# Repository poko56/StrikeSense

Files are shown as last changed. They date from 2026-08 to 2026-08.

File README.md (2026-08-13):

# StrikeSense

ระบบเซนเซอร์ IoT และวิเคราะห์แรงปะทะสำหรับกีฬามวยไทย แบบ Real-time (IoT Muay Thai Telemetry System)

---

## 📚 ศูนย์รวมเอกสาร (Documentation Index)

| หมวดหมู่ | เอกสาร | คำอธิบาย |
| :--- | :--- | :--- |
| **User Manuals** | 🧠 [คู่มือการเทรนโมเดล AI](docs/%E0%B9%80%E0%B8%97%E0%B8%A3%E0%B8%99%E0%B9%82%E0%B8%A1%E0%B9%80%E0%B8%94%E0%B8%A5.md) | ขั้นตอนการเก็บข้อมูล เทรนโมเดล และอัปโหลดเข้าสู่ระบบ |
| | 📖 [คู่มือการใช้งานระบบ](docs/usage-guide.md) | วิธีการติดตั้ง การเชื่อมต่อ Wi-Fi และการใช้งานแดชบอร์ด |
| | 🔌 [คู่มือการอัปโหลดเฟิร์มแวร์](docs/firmware-upload-guide.md) | ขั้นตอนการแฟลชเฟิร์มแวร์ลง ESP32-S3 และ ESP32-C3 |
| | 🔒 [คู่มือ Motion Capture & HTTPS/WSS](docs/motion-capture-https.md) | การตั้งค่า Secure Origin และใบรับรองความปลอดภัย HTTPS |
| **Technical Specs** | 📡 [Protocol Spec](docs/protocol.md) | โครงสร้างแพ็กเกจข้อมูล ESP-NOW และ WebSocket (400Hz) |
| | 🔗 [API Spec](docs/api.md) | REST / WebSocket APIs สำหรับรับส่งข้อมูลแดชบอร์ด |
| | 🤖 [AI Model Technical Guide](docs/ai-model-guide.md) | สถาปัตยกรรม 1D-CNN และระบบคลาสสิฟายท่าทาง |
| | 💻 [Code Walkthrough](docs/code-walkthrough.md) | อธิบายโครงสร้างซอร์สโค้ด และสถาปัตยกรรมซอฟต์แวร์ |
| **Reports & Briefs** | ✨ [System Features](docs/features.md) | รายละเอียดคุณสมบัติ และเกณฑ์การวัดผล |
| | 📊 [AI Presentation Brief](docs/ai-presentation-brief.md) | ข้อมูลสรุปสเปกโครงการสำหรับนำเสนอ |
| | 🛠️ [HTTPS/WSS Debug Guide](docs/ai-handoff-https-wss-debug.md) | ขั้นตอนและวิธีแก้ไขปัญหาการเชื่อมต่อ |
| | 📄 [Progress Report (HTML)](docs/progress-report.html) / [(PDF)](docs/StrikeSense-Progress-Report.pdf) | รายงานความก้าวหน้าโครงการ StrikeSense |

---

## Architecture

```
┌──────────────┐   ESP-NOW   ┌──────────────┐  WiFi AP   ┌──────────────┐
│  Strike Node │ ──400Hz──▶  │  Main Node   │ ─WebSocket▶│  Dashboard   │
│ ESP32-C3     │             │  ESP32-S3    │            │  (Browser)   │
│  + BMI160    │             │  + SD Card   │            └──────────────┘
└──────────────┘             │              │  ┌─────────────┐
       (×2)                  │              │─▶│  AI Team    │
                             └──────────────┘  │  (PC/Cloud) │
                                               └─────────────┘
```

## Project Structure

```
firmware/
  shared/         # Protocol header shared between nodes
  strike-node/    # ESP32-C3 + BMI160 IMU firmware (400Hz ESP-NOW)
  main-node/      # ESP32-S3 hub firmware + embedded PROGMEM dashboard (dashboard_ui.h)
dashboard/        # Web UI source (Vite + Vanilla JS modular source)
ml_pipeline/      # 1D-CNN training, TF.js export & parity verification
tools/            # Cert setup, MediaPipe asset downloader & simulator scripts
hardware/         # PCB + Enclosure 3D CAD files
docs/             # Full system documentation & technical specs
```

## System Status

> [!WARNING]
> **หมายเหตุเกี่ยวกับ Motion Capture (กล้อง):** ปัจจุบันฟีเจอร์ Motion Capture (การใช้กล้องประมวลผล MediaPipe Pose 3D) **ยังไม่สามารถใช้งานได้** (ยังอยู่ในช่วงพัฒนา) ระบบรองรับการวัดผลสดและการวิเคราะห์แรงปะทะผ่านเซนเซอร์ IMU (400Hz) และโมเดล AI เป็นหลัก

| Component | State | Description |
|---|---|---|
| Protocol & Shared Headers | ✅ Done | ESP-NOW 400Hz packet protocol, 4 body slots (protocol.h) |
| Main Node Firmware | ✅ Done | ESP32-S3 AP, HTTPS/WSS, SD card logger, REST API, PROGMEM Web Server |
| Strike Node Firmware | ✅ Done | ESP32-C3 + BMI160, I2C 400kHz, battery measurement & deep sleep |
| Web Dashboard UI | ✅ Done | Real-time 4-slot telemetry, In-browser TF.js AI, Strike physics |
| SD Card Data Logger | ✅ Done | CSV session logging, session manager API & web replay |
| AI Pipeline & Bridge | ✅ Done | 1D-CNN training (`train_model.py`), `retrain.sh`, dynamic SD model storage |
| Motion Capture (Camera Pose) | ⚠️ Not Working | ฟีเจอร์กล้องจับพิกัดโครงร่างยังไม่พร้อมใช้งาน (อยู่ระหว่างพัฒนา) |
| Custom PCB / Enclosure | ⏳ Active | Hardware enclosure and PCB layout files |

## Quick Start (Build & Flash Firmware)

### 1. Build Dashboard UI assets into PROGMEM C-header (`firmware/main-node/dashboard_ui.h`)
```bash
cd dashboard
npm install
npm run build
```

### 2. Compile and flash Main Node firmware

####  สำหรับ macOS:
```bash
cd ../firmware
CLI="/Applications/Arduino IDE.app/Contents/Resources/app/lib/backend/resources/arduino-cli"
FQBN="esp32:esp32:esp32s3:PSRAM=opi,FlashSize=8M,PartitionScheme=default_8MB,CDCOnBoot=cdc,UploadSpeed=921600"
"$CLI" compile --fqbn "$FQBN" main-node
"$CLI" upload -p /dev/cu.usbmodem101 --fqbn "$FQBN" main-node
```

#### ⊞ สำหรับ Windows (Command Prompt / PowerShell):
```cmd
cd ..\firmware
set CLI="C:\Program Files\Arduino IDE\resources\app\lib\backend\resources\arduino-cli.exe"
set FQBN=esp32:esp32:esp32s3:PSRAM=opi,FlashSize=8M,PartitionScheme=default_8MB,CDCOnBoot=cdc,UploadSpeed=921600
%CLI% compile --fqbn %FQBN% main-node
%CLI% upload -p COM3 --fqbn %FQBN% main-node
```

เชื่อม Wi‑Fi `StrikeSense` (pwd: `muaythai123`) แล้วเปิด secure origin ตาม
[คู่มือ motion capture / HTTPS](docs/motion-capture-https.md):
`https://192.168.4.1` สำหรับ Local CA หรือ `https://<hostname>` สำหรับ
Let's Encrypt (ชื่อใน `/tls/hostname.txt`). URL นี้จำเป็นสำหรับกล้องโทรศัพท์และ
WSS.

## เทรนโมเดลจับท่า (AI Model Retraining)

คำสั่งสำหรับนำเข้า CSV และเทรนโมเดลใหม่บนคอมพิวเตอร์:

- **macOS / Linux**: `./ml_pipeline/retrain.sh`
- **Windows**: `.\ml_pipeline\retrain.bat` (หรือดับเบิลคลิกไฟล์ `retrain.bat`)

---

## รายละเอียดโครงการ (Project Details)

### 1. หลักการและเหตุผล (Introduction)
```text
กีฬามวยไทยเป็นศิลปะการต่อสู้ที่ต้องอาศัยความเร็ว ความแม่นยำ และพละกำลัง ในปัจจุบันการฝึกซ้อมยังคงพึ่งพาสัญชาตญาณและประสบการณ์ของ
เทรนเนอร์เป็นหลัก โครงการนี้จึงมีแนวคิดในการนำเทคโนโลยี และปัญญาประดิษฐ์แบบฝังตัว มาพัฒนาระบบสวมใส่อัจฉริยะ (Wearable Device) เพื่อ
ดักจับข้อมูลทางฟิสิกส์ระหว่างการออกอาวุธ ได้แก่ ความเร็ว ความหน่วง และแรงกระแทก โดยแปลงข้อมูลดิบให้เป็นสถิติเชิงตัวเลขที่จับต้องได้
แสดงผลแบบ Real-time เพื่อยกระดับประสิทธิภาพการฝึกซ้อมและการวิเคราะห์สมรรถภาพของนักกีฬา
```

### 2. วัตถุประสงค์ของโครงการ (Objectives)
```
1. เพื่อออกแบบและผลิตชิ้นงานต้นแบบ (Prototype) เซนเซอร์สวมใส่สำหรับนักกีฬามวยไทย
2. เพื่อพัฒนาระบบประมวลผลปัญญาประดิษฐ์ฝังตัว ในการแยกแยะรูปแบบการออกอาวุธ (หมัดตรง, หมัดฮุค, ศอก, เตะ และแทงเข่า)
3. เพื่อพัฒนาระบบรับส่งข้อมูลไร้สายความหน่วงต่ำ (Low-Latency) และหน้ากระดานแสดงผล (Web Dashboard) แบบ Real-time
```

### 3. ภาพรวมสถาปัตยกรรมระบบ (System Overview)
#### ระบบถูกออกแบบมาเพื่อรองรับการเคลื่อนไหวความเร็วสูงในกีฬาต่อสู้ โดยแบ่งการทำงานเป็น 3 ส่วนหลัก:
```
• ชุดเซนเซอร์สวมใส่ : ทำหน้าที่ดักจับข้อมูลทางฟิสิกส์ (ความเร็ว, ความเร่ง, ทิศทาง) ด้วยความถี่สูง และส่งข้อมูลดิบแบบไร้สายทันที เพื่อให้
ตัวอุปกรณ์มีน้ำหนักเบาและตอบสนองไวที่สุด
• ระบบศูนย์กลางประมวลผล : ทำหน้าที่เป็นสมองกลส่วนกลาง รับข้อมูลจากเซนเซอร์ทุกจุดเพื่อนำเข้าสู่โมเดลปัญญาประดิษฐ์ (AI) ในการ
วิเคราะห์รูปแบบการปะทะ คำนวณความแรง และจำแนกประเภทอาวุธ
• ระบบแสดงผล : นำข้อมูลที่ผ่านการวิเคราะห์แล้วมาแสดงผลในรูปแบบกราฟิกและสถิติผ่านเว็บบราวเซอร์
```

### 4. คุณสมบัติเด่นของระบบ (Key Features & Specifications)
```
• ด้านฮาร์ดแวร์ (Hardware Design): อุปกรณ์สวมใส่ถูกออกแบบแผงวงจรให้มีขนาดกะทัดรัด บรรจุในตัวเรือนที่ใช้วัสดุโพลิเมอร์ยืดหยุ่น
ทนทานต่อแรงกระแทก เพื่อความปลอดภัยสูงสุดของผู้สวมใส่และคู่ซ้อม
• ด้านปัญญาประดิษฐ์ (AI & Algorithm): ระบบใช้อัลกอริทึมจำแนกรูปแบบท่าทาง ที่ถูกปรับจูนมาสำหรับกีฬาต่อสู้โดยเฉพาะ เพื่อความ
แม่นยำในการแยกแยะอาวุธ
• ด้านการสื่อสาร (Data Transmission): ใช้โปรโตคอลการรับส่งข้อมูลไร้สายความหน่วงต่ำ ร่วมกับการบริหาร
• จัดการคิวข้อมูลแบบขนาน (Multi-threaded Processing) ทำให้สามารถแสดงผลสถิติบนหน้าจอได้ทันทีโดยไม่เกิดความล่าช้า
```
#### ด้านการวิเคราะห์และแสดงผลข้อมูล (Data Analytics & Insights Dashboard): หน้าจอแสดงผลถูกออกแบบมาเพื่อเปลี่ยนข้อมูลตัวเลขทาง
ฟิสิกส์ให้กลายเป็นสถิติเชิงลึกที่เข้าใจง่ายสำหรับโค้ชและนักกีฬา โดยจะครอบคลุมการแสดงผลข้อมูลดังต่อไปนี้:

##### หน้าจอหลักสำหรับการฝึกซ้อม (Real-time Training Dashboard):
```
• ตัววัดพลังหมัดและหน้าแข้ง (Live Impact Power): แสดงเกจวัดระดับความรุนแรงของการปะทะในรูปแบบเปอร์เซ็นต์ หรือหน่วยดัชนีชี้
วัด (Score) ทันทีเมื่อเกิดการปะทะเป้าหมาย
• ระบบไฟสถานะระบุท่าทาง (Strike Indicator): แสดงสัญลักษณ์หรือกราฟิกรูปท่าทางมวยไทยบนหน้าจอที่จะสว่างขึ้นตามอาวุธที่นักมวย
ออกจริง (เช่น ตัวอักษรคำว่า "KNEE" หรือ "HOOK" จะกะพริบขึ้นมาทันทีเมื่อนักมวยแทงเข่าหรือฮุคเข้าเป้า)
• ตัวพล็อตแนวกราฟความเร็ว (Real-time Velocity Graph): เส้นกราฟความชันที่พลอตสดบนหน้าจอเพื่อแสดงทิศทาง ความเร่ง และ
การทรงตัวของแขนขาในขณะออกอาวุธ
```
##### หน้าจอสรุปผลและสถิติเชิงลึก (Performance & Metrics Analytics):
```
• สรุปอัตราส่วนอาวุธ (Striking Distribution Pie Chart): กราฟวงกลมแสดงสัดส่วนการใช้อาวุธของการซ้อมในรอบนั้นๆ (ตัวอย่าง: ใช้
หมัด 40%, เตะ 30%, เข่า 30%) ช่วยให้โค้ชวิเคราะห์ได้ว่านักมวยใช้ร่างกายสมดุลหรือไม่ หรือติดพฤติกรรมการออกอาวุธแบบใดแบบหนึ่ง
มากเกินไป
• ตัวนับจำนวนครั้งรวมแยกประเภท (Strike Counter): กล่องตัวเลขดิจิทัลขนาดใหญ่สรุปยอดรวมการออกอาวุธ เช่น หมัดตรง: 52 ครั้ง,
หมัดฮุค: 18 ครั้ง, เตะ: 35 ครั้ง, แทงเข่า: 20 ครั้ง
• ดัชนีคะแนนพละกำลังสูงสุด (Peak Power Record): บันทึกสถิติ "ที่สุดของการซ้อม" เช่น อาวุธที่รุนแรงที่สุดในรอบวัน (Max Impact)
เกิดขึ้นในนาทีที่เท่าไหร่ และเป็นอาวุธประเภทใด
• ตัววัดความเสถียรและความทนทาน (Stamina & Consistency Tracker): แสดงกราฟเปรียบเทียบความแรงตั้งแต่หมัดแรกจนถึงหมัด
สุดท้าย เพื่อวิเคราะห์ว่าเมื่อเวลาผ่านไป นักมวยแรงตกหรือไม่ หรือยังคงรักษาความรุนแรงของการปะทะได้สม่ำเสมอเพียงใด
```

### 5. ขอบเขตการดำเนินงาน (Scope of Work) - Phase 1
สำหรับการพัฒนาในเฟสที่ 1 (Proof of Concept) จะครอบคลุมปริมาณงานดังต่อไปนี้:
```
• ผลิตชุดเซนเซอร์สวมใส่: จำนวน 2 ชุด (สามารถกำหนดจุดติดตั้งได้ เช่น มือและหน้าแข้ง)
• ผลิตระบบศูนย์กลางประมวลผล: จำนวน 1 ชุด
```

### 6. รายการส่งมอบ (Deliverables)
```
1. ชิ้นงานฮาร์ดแวร์ต้นแบบ (อุปกรณ์สวมใส่ 2 ชุด และ ตัวรับสัญญาณ 1 ชุด)
2. สิทธิ์การเข้าใช้งานระบบหน้าจอแสดงผล (Web Dashboard) ตลอดช่วงระยะเวลาการทดสอบ
```

### 7. เงื่อนไขและข้อจำกัดของโครงการต้นแบบ (Terms & Conditions)
```
• ด้านความแม่นยำ: ชิ้นงานเป็นเวอร์ชันทดสอบแนวคิด (Proof of Concept) ความแม่นยำในการจำแนกท่าทางด้วย AI จะอยู่ในเกณฑ์เฉลี่ย
80-85% ภายใต้สภาวะการควบคุมการทดสอบ
• การปรับแก้ชิ้นงาน: ครอบคลุมการปรับแก้ไขการออกแบบโครงสร้างภายนอกของตัวอุปกรณ์ (Enclosure Design) สูงสุดจำนวน 2 ครั้ง
• สิทธิบัตรและทรัพย์สินทางปัญญา (Intellectual Property): การส่งมอบนี้ครอบคลุมเฉพาะชิ้นงานต้นแบบทางกายภาพและสิทธิ์การใช้
งานแพลตฟอร์มเท่านั้น ไม่รวมถึงการส่งมอบซอร์สโค้ด (Source Code), อัลกอริทึมวิเคราะห์ข้อมูล (AI Model), รูปแบบลายวงจร
อิเล็กทรอนิกส์ (PCB Gerber) และไฟล์พิมพ์เขียวสามมิติ (3D CAD) หากมีความประสงค์นำไปใช้ในการผลิตเชิงพาณิชย์ จะต้องมีการทำ
ข้อตกลงและประเมินมูลค่าลิขสิทธิ์เพิ่มเติมในเฟสถัดไป
```

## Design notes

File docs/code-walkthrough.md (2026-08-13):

# StrikeSense — Code Walkthrough (เข้าใจโค้ดแบบละเอียด)

เอกสารนี้เดินตาม **เส้นทางของข้อมูล 1 sample** ตั้งแต่เซนเซอร์จนถึงหน้าจอ แล้วต่อด้วย
**Data Logger → ML → Inference** เพื่อให้เห็นภาพว่าโค้ดแต่ละไฟล์ต่อกันอย่างไร

เอกสารอ้างอิงอื่น: [README](../README.md) (ภาพรวม) · [protocol.md](protocol.md) (ESP-NOW) · [api.md](api.md) (REST/WS) · [features.md](features.md) (ฟีเจอร์ UI)

---

## 0. แผนที่ระบบ 3 ส่วน

```
Strike Node (ESP32-C3)        Main Node (ESP32-S3)              Dashboard (Browser)
─────────────────────        ────────────────────              ───────────────────
IMU 400Hz ─┐                  ESP-NOW RX ─┐                     WebSocket ─┐
           │ pack 8 samples              │ queue → loop()                 │ decodeFrame()
           └─ ESP-NOW ──────▶  onRecv() ─┘  ├─ SD logger        ingestBatch()─┤
                                            ├─ WS broadcast ───▶ analyzer ────┤
                                            └─ counters         render / logger
```

- **Strike Node** = [`firmware/strike-node/strike-node.ino`](../firmware/strike-node/strike-node.ino) — อ่าน IMU, แพ็กเป็น packet, ยิง ESP-NOW
- **Main Node** = [`firmware/main-node/main-node.ino`](../firmware/main-node/main-node.ino) — ตัวรวมศูนย์ (ไฟล์เดียว, แบ่งเป็น `namespace`)
- **Dashboard** = [`dashboard/src/*.js`](../dashboard/src) — Vanilla JS แบบ modular
- **สัญญา (contract)** ที่ผูกทุกส่วน = โครงสร้าง packet ใน [`firmware/shared/protocol.h`](../firmware/shared/protocol.h)

---

## 1. ฝั่งเฟิร์มแวร์ Main Node — แบ่งด้วย `namespace`

`main-node.ino` เป็นไฟล์เดียวแต่จัดระเบียบด้วย namespace แต่ละอันคือ "โมดูล" ที่มีหน้าที่ชัดเจน:

| namespace | หน้าที่ | state สำคัญ |
|---|---|---|
| `Session` | จำ node, นับ packet, จับ session start/stop | `g_nodes[]`, `g_stats` |
| `EspNowRx` | รับ ESP-NOW ใน callback → ยัดเข้า FreeRTOS queue | `g_queue` |
| `EspNowTx` | ยิง time-sync + คำสั่งไป node | broadcast peer |
| `SdLogger` | เขียน CSV ลง SD แบบ buffered | `g_buf[16KB]` |
| `StatusLed` | ไฟ NeoPixel บอกสถานะ | state machine |
| `WebServerApp` | HTTP + WebSocket + REST | `g_http`, `g_ws` |

**ทำไมต้องใช้ queue?** — ESP-NOW `onRecv()` รันใน **ISR context** (interrupt) ห้ามทำงานหนัก/ห้าม block
ดังนั้น callback แค่ก๊อปข้อมูลใส่ queue แล้วจบ ส่วนงานหนัก (เขียน SD, ส่ง WS) ไปทำใน `loop()` ปกติ

### 1.1 เส้นทางของ 1 packet ในเฟิร์มแวร์

```c
// (1) ISR: รับ ESP-NOW → ก๊อปเข้า queue เท่านั้น  [EspNowRx::onRecv]
static void onRecv(const esp_now_recv_info_t* info, const uint8_t* data, int len) {
    if (data[1] == PKT_IMU_BATCH) {
        ImuFrame frame;                              // stack struct
        memcpy(frame.samples, pkt->samples, ...);    // ก๊อป 8 samples
        xQueueSendFromISR(g_queue, &frame, nullptr); // ← ส่งต่อ ไม่ประมวลผลใน ISR
    }
}

// (2) loop(): drain queue → 3 ปลายทาง  [void loop]
while (drained < 32 && EspNowRx::nextFrame(frame, 0)) {
    Session::noteImuFrame(frame.sampleCount);        // นับสถิติ
    if (Session::isActive()) SdLogger::logFrame(frame); // เขียน SD (ถ้ากำลัง record)
    WebServerApp::broadcastImuFrame(frame);          // ส่งเข้า WebSocket ทุก client
}
```

### 1.2 การ broadcast เข้า WebSocket — จุดที่กำหนด "รูปแบบ binary frame"

`WebServerApp::broadcastImuFrame()` แพ็ก frame เป็น binary 16-byte header + N×12-byte samples:

```c
buf[0]=0x01; buf[1]=slot; buf[2]=sampleCount; buf[3]=rssi;
memcpy(buf+4,  &seq, 4);
memcpy(buf+8,  &recvMs, 4);
memcpy(buf+12, &nodeUs, 4);
memcpy(buf+16, samples, sampleCount*12);   // ax,ay,az,gx,gy,gz = int16 ×6
g_ws.binaryAll(buf, 16 + sampleCount*12);
```

> ⚠️ **นี่คือ contract กับ dashboard** — ถ้าแก้ layout นี้ ต้องแก้ `decodeFrame()` ใน `ws.js` ให้ตรงกัน

### 1.3 Dashboard ถูก serve จากไหน

`registerRoutes()` ผูก `/` และ `/index.html` เข้ากับ `DASHBOARD_HTML` (PROGMEM string ใน `dashboard_ui.h`):

```c
auto sendDashboard = [](AsyncWebServerRequest* req) {
    req->send(req->beginResponse_P(200, "text/html", DASHBOARD_HTML));
};
```
`dashboard_ui.h` เป็นไฟล์ที่ **generate อัตโนมัติ** จาก `npm run build` (ห้ามแก้มือ)

---

## 2. ฝั่ง Dashboard — โมดูล Vanilla JS

| ไฟล์ | หน้าที่ |
|---|---|
| [`main.js`](../dashboard/src/main.js) | Entry — ต่อ state ↔ ws ↔ ui ↔ timer ↔ logger ↔ AI classifier เข้าด้วยกัน |
| [`ws.js`](../dashboard/src/ws.js) | ถอด binary WebSocket frame → sample objects + reconnect |
| [`analyzer.js`](../dashboard/src/analyzer.js) | ตรวจจับ "หมัด" จากสัญญาณ (threshold + refractory) |
| [`motioncapture.js`](../dashboard/src/motioncapture.js) | โหลดโมเดล TensorFlow.js AI *(ฟีเจอร์กล้อง MediaPipe Pose ยังไม่เปิดใช้งาน)* |
| [`physics.js`](../dashboard/src/physics.js) | คำนวณฟิสิกส์แรงปะทะ (Live Impact Power, Velocity, Kinetic Energy) |
| [`strikescore.js`](../dashboard/src/strikescore.js) | ประเมินดัชนีคะแนนความแม่นยำและแรงปะทะ (0–100 Strike Score) |
| [`posemath.js`](../dashboard/src/posemath.js) | เวกเตอร์และฟังก์ชันคำนวณเรขาคณิตของข้อต่อร่างกาย 3D |
| [`rigclock.js`](../dashboard/src/rigclock.js) | ตัวซิงก์เวลาความละเอียดสูงระหว่าง IMU และกล้อง MediaPipe |
| [`rigorigin.js`](../dashboard/src/rigorigin.js) | ตัวตั้งพิกัดอ้างอิงของจุดกำเนิดและทิศทางเซนเซอร์ |
| [`state.js`](../dashboard/src/state.js) | store กลาง + pub/sub (`subscribe`/`scheduleRender`) |
| [`ui.js`](../dashboard/src/ui.js) | render DOM จาก state |
| [`timer.js`](../dashboard/src/timer.js) | round timer / boxing stopwatch |
| [`logger.js`](../dashboard/src/logger.js) | **Data Logger** — เก็บ raw IMU + label → CSV |

### 2.1 `decodeFrame()` — ตรงข้ามกับ `broadcastImuFrame()`

```js
// ws.js — อ่าน int16 little-endian แล้วหารด้วย scale ให้เป็นหน่วยจริง
const ACCEL_LSB_PER_G  = 2048;    // ±16g range
const GYRO_LSB_PER_DPS = 16.4;    // ±2000 dps range
samples[i] = {
  ax: dv.getInt16(off,   true) / ACCEL_LSB_PER_G,   // g
  gx: dv.getInt16(off+6, true) / GYRO_LSB_PER_DPS,  // deg/s
  ...
};
logSensorData(samples[i], slot);   // ← ป้อน Data Logger (no-op ถ้าไม่ได้ record)
ingestBatch({ slot, samples, ... }); // ← ป้อน analyzer + state
```

### 2.2 State เป็น pub/sub

`ws`/`analyzer`/`timer` เขียนลง `state` แล้วเรียก `scheduleRender()` → `subscribe(renderAll)` ใน `main.js`
ทำให้ทุกอย่าง render ผ่าน `requestAnimationFrame` loop เดียว (ไม่ render ซ้ำซ้อน)

---

## 3. Data Logger — โหมดเก็บข้อมูลฝึก AI (developer mode)

**เป้าหมาย:** เก็บ raw IMU + label ท่า → CSV → เอาไปเทรนบนคอมพิวเตอร์

### 3.1 การ wire 3 จุด
```
main.js   : initLogger()              // ผูกปุ่ม/ค่า panel ตอน bootstrap
ws.js     : logSensorData(sample,slot)// เรียกทุก sample @400Hz
index.html: <select id="strikeLabel"> // dropdown ท่าแบบจัดกลุ่ม
```

### 3.2 Label เข้ารหัสแบบ "หลักสิบ" (tens-scheme)
```
10-13 หมัด PUNCH   (10 Jab, 11 Cross, 12 Hook, 13 Uppercut)
20-25 ศอก ELBOW    (ตี/ตัด/งัด/พุ่ง/กระทุ้ง/กลับ)
30-33 เข่า KNEE    (ตรง/เฉียง/ตัด/ลอย)
40-44 เตะ KICK     (ตรง/เฉียง/ตัด/กลับ/เหวี่ยงกลับ)
50-52 ถีบ TEEP     (ตรง/ข้าง/กลับหลัง)
```
**กุญแจสำคัญ:** `coarse_class = floor(label/10) - 1` → 0..4 (หมัด/ศอก/เข่า/เตะ/ถีบ)
ทำให้ logger เก็บ **ละเอียด** แต่โมเดลเทรนได้ทั้งแบบ **หยาบ 5 คลาส** และแบบ **ละเอียด ~20 ท่าย่อย**

### 3.3 CSV ที่ได้
```
ax,ay,az,gx,gy,gz,slot,label
-0.1230,0.9840,0.0210,12.300,-4.100,0.800,2,41
                                        │  └ fine label (41 = เตะเฉียง)
                                        └ slot: 0=ว่าง 1=L-hand 2=R-hand 3=L-shin 4=R-shin
```
`slot` มาจาก frame header (บอกว่าอวัยวะไหนออกอาวุธ) ใช้กันไม่ให้ window เทรนข้ามแขน/ขา

---

## 4. ML Pipeline — [`ml_pipeline/train_model.py`](../ml_pipeline/train_model.py)

```
CSV หลายไฟล์ → load_dataset()          (แปะ file_id กันข้ามไฟล์)
             → make_windows()          (sliding window ไม่ข้าม file/slot/class)
             → standardise             (mean/std จาก train เท่านั้น)
             → build_model()           (1D-CNN: Conv×3 → GAP → Dense)
             → evaluate                (accuracy + confusion_matrix.png)
             → export_tfjs_json()      (strike_web_model_fine.json สำหรับเบราว์เซอร์)
             → export_header()         (strike_model_fine.h สำหรับ C++ fallback)
```

---

## 5. การวิเคราะห์โมเดลแบบ In-Browser TensorFlow.js 🧠

ระบบ StrikeSense ใช้สถาปัตยกรรม **In-Browser Machine Learning (1D-CNN + TensorFlow.js)**:

1. **การโหลดโมเดลแบบไดนามิก**:
   - เมื่อเปิดแดชบอร์ด `motioncapture.js` จะดึงไฟล์โมเดลจาก `/api/model` บน Main Node SD Card (`/models/strike_web_model_fine.json`)
   - ผู้ใช้สามารถอัปโหลดโมเดลใหม่ผ่าน Web Dashboard ได้ทันทีโดยไม่ต้อง re-flash ESP32

2. **การทำงานของ AI Engine**:
   - สัญญาณ IMU ความถี่ 400Hz ถูกตัดหน้าต่าง (sliding window 100 samples / 250ms)
   - โมเดล 1D-CNN ทำงานร่วมกับ **Gaussian priors (`physics.js`)** และ **Strike Score Calculator (`strikescore.js`)** ในการจำแนกประเภทท่าและประเมินพลังหมัด/แข้ง

---

## 6. สรุป contract ที่ห้ามหลุด (ถ้าแก้ ต้องแก้ทั้งคู่)

| Contract | ฝั่ง A | ฝั่ง B |
|---|---|---|
| ESP-NOW packet layout | `protocol.h` / strike-node | `onRecv()` main-node |
| WebSocket binary frame | `broadcastImuFrame()` | `decodeFrame()` ws.js |
| IMU scale (2048/16.4) | strike-node config | `ws.js` + `train_model.py` |
| Label tens-scheme | `index.html` optgroup | `logger.js` + `train_model.py` |
| Model JSON Format | `train_model.py` export | `motioncapture.js` + `/api/model` |

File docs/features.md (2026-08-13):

# StrikeSense — Feature Catalog

> สรุปฟีเจอร์ทั้งหมดของ Web Dashboard (เวอร์ชันปัจจุบัน · v0.2)
> Dashboard ฝัง PROGMEM อยู่ใน Main Node firmware · เปิดผ่าน
> secure origin: `https://192.168.4.1` สำหรับ Local CA หรือ
> `https://<hostname>` สำหรับ Let's Encrypt หลัง provision certificate (ดู
> [motion-capture-https](motion-capture-https.md))
> Dev mode: `cd dashboard && npm run dev` → `http://localhost:5173/?demo=1`

---

## ภาพรวม

Dashboard เป็น Single-Page App (Vite · vanilla JS · PROGMEM embedded) ที่:
1. รับข้อมูล IMU ความถี่ 400 Hz จาก Strike Nodes ครบทั้ง 4 จุด (มือซ้าย, มือขวา, แข้งซ้าย, แข้งขวา) ผ่าน WebSocket
2. วิเคราะห์และตรวจจับการออกอาวุธแบบ real-time ด้วย **In-browser TensorFlow.js 1D-CNN AI Model** ร่วมกับ **Gaussian priors physics engine**
3. *[ยังไม่พร้อมใช้งาน]* **MediaPipe Pose 3D Landmarker (Dual Camera mode)** — ฟีเจอร์กล้องจับพิกัดโครงร่างยังไม่เปิดใช้งาน (อยู่ระหว่างพัฒนา)
4. คำนวณ performance metrics (Live Impact Power, Velocity Graph, Strike Score 0-100, Stamina Tracker)
5. ควบคุมการบันทึก session, รอบการซ้อม (Round timer), และจัดการคลังโมเดล AI (`/api/models`) บน SD Card

**Design**: "Fight Card" — ฟอนต์ Bebas Neue + IBM Plex Mono, สี ink/paper + accent แดง Muay Thai, hairline borders, asymmetric 3-rail layout — ไม่ใช่ generic glass-morphism dashboard

---

## 1 · Live Monitoring

| ฟีเจอร์ | รายละเอียด | ที่อยู่ |
|---|---|---|
| Connection pill | LIVE WS / OFFLINE / DEMO MODE — สีเขียว/แดง/น้ำเงิน | Topbar |
| Live IMU stream | ax, ay, az, gx, gy, gz ที่ 400 Hz แปลงเป็น g/°·s⁻¹ แล้ว | WebSocket frame |
| Sample rate วัดจริง | Hz วัดสด ทุก 1 วินาที | System tab |
| Bandwidth | kbps WS payload จริง | System tab |
| Sample latency check | recvTimestampMs ใน header เปรียบ wall clock | (เห็นใน packet) |
| RSSI ต่อ node | dBm + bar graph 4 ขั้น | Sensors tab |
| Battery % ต่อ node | bar + warning เมื่อ <20% | Sensors tab |
| WS clients ออนไลน์ | จำนวน clients ที่ดู dashboard | System tab |
| Uptime / Heap / PSRAM | จาก `/api/status` polling 1.5s | Topbar + System |

## 2 · Strike Detection & Analysis

| ฟีเจอร์ | รายละเอียด |
|---|---|
| Threshold detector | \|a\| > `thresholdG` (default 3.0g, ปรับได้ live) |
| Per-slot refractory | กันนับซ้ำ — default 250ms ปรับได้ |
| Heuristic classification | jab / cross / hook / uppercut / elbow / kick / roundhouse / knee / push |
| Per-strike data | id, slot, type, peakG, peakDps, recoverMs, sessionMs, round |
| Force histogram | 4 ช่วง: 1-3g / 3-5g / 5-10g / 10+g |
| Strike distribution | นับตาม type — bar graph เรียงจากมาก→น้อย |
| Sparkline ต่อ slot | canvas waveform 3 วินาทีล่าสุด พร้อมเส้น threshold |

## 3 · Body Diagram (Hit Zones)

| โหมด | รายละเอียด |
|---|---|
| **LIVE** | 4 zones (LH/RH/LS/RS) เปลี่ยนสีตามสถานะ: dim → assigned → live (cyan) → hit (flash แดง 250ms) |
| **HEATMAP** | สีแดงเข้ม 5 ระดับ ตามจำนวนหมัดสะสมต่อ slot |
| Click-to-assign | คลิก zone → assign node ว่างไปที่ slot นั้น (POST `/api/nodes/assign`) |
| Belt | แถบแดง muay thai ที่เอว — ไม่ใช่ interactive |

## 4 · Round Timer (Boxing Style)

| ฟีเจอร์ | รายละเอียด |
|---|---|
| Circular dial | SVG ring แสดง progress ของ phase ปัจจุบัน + tick countdown |
| Presets | 3×3 / 5×3 / 3×2 / 12×3 / Stopwatch (free) / Custom |
| Phases | idle → work → rest → work → ... → done — สลับอัตโนมัติ |
| Auto-rec | checkbox: เริ่ม REC ทุกครั้งที่เข้า work, หยุดเมื่อ done |
| Manual controls | RESET, SKIP, click dial = start |
| Stopwatch mode | นับขึ้น ไม่มีรอบ/พัก — สำหรับ shadow / freestyle |
| Visual rest indicator | สี dial เปลี่ยนเป็น amber ตอน rest |

## 5 · Session Recording

| ฟีเจอร์ | รายละเอียด |
|---|---|
| REC button | ปุ่มแดงใหญ่ใต้ dial — toggle start/stop |
| Athlete name | input + datalist เก็บ 10 ชื่อล่าสุด |
| Drill type | shadow / pad / bag / spar / free |
| Session timer | นับเวลาตั้งแต่เริ่ม (anchor จาก backend durationMs) |
| Coach markers | ปุ่ม `+ MARKER` (หรือกด M) ใส่ note timestamped |
| REC pill | บน topbar — STANDBY / REC LIVE / REST |
| SD logging status | warning toast ถ้า SD card ไม่พร้อม |

## 6 · Performance Metrics

| Metric | หน่วย | คำนวณจาก |
|---|---|---|
| **Peak G** | g | max ของ peak |
| **Avg G** | g | mean ของ peakG |
| **Strikes** | count | จำนวน strike |
| **SPM** (Strikes Per Minute) | /min | strikes / minutes since start |
| **Time-on-target** | % | % ของ 30s ล่าสุดที่ rms > threshold·0.25 |
| **Work** | kJ | Σ 0.5·m·v² (mass: arm 4kg / leg 12kg) |
| **Asymmetry L:R** | ratio + bar | leftCount / (left+right) |
| **Fatigue Index** | % + label | (first half avg - second half avg) / first |
| **Power CV** | % | std/mean ของ peakG (consistency) |
| **Session duration** | hh:mm:ss | wall - startedAtMs |

## 7 · Round-by-Round Summary

| ข้อมูลต่อยก | รายละเอียด |
|---|---|
| Strikes | จำนวนหมัดในยกนั้น |
| Peak G | peak ของยก |
| Avg G | average ของยก |
| Fatigue % | decay ภายในยก (first half vs second half) |
| Asymmetry | L vs R ในยก |
| Current row | highlight ยกที่กำลัง work อยู่ (สีแดงอ่อน) |

## 8 · Session Timeline Strip

| ฟีเจอร์ | รายละเอียด |
|---|---|
| Horizontal strip | span = ระยะเวลา session (อย่างน้อย 60s) |
| Strike dots | แท่งแนวตั้ง สีตาม slot, ความสูงตาม peakG |
| Marker triangles | สีทอง — แสดง coach markers |
| Click strike → modal | เปิด detail modal ของหมัดนั้น + neighbours |
| Axis labels | 0:00 / mid / end |

## 9 · Strike Log

| ฟีเจอร์ | รายละเอียด |
|---|---|
| Columns | #, Time, Round, Slot, Type, Peak·g, ω·°/s, Recovery·ms |
| Filter chips | ALL / LH / RH / LS / RS (กดเลข 1-4 ก็ได้) |
| Newest flash | row ล่าสุดมี animation รัศมีแดง 1 วิ |
| Click → detail modal | drill-down รายตัว |
| Slot tag | สีแยก 4 slots (cyan/orange/green/purple) |
| Clear button | ล้าง log + reset counters |
| Max 80 rows displayed | rolling buffer 500 ใน state |

## 10 · Strike Detail Modal

| ข้อมูล | รายละเอียด |
|---|---|
| Peak G, ω | ใหญ่เด่น |
| Slot | full name |
| Round | R1, R2, ... |
| Session time | hh:mm:ss ของหมัด |
| Recovery | ms ตั้งแต่หมัดก่อน |
| Neighbours | หมัด ±3 ใน slot เดียวกัน |

## 11 · Training Goals

| ฟีเจอร์ | รายละเอียด |
|---|---|
| Target strikes | ตั้งจำนวนหมัด (default 100) |
| Target peak G | peak ต่ำสุดที่ต้องทำ (default 8g) |
| Target SPM | (เก็บไว้, ใช้ขยายต่อ) |
| Progress bars | 2 แท่ง — strikes vs target, peak vs target |
| Goal status | %, "keep going", หรือ "✓ COMPLETED at hh:mm" |
| Auto-detect completion | log activity feed + lock until reset |

## 12 · Coach Markers

| ฟีเจอร์ | รายละเอียด |
|---|---|
| Add marker | ปุ่ม `+ MARKER` หรือกด M — prompt note |
| Display | บน timeline (triangle ทอง) + list ใน Sensors tab |
| Delete marker | ปุ่ม ✕ ในรายการ |
| Auto-label | "Round X · note" ถ้าไม่ใส่ |
| Session-relative time | hh:mm:ss นับจากเริ่ม session |

## 13 · Activity Feed

| Event | สี | ตัวอย่าง |
|---|----|---|
| REC start/stop | แดง | "▶ Recording started · 1738291201" |
| Round transition | แดง | "🥊 Round 2 · WORK" |
| Marker added | ทอง | "📍 Round 1 · note @ 45.2s" |
| Goal completed | เขียว | "🏆 Goal reached · 100 strikes" |
| Battery warning | amber | "🪫 Battery low: EE:01 18%" |
| Slot assign | แดง | "📍 EE:01 → Right Hand" |
| Relative time | — | "5s", "2m", "1h" |
| Cap 20 entries | — | rolling buffer |

## 14 · Sensors Management

| ฟีเจอร์ | รายละเอียด |
|---|---|
| Node card list | สด: เขียว | นิ่ง (>3s): แดง opacity 65% |
| MAC | full address |
| Slot dropdown | เปลี่ยน live → POST `/api/nodes/assign` |
| Signal | bar graph 4 ขั้น + dBm |
| Battery | bar (เขียว/amber/แดง) + % |
| RX / Gaps / FW | packets received, seq gaps, firmware version |
| Markers panel | (ใน tab เดียวกัน) |

## 15 · Session Library

| ฟีเจอร์ | รายละเอียด |
|---|---|
| List sessions | GET `/api/sessions` polling 8s |
| Search | filter by id substring |
| Stats summary | total count, total size, SD used/cap |
| Download CSV | `<a download>` → GET `/api/sessions/{id}` |
| Preview (VIEW) | modal: id, size, date, ปุ่ม download |
| Delete | confirm → DELETE `/api/sessions/{id}` |
| Compare 2 sessions | checkbox + COMPARE button → modal (id/size/date diff) |
| Sort | mod time descending |

## 16 · System & Diagnostics

| Section | รายละเอียด |
|---|---|
| **Main Node** | IP, SSID, uptime, heap free, PSRAM free, WS clients |
| **ESP-NOW** | packets RX, dropped, sample rate Hz, bandwidth kbps |
| **Detection tuning** | slider threshold (1.5-10g), refractory (100-800ms) — บันทึก localStorage |
| **SD card** | progress bar + used/free MB, สีเปลี่ยนตาม % (>70 amber, >90 red) |
| **About** | build stamp, browser UA, dashboard version |

## 17 · UI Modes

| Mode | กดที่ | บันทึก |
|---|---|---|
| Theme dark/light | ◐ icon หรือ T | localStorage |
| Body live/heatmap | seg button หรือ H | localStorage |
| Fullscreen | ⛶ icon หรือ F | runtime + Fullscreen API |
| Stopwatch mode | MODE dropdown | localStorage |

## 18 · Keyboard Shortcuts

| Key | Action |
|-----|---|
| **Space** | REC start/stop |
| **R** | Reset round timer |
| **S** | Skip phase |
| **M** | Add coach marker |
| **F** | Toggle fullscreen presentation |
| **H** | Toggle body heatmap |
| **T** | Toggle theme |
| **0** | Filter strike log: all slots |
| **1**–**4** | Filter strike log: slot 1-4 |
| **Esc** | Close modal |
| **?** หรือ **/** | Show shortcuts modal |

## 19 · Persistence (localStorage)

| Key | Value |
|-----|---|
| `ss:theme` | 'dark' \| 'light' |
| `ss:tuning` | { thresholdG, refractoryMs } |
| `ss:goals` | { targetStrikes, targetPeakG, targetSpm } |
| `ss:athlete` | last athlete name |
| `ss:athleteHistory` | array of 10 recent names → datalist |
| `ss:drill` | last drill type |
| `ss:preset` | last round preset |
| `ss:modes` | { bodyHeatmap, stopwatch } |

## 20 · Demo / Simulator Mode

เปิด `?demo=1` ใน URL:
- สร้าง 4 fake nodes (LH/RH/LS/RS, battery 18-92%)
- 3 fake sessions ใน library
- Baseline noise ทุก 1 วินาที + strike สุ่มทุก 1.1 วินาที (peak 3.5-13g)
- API ทั้งหมด stub ด้วย demoApi
- ใช้ดูว่า UI ทำงานอย่างไรโดยไม่ต้องเสียบบอร์ด

---

## เทคโนโลยี

| Layer | ใช้ |
|---|-----|
| Build | Vite 8 + `vite-plugin-singlefile` → ผลลัพธ์ 1 ไฟล์ HTML 88KB / gzip 24.5KB |
| Bundle to firmware | `dashboard/build-cpp.js` → `firmware/main-node/dashboard_ui.h` (PROGMEM string) |
| Frontend | Vanilla JS modules · no framework · ES2022 |
| Charts | SVG inline + Canvas 2D (sparklines) — ไม่ใช้ Chart.js/uPlot ใน build จริง |
| Modal | native `<dialog>` |
| Styling | Plain CSS · CSS variables theming · no SASS/Tailwind |
| Fonts | Bebas Neue, IBM Plex Mono, Inter (Google Fonts) |
| Storage | `localStorage` ตรงๆ (ผ่าน `persist.js` wrapper) |

### File structure

```
dashboard/
├── index.html              entry HTML (semantic + IDs ตรง JS)
├── style.css               design system "Fight Card" + light theme + fullscreen
├── build-cpp.js            post-build: ฝัง dist เข้า firmware header
├── vite.config.js          singleFile plugin
└── src/
    ├── main.js             entry — wires modules + persistence + keyboard
    ├── state.js            central state + subscribe / scheduleRender
    ├── api.js              REST wrapper (BASE = 192.168.4.1 บน localhost)
    ├── ws.js               binary frame decoder + reconnect backoff
    ├── analyzer.js         strike detect + metrics + per-round + markers
    ├── timer.js            round state machine + stopwatch
    ├── ui.js               render functions + DOM event wiring + modals
    ├── modal.js            native <dialog> helper
    ├── persist.js          localStorage wrapper
    └── demo.js             simulator + demoApi override
```

### REST endpoints used

| Method | Path | ใช้ทำอะไร |
|---|---|---|
| GET | `/api/status` | poll system + session snapshot (1.5s) |
| GET | `/api/nodes` | poll connected Strike Nodes (2s) |
| POST | `/api/nodes/assign` | assign slot {mac, slot} |
| POST | `/api/session/start` | start REC {athlete} → {sessionId, sdLogging} |
| POST | `/api/session/stop` | stop REC |
| GET | `/api/sessions` | list SD recordings (8s) |
| GET | `/api/sessions/{id}` | download CSV (text/csv attachment) |
| DELETE | `/api/sessions/{id}` | remove SD recording |
| WS | `/ws` | binary IMU frames (16 B header + 12 B × N samples) |

---

## ไม่รวม (intentionally skipped)

| ที่ตัด | เหตุผล |
|---|---|
| AI live classification / form score | จะใช้โมเดลจาก AI team ภายหลัง |
| Audio (bell, voice, beep) | user ระบุไม่ทำ |
| Identify LED blink / Restart node remote | ต้องเพิ่ม firmware endpoint ก่อน |
| OTA firmware update | ต้อง firmware support |
| Strike contact duration จริง | ต้องการ segment tracker ใน firmware |
| Polar chart / FFT / 3D trajectory | over-engineered สำหรับการใช้งานจริง |
| Multi-Main-Node management | scope สำหรับ 1 hub |
| Heart-rate sensor integration | ต้องการ external hardware |
| ระบบ multi-athlete พร้อมกัน | scope = 1 athlete per session |

---

## เวอร์ชัน

- **v0.1** — โครงสร้างพื้นฐาน · Premiere Pro-style UI · core polling + WS + REC
- **v0.2 (ปัจจุบัน)** — Rewrite "Fight Card" design · 16+ ฟีเจอร์ round 2:
  body diagram + heatmap, round timer, sparklines, markers, timeline strip,
  goals, per-round table, activity feed, compare, modals, persistence,
  keyboard, theme, fullscreen, stopwatch, demo mode

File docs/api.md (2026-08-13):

# StrikeSense Main Node API

Secure base URL: `https://192.168.4.1` for the Local-CA deployment, or
`https://<hostname>` for the Let's Encrypt deployment (the exact hostname in
`/tls/hostname.txt`). Use the secure origin for browser clients and camera mode.
Local CA must be installed/trusted first; a valid public certificate does not.
Legacy HTTP remains only for service compatibility and the HTTPS loopback
backend, not for secure browser use. The IP-address examples below are Local-CA
examples; replace the host and omit `--cacert` when using Let's Encrypt.

## REST Endpoints

### `GET /api/status` — system + session snapshot
```json
{
  "uptimeMs": 123456,
  "heap":     180000,
  "psram":    8200000,
  "rx":       42180,
  "dropped":  3,
  "wsClients": 2,
  "session": {
    "active":     true,
    "id":         "1738291201",
    "startedAt":  100000,
    "durationMs": 23456,
    "packets":    1900,
    "samples":    15200
  },
  "sd": {
    "ready":  true,
    "cardMB": 14800,
    "usedMB": 12,
    "rows":   15200,
    "bytes":  1024000
  }
}
```

### `GET /api/nodes` — connected Strike Nodes
```json
[
  {
    "mac":           "AA:BB:CC:DD:EE:01",
    "slot":          1,
    "rssi":          -45,
    "lastSeenMs":    12300,
    "ageMs":         200,
    "batteryPct":    87,
    "nodeUptimeMs":  100000,
    "firmware":      256,
    "packetsRx":     5000,
    "lastSeq":       5000,
    "seqGaps":       2
  }
]
```
Slot values: `0=Unassigned, 1=LeftHand, 2=RightHand, 3=LeftShin, 4=RightShin`

### `POST /api/nodes/assign`
Assign slot (1..4) to a Strike Node MAC address.
```json
{ "mac": "AA:BB:CC:DD:EE:01", "slot": 1 }
```

### `POST /api/nodes/forget`
Remove a node mapping from remembered nodes.
```json
{ "mac": "AA:BB:CC:DD:EE:01" }
```

### `POST /api/nodes/identify`
Send blink command (`PKT_CMD_IDENTIFY`) to a node to locate it physically.
```json
{ "mac": "AA:BB:CC:DD:EE:01" }
```

### `POST /api/nodes/restart`
Send restart command (`PKT_CMD_RESTART`) to a Strike Node.
```json
{ "mac": "AA:BB:CC:DD:EE:01" }
```

### `POST /api/nodes/link-reset`
Reset all ESP-NOW node bindings and slot assignments.

### `POST /api/session/start`
```json
{ "athlete": "demo", "drill": "shadow" }
```
→ `{ "sessionId": "1738291201", "sdLogging": true }`

### `POST /api/session/stop`
→ `{ "ok": true }`

### `GET /api/sessions` — list recorded sessions on SD
```json
[ { "id": "1738291201", "bytes": 1024000, "modTime": 1738291500 } ]
```

### `GET /api/session/download?id={id}` — download CSV
- Content-Type: `text/csv`
- Content-Disposition: attachment

### `DELETE /api/session/delete` — remove a session file
```json
{ "id": "1738291201" }
```

### `GET /api/logs?since={N}` — fetch recent system log ring-buffer
```json
{
  "logs": [ { "id": 12, "ts": 4500, "msg": "Node connected: LH" } ],
  "nextId": 13
}
```

### AI Model Management Endpoints

#### `GET /api/model` — get active model JSON
Returns the active TensorFlow.js model JSON stored on SD card (`/models/strike_web_model_fine.json`).

#### `GET /api/models` — list available model files
```json
{
  "active": "strike_web_model_fine.json",
  "models": [
    { "name": "strike_web_model_fine.json", "size": 142000, "active": true }
  ]
}
```

#### `POST /api/models?name={filename}` — upload a new TF.js model JSON
Uploads model payload to SD card under `/models/{filename}`.

#### `POST /api/models/activate?name={filename}` — set active model
```json
{ "ok": true, "active": "strike_web_model_fine.json" }
```

#### `DELETE /api/models/delete?name={filename}` — delete model file
```json
{ "ok": true }
```

### System Management Endpoints

#### `POST /api/system/radio-restart` — restart ESP-NOW radio driver
#### `POST /api/system/reboot` — reboot Main Node ESP32-S3
#### `POST /api/factory-reset` — factory reset settings & data
```json
{ "wipeSessions": false, "wipeModel": false }
```
#### `POST /api/setup/done` — mark initial setup completed

---

## WebSocket Stream (`/ws`)

Binary frames pushed by Main Node every time a Strike Node IMU batch arrives.

### Frame Format (16-byte header + 12 B × N samples)
```
offset  size  field
   0    1     msgType        (= 0x01 IMU_BATCH)
   1    1     slot           (NodeSlot)
   2    1     sampleCount    (1..8)
   3    1     rssi           (int8 dBm)
   4    4     seq            (uint32 LE — Strike Node sequence)
   8    4     recvTimestampMs (uint32 LE — Main Node millis)
  12    4     nodeTimestampUs (uint32 LE — Strike Node micros at first sample)
  16   12*N   samples        (int16 LE × 6 axes × N)
```

### Sample Decoding (JS)
```js
const ACCEL_LSB_PER_G  = 2048;
const GYRO_LSB_PER_DPS = 16.4;
for (let i = 0; i < sampleCount; i++) {
  const off = 16 + i*12;
  const ax = dv.getInt16(off,    true) / ACCEL_LSB_PER_G;
  // ...
}
```

### Sample Decoding (Python)
```python
import struct
header = struct.unpack('<BBBbIII', buf[:16])
msg, slot, n, rssi, seq, t_recv_ms, t_node_us = header
for i in range(n):
    ax,ay,az,gx,gy,gz = struct.unpack('<hhhhhh', buf[16+i*12 : 28+i*12])
    accel_g = (ax/2048, ay/2048, az/2048)
    gyro_dps = (gx/16.4, gy/16.4, gz/16.4)
```

---

## CSV Session Format

```
# StrikeSense session
# id=1738291201
# athlete=demo
# sample_rate_hz=400
# accel_scale=2048 lsb_per_g
# gyro_scale=16.4 lsb_per_dps
# columns: t_ms,slot,seq,sample_idx,ax,ay,az,gx,gy,gz
t_ms,slot,seq,sample_idx,ax,ay,az,gx,gy,gz
12,1,1,0,123,-456,16384,12,34,-78
14,1,1,1,125,-450,16380,11,30,-80
...
```

- `t_ms` — milliseconds since session start
- `slot` — body location (0..4)
- `seq` — Strike Node packet sequence (groups of 8 sample_idx)
- `ax..gz` — **raw int16** from BMI160 (apply scale factors above)

---

## AI Team Interface — two ways to consume data

### 1. Live API (real-time inference)
Connect to `wss://192.168.4.1/ws`, decode each binary frame, feed model.
Use during training-floor sessions for instant feedback.

### 2. Offline Export (training corpus)
```bash
# List sessions
curl --cacert ./strikesense-ca.pem https://192.168.4.1/api/sessions

# Download one session
curl --cacert ./strikesense-ca.pem -O https://192.168.4.1/api/sessions/1738291201
```
Use for model training, evaluation, and replay.

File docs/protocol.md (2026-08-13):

# StrikeSense ESP-NOW Protocol — v1

ใช้ระหว่าง **Strike Node (ESP32-C3)** และ **Main Node (ESP32-S3)** ผ่าน ESP-NOW
ช่อง 1 (`STRIKESENSE_ESPNOW_CHANNEL`) เท่ากับ WiFi AP channel เพื่อไม่ให้เกิด channel switching

ดู `firmware/shared/protocol.h` สำหรับ definition จริง

## Bandwidth Budget

| Item | Value |
|---|---|
| Sample rate | 400 Hz |
| Bytes/sample | 12 (6 axes × int16) |
| Samples/packet | 8 (= 20 ms window) |
| Packets/sec/Node | 50 |
| Payload/Node | ~5.5 KB/s = **44 kbps** |
| 4 Nodes total (Hands + Shins) | **176 kbps** |

→ ESP-NOW practical limit ~250 kbps ในสภาวะดี → **รองรับ 4 โหนดได้อย่างมีเสถียรภาพ**

## Packet Types

| Type | Direction | Size | Purpose |
|---|---|---|---|
| `PKT_IMU_BATCH` (0x01) | Strike → Main | 112 B | ส่ง 8 samples ของ IMU |
| `PKT_NODE_HELLO` (0x02) | Strike → Main | 10 B | Announce ตอน boot |
| `PKT_NODE_STATUS` (0x03) | Strike → Main | 12 B | Battery + uptime ทุก 5s |
| `PKT_TIME_SYNC` (0x80) | Main → Strike | 8 B | Sync timestamp |
| `PKT_CMD_CONFIG` (0x81) | Main → Strike | 8 B | Update sample rate / sensor config |
| `PKT_CMD_IDENTIFY` (0x82) | Main → Strike | 2 B | กระพริบไฟ LED ระบุตำแหน่งโหนด |
| `PKT_CMD_CALIBRATE` (0x83) | Main → Strike | 2 B | Calibrate baseline offset |
| `PKT_CMD_RESTART` (0x84) | Main → Strike | 2 B | สั่งรีบูต Strike Node |

## IMU Batch Packet Layout (112 bytes)

```
offset  size  field
   0    1     version    (= 1)
   1    1     type       (= 0x01)
   2    1     reserved
   3    1     sampleCount  (≤ 8)
   4    4     seq        (uint32, packet sequence)
   8    4     firstTimestampUs (uint32, node local µs)
  12    2     samplePeriodUs   (= 2500)
  14    2     reserved2
  16   96     samples[8]  (ImuSample × 8, 12 B each)
```

### ImuSample (12 bytes, little-endian)
- `int16_t ax, ay, az` — accel raw, LSB = 1/2048 g (±16 g range)
- `int16_t gx, gy, gz` — gyro raw, LSB = 1/16.4 dps (±2000 dps range)

## Node Identity

Strike Node firmware ไม่ embed slot ลงตัว — Main Node เป็นผู้ map MAC → slot ผ่าน Web UI
`SLOT_UNASSIGNED` (0) เป็น default จนกว่า user จะกำหนดบน dashboard

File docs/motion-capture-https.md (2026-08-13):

> [!CAUTION]
> **สถานะฟีเจอร์ Motion Capture:** ปัจจุบันระบบ Motion Capture (การใช้กล้องประมวลผล MediaPipe Pose 3D) **ยังไม่สามารถใช้งานได้** (ฟีเจอร์นี้อยู่ระหว่างการพัฒนาและพักไว้) เอกสารฉบับนี้จัดทำไว้สำหรับการอ้างอิงข้อกำหนดทางเทคนิคและสถาปัตยกรรมเมื่อฟีเจอร์เปิดใช้งานในอนาคต

เอกสารนี้อธิบายการเตรียมโทรศัพท์และ SD card สำหรับ motion capture ของ
StrikeSense โดยกล้องโทรศัพท์จะประมวลผล MediaPipe ในเบราว์เซอร์และรวมผลกับ
IMU ผ่าน WebSocket ที่เข้ารหัสแล้ว

## Canonical address / URL หลัก

1. เชื่อมต่อ Wi-Fi ของ rig ตามปกติ
2. ถ้าใช้ Local CA ให้เปิด **`https://192.168.4.1/`** เป็น URL หลัก
3. ถ้าใช้ public CA/Let's Encrypt ให้เปิด **`https://<rig-hostname>/`**
   เช่น `https://rig.example.com/` — ห้ามเปิดด้วย IP address
4. Live IMU ใช้ WSS ของ URL เดียวกับ dashboard อัตโนมัติ

อย่าเปิด `http://192.168.4.1` เมื่อต้องใช้กล้อง: HTTP ไม่ใช่ secure context
และเบราว์เซอร์จะปฏิเสธ `getUserMedia()` หรือ WSS ที่ปะปนกับ HTTP ได้

> Server certificate ของ default setup ต้องมี SAN `IP:192.168.4.1`.
> จะใส่ `DNS:strikesense.local` เพิ่มได้ แต่ใช้ชื่อนี้เป็น URL ได้ต่อเมื่อ
> ทดสอบแล้วว่า DNS ของ AP ไม่ชนกับ `.local`/mDNS ของโทรศัพท์.

สำหรับ certificate ของ public CA ชื่อที่เปิดใน browser ต้องตรงกับ DNS SAN
ใน certificate เสมอ; certificate ของ `rig.example.com` จะไม่ใช้ได้กับ
`https://192.168.4.1/`.

## Trust the certificate / ความน่าเชื่อถือของ certificate

เลือกหนึ่งวิธีต่อไปนี้ก่อนเปิด camera mode:

| ทางเลือก | เหมาะกับ | สิ่งที่ต้องทำ |
| --- | --- | --- |
| **Local CA (แนะนำสำหรับ rig offline)** | ยิม/ทีมที่ใช้โทรศัพท์ชุดเดิม | สร้าง CA ภายใน, เซ็น server cert ที่มี SAN `IP:192.168.4.1`, แล้วติดตั้ง **CA certificate สาธารณะ** และเปิด trust บนโทรศัพท์แต่ละเครื่องหนึ่งครั้ง |
| **Public DNS + public CA** | มีโดเมนที่ควบคุมและ provisioning ผ่านอินเทอร์เน็ตได้ | ออก certificate จาก CA สาธารณะให้ hostname ที่เป็นเจ้าของ, ตั้ง AP DNS ให้ hostname นั้นชี้มาที่ rig, ใช้ hostname นั้นเป็น URL หลักของ deployment นั้น, และจัดการ renewal อย่างปลอดภัย |

ข้อสำคัญ:

- ห้ามใช้ self-signed certificate เป็นวิธีใช้งานปกติ: หน้าเตือน/การข้าม
  warning ไม่ใช่ workflow ที่เชื่อถือได้สำหรับกล้องบนมือถือ
- Local CA private key เป็นความลับระดับสูง: เก็บนอก rig, อย่าแจก, และอย่า
  ใส่ใน SD card
- Public CA จะไม่ออก certificate ให้ private address `192.168.4.1`; default
  IP URL จึงต้องใช้ Local CA. อย่าเปิด URL แบบ IP ด้วย certificate ที่ออกให้
  hostname เพราะ SAN จะไม่ตรง
- Firmware รุ่นนี้อ่าน certificate chain และ private key จาก SD ตอน boot ที่
  `/tls/server-cert.pem` และ `/tls/server-key.pem`, ส่งให้ TLS server แล้วล้าง
  buffer ชั่วคราวใน RAM. ทั้งสองไฟล์ต้อง **ไม่** อยู่ใต้ static route หรือ
  `/mocap/`; static server ไม่มี route ที่อนุญาตให้อ่าน `/tls/*`.
- SD ถอดออกได้ ดังนั้น private key ใน implementation นี้เสี่ยงต่อ physical
  access. สำหรับ rig production ให้ย้าย key ไปยัง flash/provisioned secure
  storage (และเปิด flash encryption/secure boot หาก threat model ต้องการ)
  ก่อนนำไปใช้ในพื้นที่ที่ไม่เชื่อถือ.
- บน iPhone/iPad ให้ติดตั้ง profile ของ CA แล้วเปิด Full Trust สำหรับ
  certificate นั้น; Android/managed browser อาจมี policy ที่ห้าม user CA
  ดังนั้นทดสอบกับโทรศัพท์จริงก่อนใช้งาน
- HTTP captive portal ช่วยพาไปยัง URL ได้เท่านั้น; มันไม่ทำให้ certificate
  ที่ไม่ trusted กลายเป็น trusted

### Let's Encrypt via DNS-01 / ใช้ public certificate โดยไม่ต้องลง CA บนมือถือ

วิธีนี้เหมาะเมื่อมี domain จริงที่ควบคุมได้ เช่น `rig.example.com` และต้องการ
ให้ iPhone/Android เชื่อถือ certificate โดยไม่ติดตั้ง CA profile เพิ่ม. ต้องมี
เพียงสิ่งต่อไปนี้:

1. DNS hostname ที่เป็นของคุณและใช้กับ rig เพียงตัวเดียว
2. สิทธิ์แก้ DNS ของ zone นั้น หรือ DNS API token ที่จำกัดสิทธิ์ให้สร้าง TXT
   record สำหรับ ACME เท่านั้น
3. คอมพิวเตอร์/CI ที่ต่ออินเทอร์เน็ตเพื่อออกและ renew certificate; rig ที่อยู่
   บน AP ภายในไม่ต้องเปิด public port หรือมี public IP

ใช้ **DNS-01** กับ ACME client ของ DNS provider นั้น. ACME client จะให้สร้าง
TXT record ใต้ `_acme-challenge.rig.example.com` บน **authoritative public DNS**;
อย่าชี้ A/AAAA record สาธารณะมาที่ rig และอย่าใช้ HTTP-01 กับ `192.168.4.1`.
หลัง validation แล้ว AP DNS ของ rig จะตอบ `rig.example.com` เป็น `192.168.4.1`
ขณะที่โทรศัพท์ต่อ Wi-Fi ของ rig อยู่ จึงเชื่อมต่อ TLS ด้วยชื่อที่ certificate
รับรองได้โดยไม่เผย rig สู่อินเทอร์เน็ต.

อย่าส่ง DNS API token, ACME account key, หรือ `privkey.pem` ผ่าน chat และอย่า
เก็บไว้ใน repository/SD card นอกเหนือจาก private key ของ certificate ที่ rig
ต้องใช้. ให้จำกัด DNS token เป็น zone/record ที่จำเป็น, เก็บไว้ใน secret store
ของเครื่องออก certificate, และตั้ง automated renewal ตามคู่มือของ provider.
ทำ dry run/rehearsal กับ ACME staging environment ก่อนออก production
certificate หาก client รองรับ.

หลัง ACME client ออก certificate แล้ว ให้ใช้ `fullchain.pem` (leaf +
intermediate chain) และ `privkey.pem` จากเครื่องนั้น. Script ด้านล่างไม่ติดต่อ
Let's Encrypt และไม่อ่าน credential ใด ๆ; มันตรวจอายุ, certificate/key pair,
และ DNS hostname ก่อนคัดลอก. Public-CA deployment ต้องใส่ `--hostname`:

```bash
./tools/install-letsencrypt-cert.sh --dry-run --hostname rig.example.com \
  /Volumes/STRIKESENSE \
  /path/to/fullchain.pem \
  /path/to/privkey.pem

./tools/install-letsencrypt-cert.sh --hostname rig.example.com \
  /Volumes/STRIKESENSE \
  /path/to/fullchain.pem \
  /path/to/privkey.pem
```

Script จะเขียนเฉพาะ `/tls/server-cert.pem`, `/tls/server-key.pem`, และ
`/tls/hostname.txt`; ปฏิเสธ SD root/โฟลเดอร์ project/home ที่เสี่ยง, symlink,
key ที่เข้ารหัส, certificate หมดอายุ, pair ที่ไม่ตรงกัน และ hostname ที่ไม่อยู่
ใน certificate. `--dry-run` ไม่เขียนไฟล์เลย. Script ตรวจ format/pair/อายุ/SAN
แต่ไม่ได้ยืนยัน issuer หรือออก certificate แทน ACME client. ปิด rig ก่อนถอด/ใส่ SD card,
eject การ์ดอย่างปลอดภัย, boot rig ใหม่ แล้วเปิด `https://rig.example.com/`.
Script เตือนเมื่อ certificate เหลืออายุน้อยกว่า 14 วัน; อย่ารอให้หมดอายุ และ
ทำ renewal + copy ลง SD ก่อนวันหมดอายุทุกครั้ง.

รายละเอียด DNS-01 และข้อจำกัดของ challenge ดูที่
[Let's Encrypt challenge types](https://letsencrypt.org/docs/challenge-types/).

### TLS files on SD / ไฟล์ TLS บนการ์ด

หลังออก certificate แล้ว ให้คัดลอก full chain (leaf certificate ตามด้วย
intermediate certificate ถ้ามี) และ leaf private key ของ rig ลง SD ดังนี้
(อย่าคัดลอก **Local CA private key** ลง rig):

```text
/tls/server-cert.pem
/tls/server-key.pem
/tls/hostname.txt       # public CA only: exact canonical DNS hostname
```

เก็บ private key นี้ให้พ้นจากผู้ที่ไม่ควรเข้าถึงการ์ด และอย่า commit ไฟล์ PEM
เข้าที่เก็บโค้ด. Firmware จะไม่เปิด HTTPS หากไฟล์ certificate/key ใดไฟล์หนึ่งหายหรืออ่านไม่ได้;
ในกรณีนั้น HTTP legacy ยังเปิด dashboard ได้โดยไม่มีกล้อง. เมื่อ HTTPS เริ่ม
สำเร็จ request HTTP จะถูก redirect ไป URL secure ที่ตั้งค่าไว้ (IP สำหรับ Local
CA หรือ hostname สำหรับ public CA) เพื่อไม่ให้เปิด camera-ineligible dashboard
โดยไม่ตั้งใจ.

## SD card asset layout

Motion capture นี้ pin ที่ **`@mediapipe/tasks-vision` 0.10.35**.  Firmware
ต้อง serve เฉพาะไฟล์ allowlist ด้านล่างแบบ read-only ที่ URL เดียวกับ path
บนการ์ด; ห้าม expose ทั้ง SD card เพราะมี `/sessions` และ `/models` อยู่แล้ว.

```text
/mocap/mediapipe/0.10.35/
├── wasm/
│   ├── vision_wasm_internal.js
│   ├── vision_wasm_internal.wasm
│   ├── vision_wasm_nosimd_internal.js
│   └── vision_wasm_nosimd_internal.wasm
└── models/
    └── pose_landmarker_lite.task
```

The dashboard should use:

```js
FilesetResolver.forVisionTasks('/mocap/mediapipe/0.10.35/wasm')
// modelAssetPath:
// '/mocap/mediapipe/0.10.35/models/pose_landmarker_lite.task'
```

MediaPipe chooses the SIMD pair where available and falls back to the `nosimd`
pair.  Do not delete the fallback files.  The unused `vision_wasm_module_*`
pair is intentionally not installed.

| File | Bytes | SHA-256 |
| --- | ---: | --- |
| `wasm/vision_wasm_internal.js` | 322,044 | `e7fd9858e8e8f221d9b96eddc11f8e077f263e0b7bbd79d3cbe882b134274f8c` |
| `wasm/vision_wasm_internal.wasm` | 11,153,617 | `6a5c64584c2ab61c763b6e204afbdbc7ce1caf7f5216187322bca8df94f646bc` |
| `wasm/vision_wasm_nosimd_internal.js` | 321,847 | `438d1fe8ff7f4d946025bc211c291543c037d8a3785ed4eee60f1f521b236296` |
| `wasm/vision_wasm_nosimd_internal.wasm` | 10,481,398 | `8a3092d34c79d3f57e6ba8592105e8a90f6b07c27891ffecd14cca428bfd3e31` |
| `models/pose_landmarker_lite.task` | 5,777,746 | `59929e1d1ee95287735ddd833b19cf4ac46d29bc7afddbbf6753c459690d574a` |

Total is about 26.8 MiB.  Static responses need these MIME/cache headers:

- `.wasm` → `application/wasm`
- `.js` → `text/javascript`
- `.task` → `application/octet-stream`
- Versioned assets → `Cache-Control: public, max-age=31536000, immutable`
- Add `X-Content-Type-Options: nosniff`; return 404 (not dashboard HTML) for
  any unknown `/mocap/` path.

## Install assets / ติดตั้ง asset

Insert the SD card in a computer, identify its **mounted root**, then run:

```bash
./tools/install-mediapipe-assets.sh /Volumes/STRIKESENSE
```

The script requires an explicit existing directory, refuses `/` and the home
directory, rejects symlinked destination paths, downloads only HTTPS sources,
verifies SHA-256, and writes only beneath the supplied root at
`mocap/mediapipe/0.10.35/`. It never creates, copies, or changes certificates,
session CSVs, AI models, or any other SD paths. Safely eject the card after it
finishes.

## Operational safety / ข้อควรระวังในการใช้งาน

- First load is large. Wait for MediaPipe to finish caching before starting a
  scored session; serving tens of MiB from SD competes with the rig radio.
- Native TLS is sized for **one active phone** (at most three TLS sockets).
  Close other rig tabs while loading MediaPipe. Large asset/API downloads can
  briefly delay WSS; the firmware drops excess live batches instead of letting
  a backlog make force feedback stale.
- Keep camera and IMU on the same trusted HTTPS origin. An HTTPS page calling
  old `http://` APIs or `ws://` is mixed content and browsers block it.
- Asset version and JavaScript package version must match. Upgrade by adding a
  new versioned directory and changing the dashboard path, not by silently
  replacing files in a cached version.
- `Δ≈… ms` in the camera panel is a **timing estimate**. The dashboard maps the
  Main Node receive timestamp to the browser's monotonic clock and uses the
  video frame's expected display time, but it does not measure camera exposure
  latency or the exact peak sample within an IMU batch (about 20 ms uncertainty).
  Use an externally calibrated hardware trigger/high-speed camera for
  biomechanics-grade timing; do not treat this display as one.
- A matched frame whose required joint is occluded reports no angle rather than
  inventing a value. Reframe the full body before interpreting left/right form.
- A trusted certificate protects the Wi-Fi transport, not physical SD access.
  Treat recordings and any removable card as sensitive training data.

MediaPipe model source: [Pose Landmarker for web](https://ai.google.dev/edge/mediapipe/solutions/vision/pose_landmarker/web_js).

## Android over HTTP — ใช้กล้องบน HTTP

`getUserMedia()` เปิดให้เฉพาะ secure context เท่านั้น ซึ่งตามปกติแปลว่าต้องเป็น HTTPS
แต่ **Android Chrome เป็นเบราว์เซอร์เดียวที่ผู้ใช้ยกข้อจำกัดนี้เองได้** โดยประกาศว่า
origin ของ rig เป็น secure context ซึ่งตรงกับสิ่งที่ `getUserMedia` ต้องการพอดี:
เครือข่ายส่วนตัวที่ไม่มีเส้นทางออกอินเทอร์เน็ต

iOS ไม่มีสวิตช์เทียบเท่า — ทั้ง Safari และ Chrome/Firefox บน iOS ใช้ WebKit ตัวเดียวกัน
บน iOS จึงต้องใช้ HTTPS จริงตามเอกสารข้างต้นเท่านั้น

### ขั้นตอน (ทำครั้งเดียวต่อเครื่อง)

1. เชื่อมต่อ Wi-Fi `StrikeSense`
2. เปิด `chrome://flags`
3. ค้นหา **Insecure origins treated as secure**
4. ตั้งเป็น **Enabled** และใส่ origin ของ rig ในช่องข้อความ:

   ```text
   http://192.168.4.1
   ```

5. กด **Relaunch**
6. เปิด `http://192.168.4.1/` แล้วเปิดการ์ดกล้อง → อนุญาตให้ใช้กล้อง

ถ้ายังไม่ได้ตั้ง flag หน้าเว็บจะแสดงขั้นตอนนี้พร้อม origin ที่ต้องคัดลอกให้เอง
(แสดงเฉพาะเมื่อตรวจพบว่าเป็น Android Chrome)

### ฝั่ง rig ต้องมีอะไร

บิลด์ HTTP เสิร์ฟ MediaPipe runtime จาก SD ที่ path เดียวกับบิลด์ HTTPS
โดยลงทะเบียนเป็น path ตรงตัว 5 เส้นตาม manifest ใน
[SD card asset layout](#sd-card-asset-layout) — ไม่ใช่ prefix และไม่ใช้ `serveStatic`
เพราะการ์ดใบเดียวกันเก็บไฟล์ session และ (บนบิลด์ HTTPS) private key ของ TLS

ตรวจได้จาก serial ตอนบูต:

```text
[MOCAP] ไฟล์ MediaPipe ครบ 5/5 — กล้องพร้อมใช้
[MOCAP] ⚠ ไฟล์ MediaPipe 3/5 บน SD — กล้องจะเริ่มไม่ได้
```

### ข้อควรรู้

- โหลด wasm ครั้งแรกกินเวลาพอสมควร (หลาย MB ผ่าน SoftAP) ระหว่างนั้น rig จะหยุด
  live stream ชั่วคราวแบบเดียวกับตอนดาวน์โหลด session
- เวอร์ชันถูกฝังไว้ใน path และ response ส่ง `Cache-Control: immutable`
  ดังนั้นโหลดครั้งเดียวต่อเครื่อง
- flag นี้ผูกกับ origin ที่ระบุเท่านั้น ไม่ได้ลดความปลอดภัยของเว็บอื่น
  แต่ควรลบออกเมื่อเลิกใช้งาน rig

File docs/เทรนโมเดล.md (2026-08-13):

# คู่มือการเทรนโมเดลจับท่ามวย (Model Training User Manual)
**เวลาที่ใช้** ครั้งแรก ~30 นาที (รวมติดตั้ง) · ครั้งต่อไป ~10 นาที

---

## ภาพรวม 4 ขั้น

```
1. เก็บข้อมูล        ที่แดชบอร์ดบนมือถือ/แท็บเล็ต — ต่อยจริงให้ระบบดู
        ↓            ได้ไฟล์ .csv
2. เทรน              บนคอมพิวเตอร์ — คำสั่งเดียว
        ↓            ได้ไฟล์ strike_web_model_fine.json
3. อัปโหลดกลับ        ที่แดชบอร์ด — โมเดลไปเก็บใน SD ของเครื่อง
        ↓
4. ใช้งาน             ทุกมือถือที่ต่อเข้ามาได้โมเดลใหม่อัตโนมัติ
```

**ทำไมต้องเทรนบนคอม** — ESP32 บนเครื่องแรมไม่พอเทรนโมเดล และเทรนบนมือถือจะใช้เวลา
เป็นสิบนาที เครื่องทำหน้าที่เก็บข้อมูลกับใช้งานโมเดล ส่วนการเทรนทำบนคอมครั้งเดียว

---

## เตรียมครั้งแรก (ทำครั้งเดียว)

ต้องมี **Python 3.10 หรือ 3.11** บนคอมพิวเตอร์ (เวอร์ชันใหม่กว่านี้ TensorFlow อาจยังไม่รองรับ)

###  สำหรับ macOS:
```bash
# เช็กเวอร์ชัน Python
python3 --version

# ติดตั้งไลบรารี
cd ~/Documents/GitHub/StrikeSense/ml_pipeline && pip3 install -r requirements.txt
```

### ⊞ สำหรับ Windows:
```cmd
:: เช็กเวอร์ชัน Python (ต้องเลือก Add Python to PATH ตอนติดตั้ง)
python --version

:: ติดตั้งไลบรารี (Command Prompt / PowerShell)
cd %USERPROFILE%\Documents\GitHub\StrikeSense\ml_pipeline
pip install -r requirements.txt
```

ใช้เวลาสักพัก (TensorFlow ไฟล์ใหญ่) เสร็จแล้วไม่ต้องทำอีก

---

## ขั้นที่ 1 · เก็บข้อมูล

### เตรียมเครื่อง

1. เปิดโหนดเซนเซอร์ **ครบทั้ง 4 ตัว** (มือซ้าย · มือขวา · แข้งซ้าย · แข้งขวา)
   ใส่ครบสำคัญ เพราะแขนขาที่ไม่ได้ออกอาวุธจะถูกบันทึกเป็นท่า "ขยับตัว" ให้อัตโนมัติ
   ซึ่งเป็นข้อมูลที่ทำให้ระบบไม่นับการก้าวเท้าเป็นการเตะ
2. ต่อ WiFi ชื่อ **StrikeSense** แล้วเปิด `192.168.4.1`
3. ไปแท็บ **ระบบ** → เปิดสวิตช์ **โหมดนักพัฒนา**
   จะมีแผง **เก็บข้อมูลเทรน AI** โผล่ขึ้นมา

### เก็บทีละท่า

```
1. เลือกท่าจากช่องเลือก        เช่น "หมัดเสย"
2. กด "เริ่มบันทึก"
3. ออกอาวุธท่านั้น ~50 ครั้ง
4. กด "หยุดบันทึก"             ระบบจะบอกว่าเก็บได้กี่ครั้ง
5. เลือกท่าถัดไป → ทำซ้ำข้อ 2-4
```

**กติกาตอนอัด — สำคัญกว่าที่คิด**

| ทำ | ทำไม |
|---|---|
| **ออกอาวุธเต็มแรงทุกครั้ง** | ระบบนับเฉพาะที่แรงเกิน 6 g ถ้าซ้อมเบา ๆ ให้ครบจำนวน จะได้ข้อมูลไม่ถึงครึ่ง |
| **สลับซ้าย-ขวา** | ถ้าใช้ข้างเดียว มืออีกข้างที่ตั้งการ์ดนิ่ง ๆ จะถูกป้ายเป็นท่านั้นไปด้วย ทำให้ระบบสับสน |
| **ก้าวเท้าขยับตลอด** | ได้ข้อมูล "ขยับตัว" ไปด้วย ถ้ายืนตรึงจะไม่ได้เลย |
| **เว้นจังหวะระหว่างครั้ง ~0.5 วินาที** | ถ้าเร็วกว่านี้ระบบจะนับรวมเป็นครั้งเดียว |

### ดูว่ายังขาดท่าไหน

ใต้แผงมีคลังข้อมูลบอกความคืบหน้าสด ๆ:

```
คลังข้อมูลที่เก็บไว้
เตะตัด        ████████████  72
แย็บ          ███████       45/50
ศอกงัด        ██            12/50   ← ยังขาดอีก 38
```

แถบเขียว = ครบ 50 ครั้งแล้ว · ตัวเลขคือ **จำนวนครั้งที่ต่อยจริง** ไม่ใช่จำนวนข้อมูลดิบ

**50 ครั้งต่อท่า** คือจุดที่วัดแล้วว่าความแม่นเริ่มเชื่อถือได้ ท่าที่มี 130 ครั้งขึ้นไปได้ความแม่น
89-97% ส่วนท่าที่มีต่ำกว่า 35 ครั้งตัวเลขยังเหวี่ยงมากจนสรุปอะไรไม่ได้

### ส่งออก

กด **"↓ ส่งออกทั้งหมด"** — ได้ไฟล์เดียวลงโฟลเดอร์ Downloads

> ⚠ **ข้อมูลอยู่ในหน่วยความจำเบราว์เซอร์ ปิดแท็บแล้วหาย**
> เก็บเสร็จกดส่งออกก่อนปิดทุกครั้ง

---

## ขั้นที่ 2 · เทรน

เอาไฟล์จาก Downloads มาที่คอม แล้วรันคำสั่งสคริปต์ตามระบบปฏิบัติการ:

###  สำหรับ macOS:
```bash
cd ~/Documents/GitHub/StrikeSense && ./ml_pipeline/retrain.sh
```

### ⊞ สำหรับ Windows:
```cmd
cd %USERPROFILE%\Documents\GitHub\StrikeSense
.\ml_pipeline\retrain.bat
```
*(หรือดับเบิลคลิกไฟล์ `retrain.bat` ในโฟลเดอร์ `ml_pipeline` ได้เลย)*

สคริปต์จะหาไฟล์ใหม่ใน Downloads เอง ย้ายเข้าคลังข้อมูลให้ แล้วเทรน
ใช้เวลาราว 3-6 นาที

**ตัวเลือกการรันตรงผ่าน Python (ใช้ได้ทั้ง macOS & Windows):**

```bash
cd ml_pipeline
python train_model.py --data "./data/*.csv" --mode fine --web-out strike_web_model_fine.json
```

### อ่านผลลัพธ์

จบแล้วจะได้ตารางแบบนี้:

```
ท่า            โมเดล   +กายภาพ
Hook          100.0%    100.0%
Uppercut       95.6%     98.8%
Jab            97.6%     97.6%
Cross          88.5%     88.5%
Elbow-Slash    50.0%     60.0%   ← ต่ำ
```

ตัวเลขคือ **ระบบจับท่านั้นถูกกี่เปอร์เซ็นต์**

| เห็นแบบนี้ | แปลว่า | ทำอะไรต่อ |
|---|---|---|
| 90% ขึ้นไป | ใช้งานได้ดี | ไม่ต้องทำอะไร |
| 70-90% | พอใช้ | เก็บท่านั้นเพิ่มอีก ~30 ครั้ง |
| ต่ำกว่า 70% | ยังเชื่อไม่ได้ | เก็บให้ถึง 50 ครั้ง แล้วเทรนใหม่ |

ถ้าตัวเลขของท่าไหน **เหวี่ยงไปมาทุกครั้งที่เทรน** แปลว่าข้อมูลท่านั้นยังน้อยเกินไป
ไม่ใช่โมเดลมีปัญหา

---

## ขั้นที่ 3 · อัปโหลดโมเดลกลับ

1. ต่อ WiFi **StrikeSense** → เปิด `192.168.4.1`
2. แท็บ **ระบบ** → หัวข้อ **คลังโมเดล AI**
3. กด **"เพิ่มไฟล์โมเดล"** → เลือกไฟล์:

```
ml_pipeline/strike_web_model_fine.json
```

4. รอจนขึ้นว่า **"พร้อม · N ท่า · เก็บที่ SD card"**

เก็บลง SD ของเครื่องแล้ว — มือถือเครื่องอื่นที่ต่อเข้ามาจะได้โมเดลใหม่เองโดยไม่ต้องอัปซ้ำ

---

## ขั้นที่ 4 · ตรวจว่าใช้ได้จริง

ในแท็บระบบจะเห็นกล่องบอกว่าโมเดลรู้จักท่าอะไรบ้าง:

> **โมเดลนี้แยกได้ 9 ท่า**
> มือ · แย็บ · หมัดตรง · ฮุก · หมัดเสย · ศอกสับ · ศอกตี · ศอกงัด
> ขา · เตะตัด · เตะขาล่าง

ท่าที่ไม่อยู่ในรายการ (เข่า · ถีบ) ระบบจะตอบเป็นท่าที่ใกล้เคียงที่สุด — เป็นการเทียบเคียง
ไม่ใช่การอ่านค่าจริง ถ้าอยากให้แยกได้จริงต้องเก็บท่านั้นแล้วเทรนใหม่

ลองออกอาวุธดู ชื่อท่ากับคะแนนจะขึ้นที่การ์ดบนสุดของหน้าแรก

---

## ปัญหาที่เจอบ่อย

**เก็บข้อมูลแล้วนับได้น้อยกว่าที่ต่อยจริงมาก**
ต่อยไม่แรงพอ ระบบนับเฉพาะที่เกิน 6 g ดูตัวเลข "แรง G" บนแถบบนสุด ต้องพุ่งเกิน 6 ทุกครั้งที่ต่อย

**`pip3 install` ไม่ผ่าน / หา tensorflow ไม่เจอ**
Python เวอร์ชันใหม่เกินไป ต้องใช้ 3.10 หรือ 3.11

**เทรนแล้วท่าที่เคยแม่นกลับแย่ลง**
ปกติถ้าตัวอย่างทดสอบของท่านั้นมีน้อย (ต่ำกว่า ~20 ครั้ง) ตัวเลขจะเหวี่ยงเองทุกครั้งที่เทรน
ไม่ใช่การถดถอยจริง ดูที่คอลัมน์จำนวนครั้งประกอบเสมอ

**อัปโมเดลแล้วแต่ชื่อท่าไม่ขึ้น**
เช็คว่าเปิดสวิตช์ "เปิดตรวจจับท่าด้วย AI" แล้วหรือยัง และโหนดที่ใส่ตรงกับอวัยวะที่ตั้งค่าไว้ไหม

**Jab กับ Cross สลับกันบ่อย**
เซนเซอร์อยู่ที่ข้อมือ มองเห็นสองท่านี้เกือบเหมือนกัน ต่างกันที่การหมุนลำตัวซึ่งข้อมือรับได้ไม่เต็ม
เป็นเพดานของฮาร์ดแวร์ ไม่ใช่ของโมเดล ถ้าจำเป็นให้อัดแยกข้าง (มือนำ = แย็บ · มือหลัง = หมัดตรง)
แล้วเทรนด้วยโหมด `coarse_lr` ซึ่งใช้ข้างช่วยตัดสิน

---

## ไฟล์ที่เกี่ยวข้อง

| ไฟล์ | คืออะไร |
|---|---|
| `ml_pipeline/data/*.csv` | ข้อมูลดิบทั้งหมดที่เคยเก็บ — ยิ่งเยอะยิ่งดี ไม่ต้องลบ |
| `ml_pipeline/retrain.sh` | สคริปต์เทรนคำสั่งเดียว |
| `ml_pipeline/train_model.py` | ตัวเทรนจริง (ปรับค่าขั้นสูงได้ที่นี่) |
| `ml_pipeline/strike_web_model_fine.json` | **ไฟล์ที่ต้องอัปเข้าแดชบอร์ด** |
| `ml_pipeline/confusion_matrix.png` | รูปสรุปว่าท่าไหนถูกสับสนกับท่าไหน |

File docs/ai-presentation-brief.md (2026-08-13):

# StrikeSense — สรุปเชิงเทคนิคเฉพาะส่วน AI (สำหรับนำเสนอ)

เอกสารนี้สรุปเฉพาะฟังก์ชัน AI ของ StrikeSense: ทำอะไร ทำงานอย่างไร ใช้งานอย่างไร
และมีข้อจำกัดตรงไหน ตัวเลขทุกตัวในเอกสารนี้อ้างอิงจากโค้ดและ pipeline จริงในโปรเจกต์
ไม่ใช่ค่าประมาณ

---

## 1. ภาพรวม: AI ทำอะไรให้

ระบบมีเซ็นเซอร์ IMU 4 ตัว (มือซ้าย/ขวา แข้งซ้าย/ขวา) ส่งข้อมูล 400 Hz เข้ามาที่ Main Node
สิ่งที่ AI เพิ่มเข้ามาคือ **การบอกว่าอาวุธที่เพิ่งออกไปนั้นคือท่าอะไร** พร้อมระดับความมั่นใจ

แยกให้ชัดว่าอะไรคือ AI อะไรไม่ใช่:

| ส่วน | เป็น AI ไหม | ทำอะไร |
|---|---|---|
| วัดแรง (g) และความเร็วเชิงมุม (°/s) | ไม่ใช่ | อ่านตรงจาก IMU |
| ตรวจจับว่า "มีการออกอาวุธ" | ไม่ใช่ | detector เชิงกฎ (rule-based) |
| บอกว่าเป็นท่าอะไร | **ใช่** | 1D-CNN ทำนายจากรูปคลื่นการเคลื่อนไหว |
| คะแนนต่อหมัด 0–100 | ไม่ใช่ | สถิติเทียบกับท่าเดียวกัน (ใช้ผลจาก AI มาเลือกกลุ่มเปรียบเทียบ) |

จุดขายทางเทคนิคที่ควรพูด:

- **โมเดลรันในเบราว์เซอร์ทั้งหมด** ไม่ต้องต่อเน็ต ไม่ส่งข้อมูลออกนอกเครื่อง
- **ไม่ใช้ TensorFlow.js** — เขียน inference engine เอง (`dashboard/src/ainet.js`)
  ขนาดเล็ก ทำงาน offline ตรวจสอบแล้วว่าผลตรงกับ Keras ที่ระดับความคลาดเคลื่อน 1e-6
  (`ml_pipeline/verify_web_model.py`)
- **เปลี่ยนโมเดลได้โดยไม่ต้อง flash เฟิร์มแวร์** โมเดลเก็บเป็นไฟล์ JSON บน SD card
  ของ Main Node และอัปโหลดผ่านหน้าเว็บ

---

## 2. เส้นทางข้อมูลตั้งแต่ต้นจนจบ

```
IMU 4 ตัว @400 Hz
   │  ESP-NOW
   ▼
Main Node (ESP32-S3)
   │  WebSocket (binary frames)
   ▼
เบราว์เซอร์
   ├─ Detector v2  ── ตัดสินว่า "ออกอาวุธแล้ว" + ตัดหน้าต่างเวลา
   ├─ Normalise    ── ใช้ mean/std ชุดเดียวกับตอนเทรน
   ├─ 1D-CNN       ── ทำนายความน่าจะเป็นของแต่ละท่า
   ├─ Physics prior── ถ่วงน้ำหนักด้วยแรง/ความเร็วจริง
   ├─ Limb mask    ── ตัดท่าที่แขนขาข้างนั้นทำไม่ได้
   └─ Naming policy── ตัดสินว่าจะตั้งชื่อท่าหรือบอกว่า "ไม่ระบุ"
```

ฝั่งเทรน:

```
Data Logger (หน้าเว็บ) → strike_*.csv (IMU ดิบ 400 Hz + ป้ายท่า + slot)
   → ml_pipeline/train_model.py
   → strike_web_model.json  (อัปโหลดเข้าแดชบอร์ด)
   → confusion_matrix.png   (ดูว่าโมเดลสับสนท่าไหน)
```

---

## 3. สเปกโมเดล

| หัวข้อ | ค่า |
|---|-----|
| สถาปัตยกรรม | 1D-CNN (Conv1D → BatchNorm → MaxPool → GlobalAvgPool → Dense) |
| Input | 160 × 6 = หน้าต่าง 160 ตัวอย่าง @400 Hz คือ **400 มิลลิวินาที** |
| Features | `ax, ay, az, gx, gy, gz` เท่านั้น |
| Normalisation | per-axis standardisation ด้วย mean/std จากชุดเทรน (ฝังในไฟล์โมเดล) |
| รูปแบบไฟล์ | JSON `format: "strikesense-web/1"` |
| เทรน | 120 epochs (early stopping), batch 32, class weights แก้ข้อมูลไม่สมดุล |
| Augmentation | สุ่มคูณ gain 0.85–1.15 ต่อหน้าต่าง |

**หมายเหตุสำคัญ: `slot` ไม่ใช่ feature** — โมเดลไม่รู้ว่าข้อมูลมาจากมือหรือแข้ง
เจตนาให้เป็นแบบนั้น เพราะจะได้เรียนรู้ "รูปร่างการเคลื่อนไหว" ไม่ใช่จำว่าเซ็นเซอร์ตัวไหน
ส่วนการกันคำตอบผิดข้ามแขนขาไปจัดการที่ layer ถัดไป (ข้อ 6)

### โหมดความละเอียดของคลาส

| โหมด | จำนวนคลาส | รายละเอียด |
|---|---|---|
| `coarse` (ค่าเริ่มต้น) | 5 | Punch · Elbow · Knee · Kick · Teep |
| `coarse_lr` | 10 | 5 อาวุธ × ซ้าย-ขวา |
| `fine` | ~21 | Jab, Cross, Hook, Uppercut, Elbow-Chop/Slash/Up/Thrust/Spear/Spin, Knee-Straight/Diagonal/Curve/Fly, Kick-Straight, Roundhouse, Kick-Low, Kick-Spin, Kick-Heel, Teep, Teep-Side, Teep-Back |

ทุกโหมดมีคลาสพิเศษเพิ่มอีก 2 ตัวเสมอ:

- **Idle** — ยืนนิ่ง ไม่ได้ออกอาวุธ
- **Move** — ขยับแต่ไม่ใช่การออกอาวุธ (ก้าวเท้า เปลี่ยนสแตนซ์ ตั้งการ์ดใหม่)

สองคลาสนี้คือกลไกกันการตั้งชื่อมั่ว ถ้าไม่มี `Move` โมเดลจะไม่มีคำตอบที่ถูกต้องให้เลือก
สำหรับขาที่ขยับโดยไม่ได้เตะ แล้วจะไปตอบเป็นท่าเตะที่ใกล้เคียงที่สุดแทน

---

## 4. Detector v2 — จุดที่กำหนดคุณภาพทั้งระบบ

โมเดลจะดีแค่ไหนขึ้นกับว่า "ตัดหน้าต่างเวลาตรงไหน" ถ้าตัดผิดจุด โมเดลจะเห็นคนละช่วง
กับที่เคยเทรนมา เรื่องนี้จึงถูกทำเป็นโมดูลแยก และ**บังคับให้ฝั่ง JavaScript กับฝั่ง Python
ใช้กฎเดียวกันเป๊ะ** มีเทสต์ตรวจความตรงกันที่ `ml_pipeline/test_detector_parity.py`

พารามิเตอร์ (ตรงกันทั้งสองฝั่ง):

| ค่า | ความหมาย |
|-----|---|
| `armG = 5.0` | dynamic g (หักแรงโน้มถ่วงออกแล้ว) ที่ทำให้เริ่มค้นหายอด |
| `searchMs = 80` | ถ้าไม่เจอยอดใหม่ภายใน 80 ms ให้สรุปว่ายอดนั้นคือจุดกระทบ |
| `releaseG = 2.0` | ต้องตกกลับต่ำกว่านี้ก่อน ถึงจะนับครั้งถัดไปได้ |
| `refractoryMs = 400` | ระยะห่างขั้นต่ำระหว่างสองครั้งของแขนขาเดียวกัน |

### ทำไมเวอร์ชันแรกถึงใช้ไม่ได้ (เนื้อหานี้เล่าได้ดีในการนำเสนอ)

v1 ใช้กฎง่ายๆ คือ "เกิน 3.0 g เมื่อไหร่ = ออกอาวุธ" มีปัญหาสองข้อ:

1. **`|accel|` รวมแรงโน้มถ่วงอยู่แล้ว** แขนขาที่อยู่นิ่งอ่านได้ 1.0 g อยู่แล้ว
   เกณฑ์ 3.0 g จึงเท่ากับ 2.0 g จริง ซึ่ง IMU ที่แข้งทะลุค่านี้ได้จากแค่การเดิน
2. **จับที่จุดตัดครั้งแรก ไม่ใช่จุดสูงสุด** วัดจากข้อมูลจริง: เฟรมแรกของท่าเตะตัดที่ ~5 g / 260 dps
   แต่จุดกระทบจริงมาถึงอีก ~250 ms ให้หลังที่ ~12 g / 630 dps
   v1 จึงประทับเวลาไว้ที่ "ช่วงเก็บขา" แล้วส่งช่วงนั้นให้โมเดลดู — **โมเดลไม่เคยเห็นจุดกระทบเลย**

ผลคือ 81–92% ของจุดที่ v1 ตรวจจับได้ในไฟล์บันทึกท่าเตะ อยู่ติดเพดาน refractory พอดี
แปลว่าเตะหนึ่งครั้งถูกตัดเป็น 3–4 หน้าต่าง ส่วนใหญ่เป็นการเคลื่อนเท้า
โมเดลจึงเรียนรู้ว่า "แข้งขยับ = เตะ" ซึ่งเป็นเหตุผลว่าทำไมการเดินถึงถูกนับเป็นท่า

v2 แก้ด้วยการหักแรงโน้มถ่วงออก ใช้ hysteresis และ **ตามหายอดจริง**
(เจอยอดใหม่เมื่อไหร่ให้รีสตาร์ตตัวจับเวลา) จึงตามการเคลื่อนไหวไปจนถึงจุดสูงสุดได้

---

## 5. Physics prior — คืนข้อมูลที่ตั้งใจให้โมเดลลืม

ตอนเทรนมีการสุ่ม gain 0.85–1.15 เพื่อให้ Hook อ่านว่าเป็น Hook ทั้งที่ 6 g และ 11 g
ซึ่งถูกต้องสำหรับ "รูปร่างท่า" แต่ผิดสำหรับท่าที่ต่างกันที่ **ขนาดแรง** เป็นหลัก

วัดจากข้อมูลจริงที่จุดกระทบ:

| คู่ที่โมเดลสับสน | ค่าที่วัดได้ | Cohen's d |
|---|---|---|
| Elbow-Up vs Kick-Low | 7 g / 604 dps vs 18 g / 843 dps | 2.28 |
| Uppercut vs Hook | 8 g / 628 dps vs 16 g / 954 dps | 1.13 |

ทั้งสองคู่แยกกันได้ชัดด้วยขนาดแรงล้วนๆ จึงมีการ fit **Gaussian หนึ่งตัวต่อคลาส**
บน log ของ (peak |accel|, peak |gyro|) แล้วนำมารวมกับผลของ CNN **ใน log space**
โดยน้ำหนักถูกเลือกจากการวัดความแม่นบนชุด validation — ถ้าไม่ช่วย น้ำหนักจะถูกปรับเป็น 0
และโมเดลตอบเองล้วน

ต่างจากวิธีเดิมตรงไหน: ของเดิมเป็นบันไดเงื่อนไขเขียนมือ (`peakG > 9 → ศอก`)
ไม่มีการวัดรองรับ และตอบด้วยความมั่นใจเท่ากันทุกกรณี

**สิ่งที่วิธีนี้แก้ไม่ได้ และไม่ได้อ้างว่าแก้** — คู่ที่ต่างกันที่รูปร่าง ไม่ใช่แรง:
Elbow-Chop vs Elbow-Slash (d 0.53), Jab vs Cross (d 0.53), Roundhouse vs Kick-Low (d 0.46)
ไม่มีเกณฑ์แรงใดแยกคู่พวกนี้ได้

---

## 6. Limb mask — ตัดคำตอบที่เป็นไปไม่ได้

เพราะ `slot` ไม่ใช่ feature โมเดลจึงตอบ "Jab" ให้หน้าต่างที่มาจากแข้งได้
มวยไทยตัดสินเรื่องนี้ได้โดยไม่ต้องใช้โมเดล: มือออกหมัดกับศอก ขาออกเข่า เตะ ถีบ

ระบบจึง mask คลาสที่แขนขานั้นทำไม่ได้ออกก่อนทำ argmax ไม่มีต้นทุนเพิ่ม
แต่ตัดคำตอบผิดออกไปทั้งหมวด ข้อมูล `limbs` เดินทางมากับไฟล์โมเดล
ส่วนไฟล์รุ่นเก่าที่ยังไม่มีข้อมูลนี้จะ fallback ไปใช้การจับคู่จากชื่อคลาส

Slot ตายตัว: `1 = มือซ้าย · 2 = มือขวา · 3 = แข้งซ้าย · 4 = แข้งขวา`

---

## 7. นโยบายการตั้งชื่อ / การขอไม่ตอบ

มีสองสาเหตุที่ระบบจะขึ้นว่า "ไม่ระบุ" และสองอันนี้ไม่เหมือนกัน:

1. **Idle / Move** — โมเดลบอกว่าหน้าต่างนี้ไม่ใช่ท่าเลย
   ตัวนี้กันการบันทึกถุงมือที่ตกพื้น การจับเซ็นเซอร์ปรับตำแหน่ง หรือการลงเท้าแรงๆ
   ว่าเป็นหมัด — **บังคับใช้เสมอ ปิดไม่ได้**
2. **ความมั่นใจต่ำกว่าเกณฑ์** (`MIN_CONF = 0.35`) — เป็นการออกอาวุธจริง
   แต่โมเดลบอกไม่ได้ว่าท่าไหน ตัวนี้ผู้ใช้ปิดได้ด้วยสวิตช์ "ตั้งชื่อทุกครั้ง"

วัดบนชุด held-out ด้วยโมเดลที่ใช้งานจริง (675 การออกอาวุธจริง, 1422 หน้าต่างนิ่ง):

| การตั้งค่า | ตั้งชื่อ | ถูกต้อง | ได้ชื่อที่ถูกจริง |
|---|---|---|---|
| เปิดเกณฑ์ความมั่นใจ | 545/675 | 87.3% | 476 ครั้ง |
| ปิดเกณฑ์ | 668/675 | 80.4% | **537 ครั้ง** |
| ปิดเกณฑ์ + ปิด Idle ด้วย | 675/675 | 80.1% | 541 ครั้ง — แต่หน้าต่างนิ่งทั้ง 1422 อันก็ได้ชื่อท่าไปด้วย |

ประเด็นที่น่าพูด: **การปิดเกณฑ์ทำให้ได้ชื่อที่ถูกต้องมากขึ้น ไม่ใช่น้อยลง**
ความแม่นต่อชื่อลดลงก็จริง แต่ครอบคลุมมากขึ้นจนคุ้ม ส่วนการปิด Idle ด้วยนั้น
ได้เพิ่มอีกแค่ 4 ครั้ง แลกกับการเสีย safety net ทั้งหมด จึงไม่เปิดให้เลือก

นอกจากนี้ หน้าเว็บยังบอกตรงๆ ว่า **โมเดลตัวที่โหลดอยู่แยกได้กี่ท่าและท่าอะไรบ้าง**
เพื่อไม่ให้เข้าใจผิดว่าคำตอบที่ได้คือการวัด ทั้งที่จริงเป็นการเทียบเคียงกับท่าที่ใกล้ที่สุด
ที่มีในโมเดล (เช่น ยิงเข่าใส่โมเดลที่เทรนมาแต่ท่าเตะ)

---

## 8. คะแนนต่อหมัด 0–100

ไม่ใช่ AI แต่ใช้ผลจาก AI มาเลือกกลุ่มเปรียบเทียบ จึงควรเล่าคู่กัน

คะแนนบอกว่า **หมัดนี้เทียบกับหมัดท่าเดียวกันในข้อมูลที่บันทึกไว้เป็นอย่างไร** โดย 50 คือค่ากลาง
เหตุผลที่ต้องเทียบเป็นรายท่า: uppercut ลงประมาณ 9.5 g ส่วน cross ประมาณ 14.2 g
ถ้าใช้กฎเดียว "แรง = คะแนนสูง" uppercut จะถูกตีว่าอ่อนทุกครั้ง และ cross จะได้คะแนนเกินจริงทุกครั้ง

- ใช้ z-score บน log ของสองปริมาณ: **power** (peak |accel|) และ **speed** (peak |gyro|)
- `score = 50 + 22 × mean(z_power, z_speed)` ตัดที่ 1–100
- 1 SD เหนือค่าเฉลี่ยของท่านั้น ≈ 72 คะแนน · 2 SD ≈ 94 คะแนน
- ค่าอ้างอิงรายท่ามาจาก block `physics` ที่ pipeline fit ไว้และฝังมากับไฟล์โมเดล
  ไม่ใช่เกณฑ์ที่เดาเอา
- ถ้ายังไม่ได้โหลดโมเดล หรือหมัดนั้นไม่มีชื่อท่า จะเทียบกับค่ารวมทุกท่าแทน
  (11.6 g และ 846 °/s) ซึ่งอ่อนกว่าแต่ยังตรงไปตรงมา

---

## 9. วิธีใช้งานจริง (ลำดับสาธิต)

### 9.1 เก็บข้อมูลเทรน

1. เปิด Developer mode (แท็บ **ระบบ** หรือกดปุ่ม `d`)
2. การ์ด **AI TRAINING · DATA LOGGER** → เลือกท่าที่จะบันทึก → **เริ่มบันทึก** → ออกอาวุธ → **หยุด**
3. กด **↓ CSV** แล้ววางไฟล์ไว้ที่ `ml_pipeline/data/`
4. ทำให้ครบทุกท่า ทั้งซ้ายและขวา

Logger จะเขียนแถวของแขนขาที่ **ไม่ได้** ออกอาวุธเป็นคลาส `Move` ให้เองด้วย

### 9.2 เทรน

```bash
cd ml_pipeline
pip install -r requirements.txt
python train_model.py --data "./data/*.csv"
```

ได้ผลลัพธ์:

- `strike_web_model.json` — ไฟล์ที่อัปโหลดเข้าแดชบอร์ด
- `strike_model.h` — ทางเลือกสำหรับฝังบน ESP32 (TFLite Micro, int8)
- `confusion_matrix.png` — ดูว่าสับสนท่าไหน

ถ้าแก้ขนาดหน้าต่างหรือโครงโมเดล ให้รัน `python verify_web_model.py`
เพื่อยืนยันว่า inference ฝั่งเบราว์เซอร์ยังตรงกับ Keras

### 9.3 ติดตั้งโมเดลและใช้งาน

1. เปิดแดชบอร์ด → การ์ด **AI MODEL · ตรวจจับท่า**
2. **⬆ เลือกไฟล์โมเดล** → เลือกไฟล์ `.json`
3. สถานะขึ้น `พร้อม · N ท่า · หน้าต่าง 160×6` และเปิดสวิตช์ตรวจจับให้อัตโนมัติ
4. ออกอาวุธ — ระบบแสดงชื่อท่า + % ความมั่นใจ + แถบความน่าจะเป็นของทุกคลาส

### 9.4 คลังโมเดลบน SD card

โมเดลถูกเก็บไว้บน SD ของ Main Node ทำให้:

- เก็บได้หลายโมเดล เลือก active ทีละตัว
- **สลับโมเดลได้จากหน้าเว็บ ไม่ต้อง flash เฟิร์มแวร์ใหม่**
- ทุกเครื่องที่เชื่อมต่อได้โมเดลเดียวกันอัตโนมัติ
- ลบโมเดลที่ไม่ใช้ได้จากหน้าเว็บ

เบราว์เซอร์ยัง cache โมเดลไว้ใน localStorage ด้วย ถ้าดึงจากเครื่องไม่ได้ก็ยังใช้ตัวที่เคยโหลดไว้ได้

---

## 10. ข้อจำกัดที่ควรพูดเอง ก่อนโดนถาม

- **โมเดลตอบได้เฉพาะท่าที่เคยเห็น** ท่าที่ยังไม่ได้เก็บข้อมูลจะถูกตอบเป็นท่าที่ใกล้เคียงที่สุด
  นี่คือการเทียบเคียง ไม่ใช่การวัด หน้าเว็บเขียนกำกับเรื่องนี้ไว้ชัดเจน
- **คู่ท่าที่ต่างกันที่รูปร่างล้วนๆ ยังแยกยาก** — Jab vs Cross, Elbow-Chop vs Elbow-Slash,
  Roundhouse vs Kick-Low ต้องเก็บข้อมูลเพิ่มและเทรนใหม่ ไม่ใช่ปรับเกณฑ์
- **แรงคือค่าที่วัดจริงจาก IMU เสมอ** ไม่ใช่ค่าที่ AI ทำนาย ส่วนนี้ไม่มีการเดา
- **ความแม่นขึ้นกับข้อมูลเทรน** ตัวเลข 80–87% ข้างต้นมาจาก dataset ชุดปัจจุบัน
  ผู้ใช้คนอื่น สรีระอื่น หรือการรัดเซ็นเซอร์ต่างออกไป ควรเก็บข้อมูลของตัวเองเพิ่ม
- **หน้าต่าง 400 ms ตายตัว** ท่าที่ยาวกว่านั้นจะถูกตัดที่จุดกระทบ ซึ่งเป็นการออกแบบ
  ไม่ใช่ข้อบกพร่อง แต่ควรรู้ไว้

---

## 11. คำถามที่มักโดนถาม

**ถาม: ใช้ TensorFlow.js หรือเปล่า**
ไม่ใช้ เขียน forward pass เอง รองรับ conv1d, batch_normalization, max_pooling1d,
global_average_pooling1d, flatten, dense, dropout, activation
ตรวจสอบแล้วว่าผลตรงกับ Keras ที่ระดับ 1e-6

**ถาม: ข้อมูลถูกส่งขึ้น cloud ไหม**
ไม่ ทั้งการ inference และการเก็บข้อมูลอยู่ในเครื่องทั้งหมด ระบบทำงานได้โดยไม่ต้องมีอินเทอร์เน็ต

**ถาม: ทำไมไม่รันโมเดลบน ESP32 ไปเลย**
ทำได้ (pipeline ปล่อย `strike_model.h` แบบ int8 ให้ด้วย) แต่การรันในเบราว์เซอร์
ทำให้เปลี่ยนโมเดลได้โดยไม่ต้อง flash และมีแรงประมวลผลเหลือเฟือกว่า
ส่วน ESP32 เอาไว้ทำงานที่มันถนัดคือรับวิทยุและเขียน SD

**ถาม: ทำไมต้องมีคลาส Idle กับ Move**
เพราะถ้าไม่มี โมเดลไม่มีคำตอบที่ถูกต้องให้เลือกสำหรับการเคลื่อนไหวที่ไม่ใช่การออกอาวุธ
มันจะไปตอบเป็นท่าที่ใกล้ที่สุดแทน ซึ่งคือสาเหตุที่การเดินเคยถูกนับเป็นเตะ

**ถาม: เพิ่มท่าใหม่ต้องทำอะไร**
เก็บข้อมูลท่านั้นด้วย Data Logger → เทรนใหม่ → อัปโหลดไฟล์ใหม่ ไม่ต้องแตะเฟิร์มแวร์

---

## 12. ไฟล์อ้างอิง

| ไฟล์ | หน้าที่ |
|---|---|
| `dashboard/src/motioncapture.js` | MediaPipe 3D Pose landmarker + โหลดโมเดล TensorFlow.js AI |
| `dashboard/src/physics.js` | Gaussian prior และการประมวลผลแรงปะทะ (Live Impact Power) |
| `strikescore.js` | คะแนนความแม่นยำและแรงปะทะ (0–100 Strike Score) |
| `dashboard/src/posemath.js` | เรขาคณิต 3D ของข้อต่อและองศาร่างกาย |
| `dashboard/src/rigclock.js` | ซิงก์เวลาระหว่าง IMU กับกล้องความละเอียดสูง |
| `dashboard/src/rigorigin.js` | พิกัดอ้างอิงของระบบเซนเซอร์และกล้อง |
| `dashboard/src/logger.js` | Data Logger บันทึกไฟล์ CSV สำหรับเทรน AI |
| `ml_pipeline/train_model.py` | Pipeline เทรนโมเดล 1D-CNN ทั้งหมด |
| `ml_pipeline/verify_web_model.py` | ยืนยันว่าโมเดลเบราว์เซอร์ตรงกับ Keras |
| `ml_pipeline/test_detector_parity.py` | ยืนยัน Parity การตัดหน้าต่างระหว่าง Python และ JS |
| `docs/ai-model-guide.md` | คู่มือเชิงเทคนิคของการเทรน/อัปโหลดโมเดล |
| `docs/เทรนโมเดล.md` | คู่มือขั้นตอนการเทรนโมเดล (Model Training User Manual) |

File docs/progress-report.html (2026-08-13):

STRIKESENSE

รายงานความคืบหน้าโครงการ · ระบบเซ็นเซอร์วัดและวิเคราะห์การฝึกมวยไทย

IoT Muay Thai Telemetry System | รายงานวันที่ 4 มิถุนายน 2569

## 1. ภาพรวมโครงการ

ระบบติดตามและวิเคราะห์การฝึกซ้อมมวยไทยแบบเรียลไทม์ ประกอบด้วยอุปกรณ์เซ็นเซอร์สวมใส่ที่ข้อมือและแข้งของนักกีฬา ส่งข้อมูลการเคลื่อนไหวแบบไร้สายมายังตัวรับกลาง พร้อมแสดงผลและวิเคราะห์สถิติบนหน้าเว็บแดชบอร์ด

องค์ประกอบ | หน้าที่
Strike Node | อุปกรณ์สวมใส่ — วัดแรงและการเคลื่อนไหว 400 ครั้ง/วินาที
Main Node | ตัวรับสัญญาณไร้สาย + เซิร์ฟเวอร์แดชบอร์ด + บันทึกข้อมูลลง SD card
Dashboard | หน้าเว็บแสดงผลและวิเคราะห์สถิติการฝึกแบบเรียลไทม์

## 2. ความคืบหน้าโดยรวม

~85%

ส่วนงาน | ความคืบหน้า | สถานะ
ระบบเซ็นเซอร์ + เฟิร์มแวร์ | 90% | ใช้งานได้
ระบบรับส่งข้อมูลไร้สาย | 95% | เสถียร
หน้าเว็บแดชบอร์ด | 95% | ครบฟังก์ชัน
ระบบจัดการพลังงาน/แบตเตอรี่ | 70% | กำลังดำเนินการ
การประกอบภาคสนาม | 30% | เริ่มดำเนินการ

## 3. งานที่เสร็จสมบูรณ์

ฮาร์ดแวร์ & เฟิร์มแวร์

- ✓ เซ็นเซอร์ตรวจวัดการเคลื่อนไหว (ความเร่ง + การหมุน) ความเร็ว 400Hz
- ✓ ส่งข้อมูลไร้สายเสถียร — แก้ปัญหาสัญญาณหลุดเรียบร้อย
- ✓ ระบบชาร์จอัตโนมัติ — เสียบชาร์จพักการทำงานเอง ถอดแล้วกลับมาทำงานทันที
- ✓ ระบบป้องกันแบตเตอรี่เสื่อม (ตัดไฟเมื่อแบตต่ำ)

หน้าเว็บแดชบอร์ด

- ✓ แสดงข้อมูลแรงปะทะแบบเรียลไทม์พร้อมกราฟ
- ✓ จำแนกประเภทหมัด/เตะ (หมัดตรง, ฮุก, อัปเปอร์คัต, เตะ, เข่า ฯลฯ)
- ✓ สถิติการฝึกกว่า 20 รายการ (ความถี่หมัด, แรงสูงสุด, ความสมดุลซ้าย-ขวา, ระดับความล้า)
- ✓ จับเวลายกแบบมวย + บันทึกอัตโนมัติตามรอบ
- ✓ แผนภาพร่างกายแสดงจุดที่โดนตี (heatmap)
- ✓ ระบบปรับเทียบเซ็นเซอร์ (Calibration) ทั้งรายจุดและทั้งตัว
- ✓ คลังบันทึกเซสชัน (ดู / ดาวน์โหลด / เปรียบเทียบ)

## 4. งานที่กำลังดำเนินการ

รายการ | ความคืบหน้า
ระบบวัดเปอร์เซ็นต์แบตเตอรี่ (เขียนโปรแกรมเสร็จ รอต่อวงจร) | 70%
ประกอบต้นแบบบนแผ่นวงจรสำหรับทดสอบภาคสนาม | 30%
ออกแบบกล่อง/เคสสำหรับสวมใส่จริง | เริ่มต้น

## 5. แผนงานขั้นถัดไป

ลำดับ | งาน | ระยะเวลาประมาณ
1 | ประกอบต้นแบบ 1 ชุด + ทดสอบครบทุกฟังก์ชัน | 1 สัปดาห์
2 | ทดสอบใช้งานจริงในยิม (Field Test) | 1–2 สัปดาห์
3 | ปรับแก้จากผลทดสอบ + ประกอบครบ 4 จุด | 1 สัปดาห์
4 | ผลิตแผ่นวงจร PCB เวอร์ชันสมบูรณ์ | 2–3 สัปดาห์

## 6. หมายเหตุ

• ส่วนการวิเคราะห์ด้วย AI อยู่ในความรับผิดชอบของทีม AI แยกต่างหาก โดยระบบนี้ได้เตรียมข้อมูลดิบ (Raw Data) ในรูปแบบที่พร้อมส่งต่อให้แล้ว
• ระบบบันทึกข้อมูลลง SD card ในรูปแบบ CSV สำหรับการวิเคราะห์เชิงลึกภายหลัง

StrikeSense Project · เอกสารรายงานความคืบหน้า · หน้า 1/1

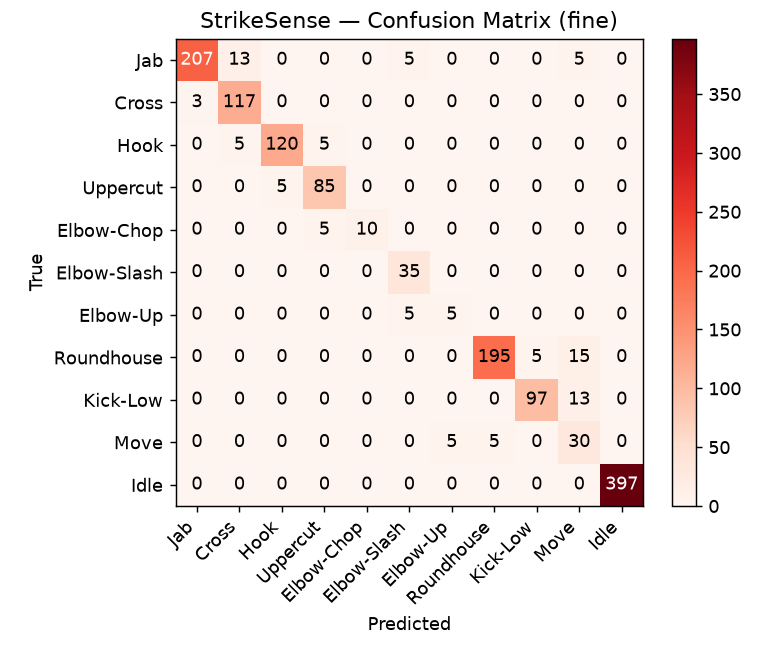
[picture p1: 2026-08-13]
ml_pipeline/confusion_matrix_20260811.png

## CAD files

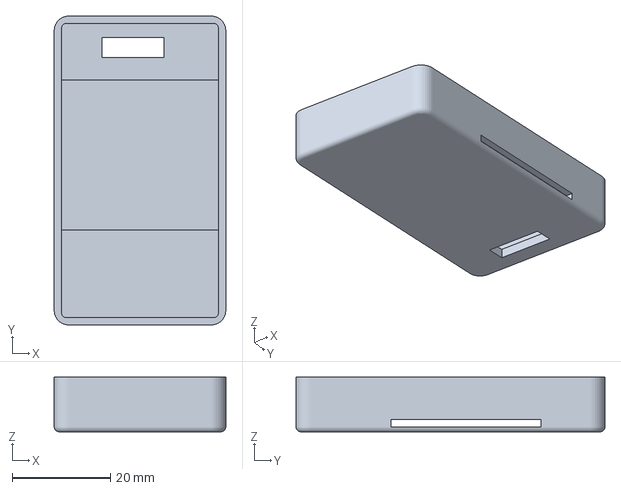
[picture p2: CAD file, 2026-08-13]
Stikesene_Body/Main_body.3mf
35.0 x 63.0 x 11.1 mm

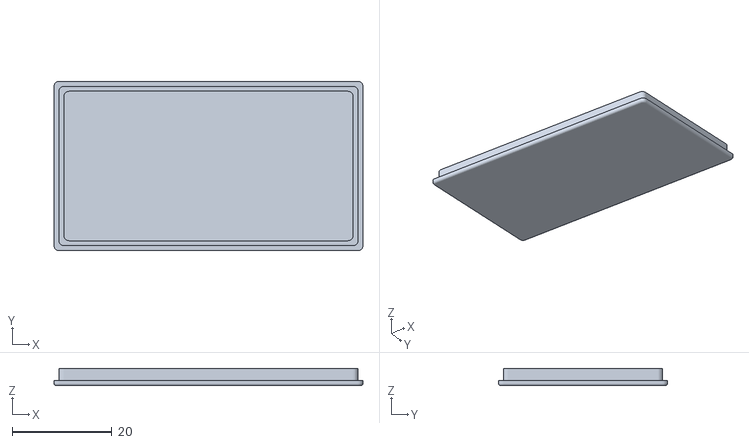
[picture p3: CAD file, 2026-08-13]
Stikesene_Body/Main_Cap.stl
62.0 x 34.0 x 3.50

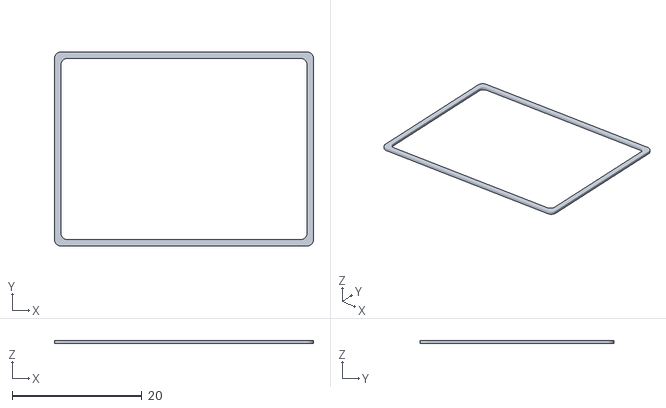
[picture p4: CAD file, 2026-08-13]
Stikesene_Body/Sap_Cap.stl
40.0 x 30.0 x 0.5

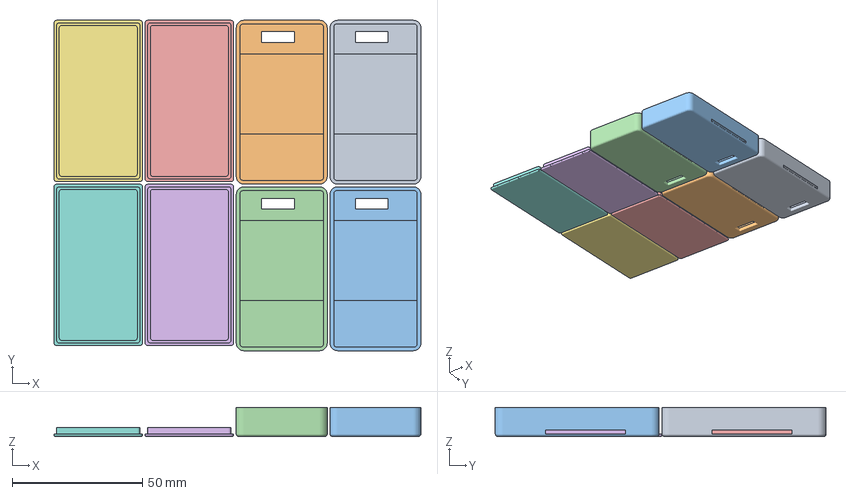
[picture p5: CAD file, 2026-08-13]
Stikesene_Body/StikeSene.3mf
141.0 x 127.0 x 11.1 mm
Main_body.stl x 4
Main_Cap.stl x 4

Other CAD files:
Stikesene_Body/Main_body.stl
Stikesene_Body/stikesene_cap.f3d

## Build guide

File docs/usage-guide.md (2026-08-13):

# StrikeSense — คู่มือการใช้งานสำหรับผู้ใช้และโค้ช (User Manual)

เอกสารนี้เป็นคู่มือแนะนำขั้นตอนการใช้งานระบบ StrikeSense อย่างละเอียด ตั้งแต่การเปิดเครื่อง เชื่อมต่อ การผูกเซนเซอร์ การซ้อมสด การดูสถิติ ไปจนถึงการเก็บข้อมูลและเทรนโมเดล AI

---

## 1. ข้อมูลการเชื่อมต่อ (Connection Settings)

| รายการ | ค่า | หมายเหตุ |
|---|---|---|
| **Wi-Fi SSID** | **`StrikeSense`** | ชื่อเครือข่าย Wi-Fi ที่ปล่อยจาก Main Node |
| **Wi-Fi Password** | **`muaythai123`** | รหัสผ่านเชื่อมต่อ Wi-Fi |
| **Dashboard URL (หลัก)** | **`https://192.168.4.1`** | เปิดผ่าน Safari, Chrome, Edge บนมือถือ/แท็บเล็ต/คอมพิวเตอร์ |
| **Dashboard URL (สำรอง)** | **`http://192.168.4.1`** | กรณีเข้าแบบ HTTP ทั่วไป |

> ⚠️ **หมายเหตุเกี่ยวกับ Motion Capture (กล้อง):** ฟีเจอร์กล้อง Motion Capture (MediaPipe Pose 3D) ยังไม่เปิดใช้งานในเวอร์ชันนี้ ระบบประมวลผลผ่านเซนเซอร์ IMU (400Hz) และโมเดล AI เป็นหลัก

---

## 2. ขั้นตอนการเริ่มต้นใช้งาน (Quick Setup)

1. **เปิด Main Node (ESP32-S3)**:
   - เสียบสาย USB หรือต่อแบตเตอรี่เข้า Main Node
   - สังเกตไฟสถานะ **NeoPixel** ติดสว่าง = ระบบ Wi-Fi AP พร้อมใช้งาน
2. **เชื่อมต่อ Wi-Fi บนอุปกรณ์ของลูกค้า**:
   - บนมือถือ แท็บเล็ต หรือคอมพิวเตอร์ ให้เลือกเชื่อม Wi-Fi **`StrikeSense`** (รหัสผ่าน: `muaythai123`)
3. **เปิดหน้าแดชบอร์ด (Web Dashboard)**:
   - เปิดเบราว์เซอร์แล้วพิมพ์ `https://192.168.4.1` (หรือ `http://192.168.4.1`)
   - ระบบอาจเปิดหน้าเว็บอัตโนมัติ (Captive Portal)
4. **เปิดสวิตช์ Strike Nodes (โหนดเซนเซอร์)**:
   - กดปุ่ม Power บน Strike Node แต่ละตัว (สังเกตไฟ LED กระพริบ)
   - สวมโหนดเข้ากับอวัยวะ (มือซ้าย, มือขวา, แข้งซ้าย, แข้งขวา)

---

## 3. การผูกเซนเซอร์และการตั้งค่าตำแหน่ง (Sensors Management)

ไปที่แท็บ **"เซนเซอร์" (Sensors)** บนหน้าแดชบอร์ด เพื่อตรวจสอบและกำหนดตำแหน่งโหนด:

### 3.1 การตรวจสอบโหนดที่ออนไลน์
- การ์ดแสดงรายการเซนเซอร์จะโชว์ **MAC Address**, **ระดับแบตเตอรี่ (%)**, **ความแรงสัญญาณ (RSSI)** และ **สถานะออนไลน์ (สีเขียว)**

### 3.2 ปุ่มฟังก์ชันในการจัดการโหนด:
- **ปุ่ม "ระบุตำแหน่ง" (Identify / Blink LED)**: กดเพื่อให้เซนเซอร์ตัวนั้นกระพริบไฟ LED เพื่อตรวจสอบว่าคืออุปกรณ์ชิ้นใด
- **ช่องดรอปดาวน์ "กำหนดตำแหน่ง (Slot)"**: เลือกมอบหมายตำแหน่งให้กับเซนเซอร์:
  1. `Left Hand` (มือซ้าย)
  2. `Right Hand` (มือขวา)
  3. `Left Shin` (แข้งซ้าย)
  4. `Right Shin` (แข้งขวา)
- **ปุ่ม "รีบูตโหนด" (Restart Node)**: สั่งรีสตาร์ตเซนเซอร์ตัวนั้นๆ ไร้สาย
- **ปุ่ม "ลืมอุปกรณ์" (Forget)**: ลบการผูกอุปกรณ์ออกจากระบบ

---

## 4. การใช้งานหน้าจอหลักสำหรับการฝึกซ้อม (Live Training Dashboard)

หน้าหลักของแดชบอร์ดได้รับการออกแบบสไตล์ **"Fight Card"** ให้ข้อมูลสดทันทีเมื่อออกอาวุธ:

### 4.1 แผงวัดพลังและสถิติสด (Live Metrics)
- **Live Velocity & G-Force Graph**: กราฟแสดงเส้นความเร็ว ทิศทาง และแรงกระแทกสดแบบ Real-time
- **Live Impact Power ( Peak G )**: ตัวเลขแสดงค่าแรงปะทะสูงสุดและค่าเฉลี่ยทันทีเมื่อมีการปะทะ
- **Strike Indicator (ระบบไฟระบุท่าทาง)**: ไฟกะพริบขึ้นชื่อท่ามวยไทยทันทีตามอาวุธที่นักมวยออกจริง (เช่น JAB, CROSS, HOOK, UPPERCUT, ELBOW, KNEE, KICK) พร้อม % ความมั่นใจของ AI

### 4.2 หุ่นจำลองการปะทะ (Body Hit Diagram & Heatmap)
- **โหมด LIVE**: หุ่น 4 โซน (LH, RH, LS, RS) แฟลชสีแดงทันทีเมื่ออวัยวะนั้นออกอาวุธปะทะ
- **โหมด HEATMAP**: เปลี่ยนสีหุ่นเป็นเฉดสีแดงตามความถี่ปะทะสะสม ช่วยวิเคราะห์ความสมดุลการใช้อาวุธ

### 4.3 ตัววัดสมรรถภาพเชิงลึก (Performance Insights)
- **Strike Counter**: กล่องดิจิทัลนับจำนวนครั้งการออกอาวุธรวม และแยกประเภทอาวุธ
- **SPM (Strikes Per Minute)**: วัดความเร็วอัตราการออกอาวุธต่อนาที
- **Striking Distribution Pie Chart**: กราฟวงกลมแสดงสัดส่วนการใช้อาวุธ (เช่น หมัด 40%, เตะ 30%, เข่า 30%)
- **Asymmetry Ratio (L:R)**: อัตราส่วนการใช้อวัยวะซ้ายเทียบกับขวา ช่วยโค้ชวิเคราะห์ความสมดุลร่างกาย
- **Fatigue & Consistency Tracker**: กราฟและดัชนีเปรียบเทียบแรงปะทะตั้งแต่ต้นจนจบ เพื่อวิเคราะห์ระดับความเหนื่อยล้า
- **Strike Score (0–100)**: ดัชนีคะแนนประเมินคุณภาพความแรงและจังหวะของแต่ละหมัด

---

## 5. ระบบนาฬิกาชกเป็นยก (Boxing Round Timer)

ใช้สำหรับควบคุมการซ้อมและจับเวลาชก:

### 5.1 การตั้งค่าเวลา (Presets)
- เลือกรูปแบบเวลา เช่น `3 ยก × 3 นาที (พัก 1 นาที)`, `5 ยก × 3 นาที`, `custom` หรือโหมดจับเวลาอิสระ (`Stopwatch`)

### 5.2 การควบคุมและการบันทึกอัตโนมัติ (Auto-Record)
- ปุ่มกด: **`START`**, **`PAUSE`**, **`SKIP`**, **`RESET`**
- **สวิตช์ Auto-Record (REC)**: หากเปิดไว้ ระบบจะเริ่มบันทึกข้อมูลการซ้อมลง SD Card อัตโนมัติเมื่อเข้าสู่ช่วงชก (Work) และหยุดชั่วคราวช่วงพักยก (Rest)

### 5.3 การปักหมุดโค้ช (Coach Markers)
- กดปุ่ม **`+ MARKER`** (หรือกดปุ่มคีย์บอร์ด **`M`**) เพื่อปักหมุดเวลาและใส่โน้ตข้อความบันทึกจังหวะสำคัญในการซ้อม

---

## 6. การดูประวัติการซ้อมและการส่งออกข้อมูล (Session Library & Replay)

ไปที่แท็บ **"เซนเซอร์ / ประวัติซ้อม"** บนแดชบอร์ด:

1. **รายการซ้อมย้อนหลัง**: แสดงไฟล์การซ้อมที่บันทึกอยู่ใน SD Card ของ Main Node พร้อมวันที่ ขนาดไฟล์ และชื่อนักกีฬา
2. **ดาวน์โหลด CSV**: กดปุ่ม **"↓ ดาวน์โหลด"** เพื่อเซฟไฟล์สถิติ 400Hz เข้าคอมพิวเตอร์/มือถือ
3. **ดูตัวอย่าง (Preview / Replay)**: กดปุ่ม **"VIEW"** เพื่อโหลดกราฟ สถิติย้อนหลัง และเส้นเวลา (Timeline Strip) ขึ้นมาวิเคราะห์
4. **เปรียบเทียบเซสชัน (Compare)**: ติ๊กเลือก 2 ไฟล์แล้วกด **"COMPARE"** เพื่อเปรียบเทียบความแตกต่างทางกายภาพระหว่างรอบซ้อม
5. **ลบไฟล์**: กดปุ่ม **"DELETE"** เพื่อลบไฟล์ออกจาก SD Card

---

## 7. โหมดการเก็บข้อมูลเพื่อเทรน AI (Data Logger Mode)

หากต้องการเก็บข้อมูลเพิ่มเพื่อเทรนโมเดล AI ให้จำจำท่าใหม่ๆ ได้แม่นยำยิ่งขึ้น:

### 7.1 ขั้นตอนการเก็บข้อมูล
1. ไปที่แท็บ **ระบบ** → เปิดสวิตช์ **"โหมดนักพัฒนา" (Developer Mode)**
2. ที่แผง **"AI TRAINING · DATA LOGGER"** ทางด้านซ้าย ให้เลือกท่าที่จะบันทึก (เช่น หมัดแย็บ, ฮุค, เตะตัด, แทงเข่า)
3. กด **"เริ่มบันทึก"**
4. ให้นักมวยออก **ท่าเดิมซ้ำๆ ประมาณ 30–50 ครั้ง** (ออกอาวุธเต็มแรง, เว้นจังหวะ 0.5 วินาที)
5. กด **"หยุดบันทึก"**
6. เลือกท่าถัดไป แล้วทำซ้ำข้อ 3–5
7. เมื่อเก็บครบทุกท่า ให้กด **"↓ ส่งออกทั้งหมด"** เพื่อดาวน์โหลดไฟล์ CSV เข้าเครื่อง

---

## 8. การเทรนและการอัปโหลดโมเดล AI (AI Model Retraining & Upload)

### 8.1 การเทรนโมเดลบนคอมพิวเตอร์ (ทำเพียงคำสั่งเดียว)
นำไฟล์ CSV จากโฟลเดอร์ Downloads มาที่คอมพิวเตอร์ แล้วรันคำสั่ง:

- **สำหรับ macOS / Linux**:
  ```bash
  cd ~/Documents/GitHub/StrikeSense && ./ml_pipeline/retrain.sh
  ```
- **สำหรับ Windows**:
  ```cmd
  cd %USERPROFILE%\Documents\GitHub\StrikeSense && .\ml_pipeline\retrain.bat
  ```
  *(หรือดับเบิลคลิกไฟล์ `retrain.bat` ในโฟลเดอร์ `ml_pipeline` ได้เลย)*

ผลลัพธ์จะได้ไฟล์โมเดลใหม่ชื่อ: `ml_pipeline/strike_web_model_fine.json`

### 8.2 การอัปโหลดโมเดลเข้าใช้งาน
1. เปิดแดชบอร์ด **`https://192.168.4.1`** → ไปที่แท็บ **ระบบ**
2. หัวข้อ **"คลังโมเดล AI"** กดปุ่ม **"เพิ่มไฟล์โมเดล"**
3. เลือกไฟล์ `strike_web_model_fine.json` ที่เพิ่งเทรนเสร็จ
4. ระบบจะบันทึกโมเดลลง SD Card ของ Main Node (`/models/`) และเปิดใช้งานโมเดลใหม่ในเบราว์เซอร์อัตโนมัติ **โดยไม่ต้อง flash เฟิร์มแวร์ ESP32 ใหม่**

---

## 9. การตั้งค่าระบบและการรีเซ็ต (System Diagnostics & Reset)

ไปที่แท็บ **ระบบ** บนแดชบอร์ด:

- **การปรับแต่งการตรวจจับ (Detection Tuning)**:
  - **G-Force Threshold**: ปรับค่าแรงปะทะขั้นต่ำที่ถือเป็น 1 หมัด/เตะ (ค่าเริ่มต้น 3.0g)
  - **Refractory Window**: ปรับเวลากันนับซ้ำ (ค่าเริ่มต้น 250ms)
- **การรีเซ็ตและการดูแลรักษา**:
  - **รีสตาร์ทไร้สาย (Radio Restart)**: รีเซ็ตสัญญาณ ESP-NOW หากเซนเซอร์หลุด
  - **รีบูตเครื่อง (Reboot)**: สั่งรีสตาร์ตสมองกล Main Node
  - **รีเซ็ตเป็นค่าโรงงาน (Factory Reset)**: ล้างค่าความจำเซนเซอร์และการตั้งค่าทั้งหมด

---

## 10. ตารางคีย์บอร์ดลัด (Keyboard Shortcuts)

เมื่อใช้งานบนโน้ตบุ๊กหรือคอมพิวเตอร์ สามารถใช้คีย์ลัดสั่งงานได้ทันที:

| คีย์บอร์ด | คำสั่งการทำงาน |
|:---:|:---|
| **Spacebar** | เริ่ม / หยุด การบันทึกซ้อม (REC Toggle) |
| **R** | รีเซ็ตนาฬิกายกซ้อม (Reset Round Timer) |
| **S** | ข้ามช่วงเวลาพัก/ชก (Skip Phase) |
| **M** | ปักหมุดโน้ตโค้ช (Add Coach Marker) |
| **F** | เปิด/ปิด โหมดเต็มหน้าจอ (Toggle Fullscreen) |
| **H** | เปิด/ปิด หุ่นความถี่การปะทะ (Toggle Heatmap) |
| **T** | เปลี่ยนธีม มืด/สว่าง (Toggle Dark/Light Theme) |
| **1 – 4** | กรองสถิติแยกตามเซนเซอร์ slot 1-4 |
| **0** | ดูสถิติรวมเซนเซอร์ทุกจุด |
| **Esc** | ปิดหน้าต่างป๊อปอัป (Close Modal) |

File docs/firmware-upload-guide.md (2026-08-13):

# StrikeSense — คู่มืออัปโหลดเฟิร์มแวร์ด้วยตนเอง (Main Node ESP32-S3)

เอกสารนี้อธิบาย **2 วิธี** ในการ build + flash เฟิร์มแวร์ Main Node เข้า ESP32-S3
1. **Arduino IDE (GUI)** — ง่ายสำหรับใช้งานทั่วไป
2. **arduino-cli (Terminal)** — เร็ว ทำซ้ำได้ เหมาะกับ workflow นักพัฒนา (วิธีที่สคริปต์ในโปรเจกต์นี้ใช้)

> ทั้งสองวิธีต้องตั้งค่า **Board Settings ให้ตรงกัน** ไม่งั้นบอร์ดจะบูตไม่ขึ้นหรือ serve dashboard ไม่ได้

---

## 0. สิ่งที่ต้องเตรียมครั้งแรก (ทำครั้งเดียว)

### 0.1 Board package
- **esp32 by Espressif Systems v3.x** (โปรเจกต์นี้เทสกับ 3.3.10)

### 0.2 Libraries (Library Manager) — ต้องเป็น fork ที่ถูกต้อง (org **ESP32Async**)
| Library | ผู้เผยแพร่ | เวอร์ชันที่ใช้ |
|---|---|---|
| **Async TCP** | ESP32Async | 3.4.10 |
| **ESP Async WebServer** | ESP32Async | 3.11.2 |
| **ArduinoJson** | Benoit Blanchon | 7.4.3 |
| **Adafruit NeoPixel** | Adafruit | 1.15.5 |

> ⚠️ ระวังของปลอม/fork อื่น เช่น `AsyncTCP` by *dvarrel* หรือ ESPAsyncWebServer เวอร์ชันเก่า — จะ compile ไม่ผ่านหรือ WebSocket มีปัญหา ต้องเลือกผู้เผยแพร่ **ESP32Async** เท่านั้น

### 0.3 Board Settings (สำคัญมาก — ตั้งให้ครบทุกข้อ)
เฟิร์มแวร์ระบุไว้ในหัวไฟล์ [`firmware/main-node/main-node.ino`](../firmware/main-node/main-node.ino):

| Setting | ค่า | เหตุผล |
|---|---|---|
| Board | **ESP32S3 Dev Module** | ตรงกับฮาร์ดแวร์ |
| Flash Size | **8MB (64Mb)** | พื้นที่เก็บโปรแกรม |
| PSRAM | **OPI PSRAM** | บัฟเฟอร์ WebSocket/heap |
| Partition Scheme | **8M with spiffs (3MB APP/1.5MB SPIFFS)** | ให้ APP 3MB พอสำหรับ web server |
| USB CDC On Boot | **Enabled** | ให้ `Serial` ออกทาง USB (debug) |
| Upload Speed | **921600** | อัปโหลดเร็ว |

---

## วิธีที่ 1 — Arduino IDE (GUI)

1. เปิดโฟลเดอร์ `firmware/main-node/` → ดับเบิลคลิก `main-node.ino`
   (Arduino IDE จะเปิดทุกไฟล์ในโฟลเดอร์รวมถึง `dashboard_ui.h` โดยอัตโนมัติ)
2. **Tools → Board → esp32 → ESP32S3 Dev Module**
3. ตั้งค่า **Tools** ให้ตรงตารางข้อ 0.3 ทุกบรรทัด
4. เสียบ ESP32-S3 → **Tools → Port** → เลือกพอร์ต (macOS: `/dev/cu.usbmodem…`)
5. กด **Upload (→)**
6. ถ้าบอร์ดไม่เข้าโหมด download เอง: กดค้าง **BOOT** → แตะ **RESET** → ปล่อย **BOOT** แล้วกด Upload อีกครั้ง

---

## วิธีที่ 2 — arduino-cli (Terminal / Command Prompt) ✅ วิธีแนะนำ

Arduino IDE 2.x มี `arduino-cli` ฝังอยู่ในตัว ไม่ต้องติดตั้งเพิ่ม:

###  สำหรับ macOS:
```bash
CLI="/Applications/Arduino IDE.app/Contents/Resources/app/lib/backend/resources/arduino-cli"
```

### ⊞ สำหรับ Windows (Command Prompt / PowerShell):
```cmd
set CLI="C:\Program Files\Arduino IDE\resources\app\lib\backend\resources\arduino-cli.exe"
```
*(หากติดตั้ง `arduino-cli` ไว้ใน PATH แล้ว สามารถพิมพ์ `arduino-cli` ได้โดยตรง)*

---

### 2.1 ติดตั้ง core + libraries (ทำครั้งเดียว)

#### macOS:
```bash
"$CLI" core install esp32:esp32
"$CLI" lib install "Async TCP" "ESP Async WebServer" "ArduinoJson" "Adafruit NeoPixel"
```

#### Windows:
```cmd
%CLI% core install esp32:esp32
%CLI% lib install "Async TCP" "ESP Async WebServer" "ArduinoJson" "Adafruit NeoPixel"
```

---

### 2.2 หาพอร์ตอุปกรณ์

```bash
# macOS / Windows
"$CLI" board list
```
- **macOS**: มองหาพอร์ตที่เป็น `/dev/cu.usbmodem...` หรือ `/dev/cu.usbserial...`
- **Windows**: มองหาพอร์ตที่เป็น `COM3`, `COM4`, `COM5` เป็นต้น

---

### 2.3 Compile + Upload Main Node (ESP32-S3)

####  สำหรับ macOS:
```bash
FQBN="esp32:esp32:esp32s3:PSRAM=opi,FlashSize=8M,PartitionScheme=default_8MB,CDCOnBoot=cdc,UploadSpeed=921600"
PORT="/dev/cu.usbmodem101"

cd firmware
"$CLI" compile --fqbn "$FQBN" main-node
"$CLI" upload -p "$PORT" --fqbn "$FQBN" main-node
```

#### ⊞ สำหรับ Windows (Command Prompt):
```cmd
set FQBN=esp32:esp32:esp32s3:PSRAM=opi,FlashSize=8M,PartitionScheme=default_8MB,CDCOnBoot=cdc,UploadSpeed=921600
set PORT=COM3

cd firmware
%CLI% compile --fqbn %FQBN% main-node
%CLI% upload -p %PORT% --fqbn %FQBN% main-node
```

สำเร็จเมื่อเห็น:
```
Hash of data verified.
Hard resetting via RTS pin...
```

### 2.4 ดู Serial log (ตรวจว่าบูตจริง)
```bash
"$CLI" monitor -p "$PORT" -c baudrate=115200
```
ควรเห็น:
```
=== StrikeSense Main Node (Arduino IDE build) ===
Build: <วันเวลาที่ build ล่าสุด>     ← ยืนยันว่าเป็นเฟิร์มแวร์ใหม่
[STATS] rx=0 drop=0 ws=0 sess=off sd=... heap=...
```
กด `Ctrl+C` เพื่อออก

---

## 3. Workflow เต็ม: แก้ dashboard → อัปเฟิร์มแวร์

dashboard ถูกฝังเป็น PROGMEM ในไฟล์ `dashboard_ui.h` **ต้อง build ใหม่ทุกครั้งที่แก้ UI**:

```bash
cd dashboard
npm install          # ครั้งแรกครั้งเดียว
npm run build        # vite build → gen dashboard_ui.h อัตโนมัติ
# แล้วค่อย compile + upload ตามข้อ 2.3
```

`npm run build` ทำ 2 อย่าง (ดู [`dashboard/package.json`](../dashboard/package.json)):
1. `vite build` → รวมทุกอย่างเป็น `dist/index.html` ไฟล์เดียว (inline JS/CSS)
2. `node build-cpp.js` → แปลง `dist/index.html` เป็น C-array ใน `firmware/main-node/dashboard_ui.h`

---

## 4. การอัปโหลดเฟิร์มแวร์ Strike Node (ESP32-C3 SuperMini)

Strike Node คือโหนดเซนเซอร์ติดข้อมือ/หน้าแข้ง (ESP32-C3 + BMI160 IMU):

### Board Settings (ESP32-C3):
- **Board**: `ESP32C3 Dev Module`
- **Flash Size**: `4MB`
- **USB CDC On Boot**: `Disabled` (หรือ Enabled ตามชนิด SuperMini)
- **Upload Speed**: `921600`

### การ Compile & Flash ด้วย `arduino-cli`:
```bash
FQBN_C3="esp32:esp32:esp32c3"
PORT_C3="/dev/cu.usbmodem201"

cd firmware
"$CLI" compile --fqbn "$FQBN_C3" strike-node
"$CLI" upload -p "$PORT_C3" --fqbn "$FQBN_C3" strike-node
```

---

## 5. Workflow: เทรน AI → อัปโหลดโมเดลเข้าใช้งาน

```bash
# 1) เก็บข้อมูลจาก dashboard → ได้ไฟล์ strike_*.csv หลายไฟล์ใน ~/Downloads/
# 2) เทรน + export โมเดลเป็น TensorFlow.js JSON
./ml_pipeline/retrain.sh     # ได้ไฟล์ ml_pipeline/strike_web_model_fine.json
```

**การอัปโหลดเข้าใช้งาน (ไม่ต้อง re-flash ESP32):**
1. เปิด Web Dashboard ที่ **`https://192.168.4.1`**
2. ไปที่แท็บ **ระบบ** → **คลังโมเดล AI**
3. กด **"เพิ่มไฟล์โมเดล"** → เลือกไฟล์ `strike_web_model_fine.json`
4. โมเดลจะถูกบันทึกใน SD Card ของ Main Node (`/models/`) และนำมาใช้วิเคราะห์ท่าในเบราว์เซอร์ทันที

---

## 6. Troubleshooting

| อาการ | สาเหตุ / วิธีแก้ |
|---|---|
| `A fatal error occurred: Failed to connect` | บอร์ดไม่เข้า download mode → กดค้าง BOOT + แตะ RESET + ปล่อย BOOT แล้ว upload ใหม่ |
| compile error หา `ESPAsyncWebServer.h` ไม่เจอ | ติดตั้ง lib ผิด fork → ต้องเป็น **ESP32Async** (ข้อ 0.2) |
| บอร์ดบูตแล้ว restart วน (boot loop) | Partition/PSRAM ตั้งผิด → เช็คข้อ 0.3 (โดยเฉพาะ OPI PSRAM + 8M partition) |
| เปิด dashboard แล้วขาว/เก่า | ลืม `npm run build` ก่อน flash → dashboard_ui.h ยังเป็นของเก่า |
| `sd=ERR` ใน serial | ไม่มี SD card เสียบ (การเก็บ log ลง SD ใช้ไม่ได้ แต่ dashboard + WebSocket ทำงานปกติ) |
| Serial ว่างเปล่าตอนอ่านด้วย `cat`/`head` | ESP32-S3 native USB CDC ต้อง assert DTR — ใช้ `arduino-cli monitor` แทน |

---

## 7. เชื่อมต่อใช้งานหลัง flash
1. เชื่อม Wi-Fi: **SSID `StrikeSense` · รหัส `muaythai123`**
2. หลัง provision certificate ตาม [motion-capture-https](motion-capture-https.md)
   ให้เปิดเบราว์เซอร์ → **https://192.168.4.1** สำหรับ Local CA หรือ
   **`https://<hostname>`** สำหรับ Let's Encrypt (ชื่อใน `/tls/hostname.txt`)
   — จำเป็นสำหรับ camera/WSS
3. Data Logger อยู่แถบซ้าย ("AI TRAINING · DATA LOGGER")

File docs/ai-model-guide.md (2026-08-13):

# AI Model — เทรน → อัปโหลดเข้าแดชบอร์ด → ตรวจจับท่าเรียลไทม์

> **คู่มือขั้นตอนการใช้งาน (User Manual)** → อ่าน [เทรนโมเดล.md](./เทรนโมเดล.md)
> เอกสารนี้เน้นรายละเอียดเชิงเทคนิค ส่วนคู่มือเน้นการปฏิบัติงานขั้นตอนการเทรน

เอกสารนี้อธิบายวิธีนำโมเดล AI ที่เทรนเสร็จแล้วมา "เสียบ" เข้าแดชบอร์ด StrikeSense
เพื่อให้ระบบตรวจจับท่ามวยแบบเรียลไทม์

โมเดลรัน **ในเบราว์เซอร์** (in-browser 1D-CNN) — ผู้ใช้อัปโหลดไฟล์โมเดลตอนใช้งาน
ไม่ต้องฝังลง ESP32 และเปลี่ยนโมเดลใหม่ได้โดยไม่ต้อง flash เฟิร์มแวร์ซ้ำ

```
Data Logger (dashboard)  ──►  strike_*.csv
      │  เก็บ raw IMU 400Hz + ป้ายท่า
      ▼
ml_pipeline/train_model.py  ──►  strike_web_model_fine.json   (โมเดลสำหรับเบราว์เซอร์)
      │                     └─►  strike_model_fine.h          (ทางเลือก: ฝังบน C++)
      ▼
แดชบอร์ด → แท็บระบบ → "คลังโมเดล AI" → อัปโหลด .json → บันทึกลง SD Card (/models/)
      ▼
ทายท่าอัตโนมัติทุกครั้งที่ออกอาวุธ (โชว์ท่า + % ความมั่นใจ + Strike Score)
```

## 1. เก็บข้อมูล (Data Logger)

1. เปิด Developer mode ในแดชบอร์ด (แท็บ **ระบบ** → เปิด โหมดนักพัฒนา)
2. ที่การ์ด **AI TRAINING · DATA LOGGER** เลือกท่าที่จะบันทึก → กด **เริ่มบันทึก** → ออกอาวุธ → **หยุด**
3. กด **↓ ส่งออกทั้งหมด** เพื่อดาวน์โหลด CSV
4. นำไฟล์ไปวางใน `ml_pipeline/data/` (สคริปต์ `retrain.sh` ย้ายเข้าให้อัตโนมัติ)

## 2. เทรนโมเดล

```bash
# เทรนอัตโนมัติด้วย retrain.sh
./ml_pipeline/retrain.sh

# หรือรัน train_model.py โดยตรง
cd ml_pipeline
pip install -r requirements.txt
python train_model.py --data "./data/*.csv"
```

ตัวเลือกความละเอียดของคลาสด้วย `--mode`:

| โหมด | คลาส | เหมาะกับ |
|---|---|---|
| `coarse` (ค่าเริ่มต้น) | 5 อาวุธ (หมัด/ศอก/เข่า/เตะ/ถีบ) | ข้อมูลไม่มาก แม่นและเสถียร |
| `coarse_lr` | 10 คลาส = 5 อาวุธ × ซ้าย-ขวา | ต้องเก็บครบซ้าย-ขวา |
| `fine` | ~20 ท่าย่อย | ต้องมี dataset ใหญ่ |

ผลลัพธ์ที่ได้:
- **`strike_web_model_fine.json`** ← ไฟล์ที่อัปโหลดเข้าแดชบอร์ด (ข้อ 3)
- `strike_model_fine.h` ← ทางเลือก C++ header สำหรับ embedded C++ reference
- `confusion_matrix.png` ← ดูว่าโมเดลสับสนท่าไหนบ้าง

> เปลี่ยนขนาดหน้าต่าง/ความลึกโมเดลได้ที่หัวไฟล์ `train_model.py` (`TIME_STEPS`, `build_model`)
> — รัน `python verify_web_model.py` เพื่อยืนยันว่า inference ฝั่งเบราว์เซอร์ยังตรงกับ Keras

## 3. อัปโหลดเข้าแดชบอร์ดและ SD Card

1. เปิดแดชบอร์ด → แท็บ **ระบบ** → หัวข้อ **คลังโมเดล AI**
2. กด **"เพิ่มไฟล์โมเดล"** → เลือก `strike_web_model_fine.json`
3. ไฟล์จะถูกสตรีมส่งไปยัง Main Node และบันทึกเก็บใน SD Card (`/models/strike_web_model_fine.json`)
4. ระบบเปิด **"เปิดตรวจจับท่าด้วย AI"** ให้อัตโนมัติ และโหลดโมเดลเข้าเบราว์เซอร์
5. เมื่อออกอาวุธ — ระบบจะวิเคราะห์ท่าผ่าน 1D-CNN + Physics engine สดๆ บนหน้าจอ

## วิธีทำงานภายใน (สรุป)

- IMU ดิบ 400Hz เข้ามาทาง WebSocket → เก็บเป็น ring buffer ต่อโหนด (ค่าดิบ ตรงกับตอนเทรน)
- เมื่อ detector จับได้ว่ามีการออกอาวุธ → ตัดหน้าต่าง `TIME_STEPS` ตัวอย่างล่าสุด → normalize ด้วย mean/std จากตอนเทรน → รันผ่าน 1D-CNN ในเบราว์เซอร์ (`dashboard/src/motioncapture.js`)
- ทำงานร่วมกับ `physics.js` (Gaussian priors) และ `strikescore.js` (ประเมินคะแนนแรงปะทะ)
- โมเดลทำงานแบบ offline ได้เต็มรูปแบบ และทดสอบความถูกต้องกับ Keras ระดับ 1e-6 ด้วย `verify_web_model.py`

## หมายเหตุ: แดชบอร์ดฝังอยู่ในเฟิร์มแวร์

ตัวแดชบอร์ดถูก build แล้วฝังเป็น `firmware/main-node/dashboard_ui.h` (PROGMEM)
ดังนั้นเมื่อแก้โค้ดแดชบอร์ดต้อง rebuild + flash Main Node ใหม่:

```bash
cd dashboard && npm run build      # สร้าง dist + regenerate dashboard_ui.h
# แล้ว flash ตาม docs/firmware-upload-guide.md
```

ส่วน **ไฟล์โมเดล (.json)** ไม่ได้ฝังในเฟิร์มแวร์ — อัปโหลดตอน runtime จึงเปลี่ยนโมเดลได้โดยไม่ต้อง flash

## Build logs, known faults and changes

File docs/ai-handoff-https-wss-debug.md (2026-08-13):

# StrikeSense — AI Handoff: HTTPS/WSS Stability Debug

Updated: 2026-08-12 (Asia/Bangkok)

This document is a handoff for the **current active problem**: the secure
mobile dashboard loads at `https://pokoman.online/`, but its connection badge
remains Offline / flaps because WSS has not successfully stayed connected.

> **Status update — 2026-08-12, later the same day.** Three separate causes of
> the permanent `ws=0` were found and fixed (see
> [Resolution: why `ws=0` was permanent](#resolution-why-ws0-was-permanent),
> which supersedes the "Recommended next debugging steps" list below — that is
> kept only for the reasoning it records). None of them was TLS or the radio.
>
> **The rig has since been rolled back to HTTP at the user's decision**, and
> that build is what the board now runs. It is the pre-HTTPS firmware carrying
> the *current* dashboard, so every UI and touch fix is present; only the camera
> is unavailable, because `getUserMedia()` requires a secure context. The
> WebSocket came up on the first try there — `ws 1`, free heap 160 KiB against
> 33–50 KiB under HTTPS. Build and instructions:
> `~/Documents/GitHub/StrikeSense-backups/firmware-http-newui-20260812/`.
>
> The HTTPS work is intact in the working tree and none of it was reverted. Read
> [What is left before HTTPS can work](#what-is-left-before-https-can-work)
> before picking it up again.

## User goal

The rig must work entirely in a mobile browser, without a native app:

- phone camera motion capture via MediaPipe Pose Landmarker;
- IMU force/strike detection from four Strike Nodes;
- left/right hands and legs, with 3-D joint angles fused with each strike;
- trusted HTTPS and WSS, so `getUserMedia()` is allowed on phones;
- no cloud runtime dependency while using the rig.

The user has asked that the connection/traffic issue be fixed. They have
authorized firmware flashing and the Main Node is connected over USB.

## Hardware/runtime facts

- Main Node: ESP32-S3, OPI PSRAM 8 MiB, USB serial
  `/dev/cu.usbmodem101`.
- Arduino core: 3.3.11. Correct FQBN used for compile/upload:

  ```sh
  esp32:esp32:esp32s3:CDCOnBoot=cdc,FlashSize=8M,PartitionScheme=default_8MB,PSRAM=opi,UploadSpeed=921600
  ```

- SoftAP address: `192.168.4.1`.
- Four IMU nodes normally send about 140–150 packets/s combined. During the
  failing HTTPS tests, ESP-NOW itself stayed healthy (`rx` climbing; zero or
  very low drops), so this is primarily a TLS/web transport issue—not a radio
  sensor failure.
- The current board was flashed successfully with the latest local source in
  this worktree. No changes have been committed.

## Certificate and DNS

- Let’s Encrypt certificate for **`pokoman.online`** was successfully issued.
- It expires **2026-11-09**.
- Certificate/key/hostname were installed on the rig SD card as:

  ```text
  /tls/server-cert.pem
  /tls/server-key.pem
  /tls/hostname.txt       # contains pokoman.online
  ```

- Do **not** commit or expose the private key. The certificate source/config
  lives outside this repository under the user’s Library/Application Support
  directory.
- Public DNS is Z.com. The DNS-01 TXT record was manually created to issue the
  certificate. Renewal is manual unless a DNS API workflow is added later.
- The browser must open **`https://pokoman.online/`**, not
  `https://192.168.4.1/`; the certificate only has a DNS SAN for
  `pokoman.online`.

## MediaPipe SD assets

Assets were installed and checksum-verified under:

```text
/mocap/mediapipe/0.10.35/
  wasm/vision_wasm_internal.js
  wasm/vision_wasm_internal.wasm
  wasm/vision_wasm_nosimd_internal.js
  wasm/vision_wasm_nosimd_internal.wasm
  models/pose_landmarker_lite.task
```

The firmware exposes only these exact assets over secure `/mocap/*` paths. It
must never expose arbitrary SD paths because the card also contains sessions
and TLS material.

## Feature implementation already present

### Browser motion capture

- `dashboard/src/motioncapture.js`: on-device MediaPipe pose capture,
  throttled video inference, camera permission UX, overlay/status.
- `dashboard/src/posemath.js`: maps sensor slots to anatomy and calculates
  visibility-gated 3-D angles.
- Fixed slots:
  - 1 = left hand
  - 2 = right hand
  - 3 = left shin/leg
  - 4 = right shin/leg
- IMU remains the **only force metric**. Pose is attached to an impact as
  form/angles/quality metadata.
- `dashboard/src/rigclock.js` maps Main Node receive timestamps to the page’s
  monotonic clock for pose/impact matching.
- Frontend tests passed before this handoff (`npm test`: 107 tests) and the
  dashboard build passed.

### Firmware HTTPS/WSS implementation

The native ESP-IDF `esp_https_server` is used because the installed
ESPAsyncWebServer/AsyncTCP stack cannot provide server-side TLS.

Relevant file:

```text
firmware/main-node/main-node.ino
```

It currently:

- serves the embedded dashboard on HTTPS :443;
- proxies existing `/api/*` calls to the legacy local HTTP server;
- exposes `/ws` through native WSS;
- sends IMU batches through `httpd_queue_work()`;
- serves five allowlisted MediaPipe files from SD;
- loads cert/key from SD at boot;
- redirects HTTP human entry pages to `https://pokoman.online/` once TLS is
  ready.

## Changes made during this debug session

These edits are in the dirty working tree and were included in the latest
firmware flash.

### 1. Removed external Google Fonts from the embedded dashboard

`dashboard/index.html` no longer requests Google Fonts. This was critical:
the old captive DNS wildcard resolved `fonts.googleapis.com` and
`fonts.gstatic.com` to the rig, but the rig presented a certificate for
`pokoman.online`. The phone therefore generated wrong-SNI TLS failures before
WSS could connect.

`npm run build` was run after the edit, regenerating:

```text
firmware/main-node/dashboard_ui.h
```

Verify before another flash:

```sh
! rg -n 'fonts\.googleapis|fonts\.gstatic' dashboard/dist/index.html firmware/main-node/dashboard_ui.h
```

### 2. Secure DNS is now exact-host, not wildcard

When HTTPS starts successfully, the AP DNS server replies only for
`pokoman.online` and answers other names with NXDOMAIN. The legacy HTTP
fallback retains wildcard captive DNS.

Purpose: stop OS connectivity probes and third-party hostnames from being
sent to the TLS listener with certificate-mismatched SNI.

Trade-off: secure mode deliberately does **not** offer an automatic captive
portal popup. The user must open `https://pokoman.online/`. If a phone uses
Private DNS / Private Relay and cannot resolve this name locally, disable that
feature for the StrikeSense Wi-Fi network while testing.

### 3. TLS session policy is intentionally small

Current configuration in `main-node.ino`:

```cpp
static constexpr size_t HTTPS_MAX_OPEN_SOCKETS = 2;
config.httpd.lru_purge_enable = false;
config.tls_handshake_timeout_ms = 4000;
```

Important correction: ESP-IDF's `max_open_sockets` means **client sessions**.
The HTTP server’s listen/control sockets are additional. Earlier reasoning
that set this to 5 was wrong and would permit five large TLS sessions.

The target is exactly:

1. one long-lived WSS connection;
2. one transient serialized HTTPS REST request.

`lru_purge_enable` must remain `false`: a server-push WSS connection does not
receive requests frequently, so LRU eviction can choose and kill WSS, causing
an Offline/Live reconnect loop.

### 4. The AP accepts one browser device

Current config sets:

```cpp
#define AP_MAX_CLIENTS 1
WiFi.softAP(AP_SSID, AP_PASSWORD, AP_CHANNEL, 0, AP_MAX_CLIENTS);
```

Live serial logs showed two distinct Wi-Fi stations during the failure. Each
TLS browser can consume roughly 50 KiB internal RAM; two phones are not a
supported secure topology on this ESP32-S3 build. Keep only one phone/tablet
connected to `StrikeSense` during secure testing.

### 5. REST request serialization and traffic reduction

`dashboard/src/api.js` now keeps a **permanent one-request lane on HTTPS**,
not just during page bootstrap. Identical outstanding GETs are single-flight
coalesced.

`dashboard/src/setup.js` now:

- reduces shake polling from 220 ms to 500 ms;
- has in-flight guards so it cannot stack async `/api/nodes` requests.

`dashboard/src/ws.js` now respects a pending reconnect backoff when the
mobile browser emits focus/online/pageshow bursts.

`dashboard/src/freshness.js` skips its whole-dashboard re-fetch on HTTPS;
that request bypassed the API lane and competed with live telemetry.

`dashboard/src/main.js` currently starts WSS only after initial hydration.
This was intended to avoid a third simultaneous TLS session during first load.
If debugging continues, verify whether this causes WSS to start too late or
never starts because bootstrap fetches get stuck.

### 6. Native HTTPS handler memory/closure hardening

- Large proxy headers and I/O scratch were moved out of the HTTPS task stack
  into a shared PSRAM scratch structure.
- Header limit reduced from 4096 to 2048 bytes, sufficient for the bounded
  local API response headers.
- One-shot dashboard, API, error, secure-status, and MediaPipe responses add
  `Connection: close` and call `httpd_sess_trigger_close()` after response
  writes to release the scarce TLS client slot.
- MediaPipe asset transfers also explicitly close after completion.

The original proxy handler had two 4 KiB header arrays plus other parser
locals and 2 KiB helper I/O buffers on a 12 KiB HTTPD task stack. That was a
credible source of the observed Guru Meditation under TLS load.

## Live evidence from the failing rig

Observed on `/dev/cu.usbmodem101` before/while patching:

- `[HTTPS] Listening on https://pokoman.online/` appeared on prior boots.
- Errors included:

  ```text
  mbedtls_ssl_handshake returned -0x7F00  # allocation failure
  mbedtls_ssl_handshake returned -0x6E00  # handshake failure
  mbedtls_ssl_handshake returned -0x7280  # peer closed / EOF
  mbedtls_ssl_handshake returned -0x7780  # client fatal alert
  ... TLS handshake timeout (0x8009)
  Guru Meditation Error: Core 1 LoadProhibited   # occurred once in old build
  ```

- Baseline internal free heap after boot was about 145–149 KiB.
- A TLS page connection dropped this by roughly 50–70 KiB.
- With two active stations/requests, heap fell to roughly 33–50 KiB and WSS
  was never established (`ws=0`).
- The dashboard did transfer successfully, for example:

  ```text
  [HTTPS] dashboard sent in 1754 ms
  ```

- On the most recent one-client test, dashboard transfer was observed, then
  heap fluctuated around 48–70 KiB while `ws=0` persisted. This is the current
  unresolved state. It means the next AI should focus on why bootstrap/API
  activity holds both TLS client slots or why `startWs()` is not reached.

## Current board state

- Latest source was compiled and flashed successfully. Flash hash verification
  succeeded.
- The AP currently accepts one Wi-Fi station.
- At the last observed moment, one station was connected, dashboard was served,
  IMU nodes were active, but WSS stayed at `ws=0`.
- At the final handoff check, `/dev/cu.usbmodem101` was no longer present in
  the host OS. If serial access is needed, reconnect/power-cycle the USB board
  and re-check the port name before attempting another flash.
- A serial `screen` monitor may otherwise own the port. Before a flash, check
  with:

  ```sh
  lsof -t /dev/cu.usbmodem101
  ```

  and only terminate the exact listed `screen` process if necessary.

## Resolution: why `ws=0` was permanent

The rig was never the thing refusing the WebSocket. The dashboard never dialled
it in time — and in the bad case, never dialled it at all.

Four facts combine:

1. `dashboard/src/main.js` had moved `startWs()` behind
   `initialHydration.finally()`. Before this debug session it ran on the first
   line of bootstrap. So REST always went first.
2. `initAiModel()` runs at panel-init time, ahead of that hydration, and fired
   `api.modelGet()` — which streams the **~140 KB trained model** off the SD
   card through the TLS proxy — plus `api.modelsList()`.
3. `dashboard/src/api.js` keeps one serialized request lane on HTTPS. So the
   real boot order was: model (140 KB) → model list → status → nodes →
   sessions → *only then* `startWs()`. Every one of those is a separate TLS
   handshake, because each one-shot response closes its session; the observed
   handshake cost was around 1.7 s.
4. No request had a deadline. `fetch()` has no default timeout, so one stalled
   read wedged the lane for as long as the browser's own socket timeout —
   `initialHydration` never settled, `startWs()` was never called, and the
   badge stayed Offline for the life of the tab.

With two TLS client sockets, `lru_purge_enable = false` and a REST poll every
1.5 s, the WebSocket handshake also had no free slot to land in even when the
lane did drain. `tls=2/2 ws=0` is the exact fingerprint.

### What changed

- `dashboard/src/main.js` — `startWs()` runs first, before any REST. The REST
  lane opens when the stream reports `onopen`, or after a 4 s grace period so a
  rig that cannot stream still serves its nodes and sessions. Bootstrap reads
  moved inside that gate; secure-mode poll intervals relaxed from 1.5 s/2 s to
  3 s/5 s, since the time-critical data arrives over WSS anyway.
- `dashboard/src/api.js` — the lane starts closed on HTTPS and is opened by
  `openRequestLane()`. Every call now carries an `AbortController` deadline
  (15 s; 60 s for the model read, 120 s for a model upload), so no single
  request can wedge the queue.
- `dashboard/src/ws.js` — `onWsOpen(fn)` lets the bootstrap wait for the
  stream.
- `dashboard/src/aimodel.js` — the 140 KB model read is now
  `startAiModelLoad()`, called after hydration instead of at panel init.
- `dashboard/index.html` — `<link rel="icon" href="data:,">`. A phone otherwise
  asks for `/favicon.ico` during page load, costing a whole TLS handshake out
  of the two-client budget exactly when WSS needs a socket.
- `firmware/main-node/main-node.ino` — `[STATS]` now prints `tls=n/2` (TLS
  client sockets in use) and `iheap=` (free **internal** DRAM, the only memory
  a TLS handshake can use). This is the instrumentation the previous handoff
  asked for, without overriding `open_fn`/`close_fn` — `esp_https_server` sets
  those itself for the TLS transport and replacing them would break it.

### Second cause, found on the rig: REST sessions never freed the pool

The dashboard-side fix above was flashed and the rig then reported, steadily:

```text
[STATS] rx=36502 drop=0 wsdrop=0 nodes=2 wifi=1 ws=0 tls=2/2 sess=off sd=OK rows=0 heap=34472 iheap=34472
```

`rx` climbing means the radio is healthy; `tls=2/2` with `ws=0` means both TLS
client sockets were held by REST and no WebSocket handshake could land — with
`lru_purge_enable = false` there was nothing to break the deadlock, so it
persisted for as long as the phone stayed on the page. `Connection: close` plus
`httpd_sess_trigger_close()` was not enough on its own.

Eviction is therefore back on, with the stream protected properly this time:

- `config.httpd.lru_purge_enable = true`;
- `httpsTouchWsSession()` calls `httpd_sess_update_lru_counter()` on the WS
  socket at handshake and on **every** pushed IMU batch.

That inverts the failure that caused eviction to be switched off in the first
place. A server-push WebSocket receives nothing, so ESP-IDF's LRU bookkeeping
ages it like an idle socket and eviction kept choosing the stream; marking it
used on every push makes it permanently the newest entry, so the victim of a
full pool is always a REST session instead.

Measured on the rig, same phone, before and after that one change:

```text
before  tls=2/2  iheap=33168…50056   ws=0   (pool full, nothing can connect)
after   tls=1/2  iheap≈94000         ws=0   (one slot permanently free)
```

The freed slot is the one the WebSocket needs, and roughly 45 KiB of internal
DRAM came back with it. `httpd_sess_update_lru_counter()` is the documented way
to keep a chosen session alive "irrespective of when it last exchanged a
packet", which is exactly a server-push stream.

### Third cause: the phone was running a dashboard cached before the flash

In the same capture, `/api/status`, `/api/nodes`, `/api/logs` and `/api/models`
requests kept arriving — but **not one `[HTTPS] … dashboard` line**. The phone
never re-downloaded the page. Commit `35a1863` served it with
`Cache-Control: public, max-age=86400`, so a copy taken before the flash is
reused for up to a day without the browser asking the rig anything, and every
dashboard-side fix above was simply not present in the JavaScript that was
running.

Two changes so this stops being invisible:

- `dashboard/build-cpp.js` emits `#define DASHBOARD_BUILD_ID` from the
  `<meta name="ss-build">` stamp, and `/api/secure-status` now reports it as
  `build`.
- `checkFreshness()` no longer gives up on HTTPS. It compares `__BUILD_ID__`
  against that field — a few dozen bytes of JSON instead of a 400 KB document
  re-fetch — and offers the existing reload bar when they differ.

Until a phone has loaded a build containing that check, the stale copy has to be
displaced once. Clearing site data or adding a query string works, but both
depend on the coach winning an argument with Safari's autocomplete, and three
attempts to do it by hand left the request log still showing no dashboard fetch
at all. So the rig now serves the same document at a second path:

```text
https://pokoman.online/new
```

A different path is a different cache key, so that URL cannot be answered from a
cache entry created for `/`. It is a one-time bootstrap, not a permanent second
address — once a build carrying the `/api/secure-status` check has been loaded,
`/` self-corrects after every later flash.

**A stale dashboard is not a quiet failure.** Everything the coach reported —
"no SD card", "the model will not upload", "the nodes are silent" — came from
the old page while the rig itself logged `sd=OK`, accepted the model POST, and
counted about 90 IMU packets a second from two live nodes. The old page opens
more parallel connections than the two-socket pool allows, so with LRU eviction
now on, its own in-flight responses are the ones being cut. Check the build
stamp in the footer before believing any symptom the dashboard reports.

### Guard added: /api/model can take the rig into crash territory

Watching the request log, one route stands out:

```text
[HTTPS] fd=52 /api/model tls=2/2 iheap=49244
[STATS] rx=8942 … ws=0 tls=2/2 … heap=22140 iheap=22140
```

Streaming the ~140 KB trained model up from SD through the legacy server drops
internal DRAM to roughly 22 KiB — close to the pressure at which a Guru
Meditation was already seen once during this debug. `httpsProxyHandler()` now
refuses any proxied request while internal heap is under 32 KiB, answering
`503` instead. `loadInitialModel()` already treats a failed read as "no model on
the rig" and falls back to the browser's own cached copy, so the failure mode is
a retry rather than a reset.

Note this is a floor, not a fix for the cost itself: the read is expensive
because the whole model crosses the loopback proxy. Serving it straight from SD
through a native handler, the way `/mocap/*` assets are served, would avoid the
double handling entirely.

Added at the same time, to make the next round of evidence decisive:

- `[HTTPS] fd=<n> <what> tls=<n>/2 iheap=<bytes>` on every dashboard, `/api/*`,
  `/mocap/*` and WS-upgrade request. Absence of these lines while the badge
  says Offline means the phone is running a **cached** dashboard and is not
  asking the rig for anything — `freshness.js` deliberately skips its check on
  HTTPS, so that state does not self-correct without a hard reload.
- a warning if `httpd_sess_trigger_close()` itself returns an error.

### How to confirm on the rig

Watch the serial log while one phone opens `https://pokoman.online/`:

- `ws=1` should appear within a few seconds of the page loading, and stay.
- `tls=` should sit at `1/2` between polls and touch `2/2` only briefly.
- `iheap=` should settle rather than trend down.

`tls=2/2` with `ws=0` means REST is still winning the race; `tls=0/2` with
`ws=0` means the phone is not reaching the listener at all (name resolution,
Private DNS, or wrong host).

## Recommended next debugging steps

These were written before the cause above was found. Items 2, 3 and 4 are done
or superseded; the rest still stand.

1. **Confirm exactly one station** is connected to `StrikeSense`. Turn off Wi-Fi
   on every other phone/tablet/laptop, then reconnect the one test phone and
   open a single fresh `https://pokoman.online/` tab.

2. **Instrument HTTPS session lifecycle** before changing architecture again.
   Add temporary `open_fn` / `close_fn` callbacks to the native HTTPD config,
   logging socket fd, free internal heap, and current session count. This will
   show which requests occupy the two slots. Do not log private headers or
   certificate data.

3. **Instrument dashboard bootstrap** with local diagnostic events around:

   - `api.modelGet()`;
   - model library list;
   - status/nodes/sessions hydration;
   - `initialHydration.finally()`;
   - `startWs()` / WSS `onopen` / `onclose`.

   The immediate question is whether WSS is never attempted or is rejected.

4. If initial REST calls prevent WSS from being reached, consider a more robust
   startup sequence:

   - serve/force-close dashboard;
   - open WSS;
   - only then allow the permanent one-at-a-time REST lane;
   - defer optional model-library reads until WSS is live.

   Do not allow a third TLS client.

5. Verify `httpd_sess_trigger_close()` actually frees the document/API session
   after the handler returns. It queues a close operation; add a log of its
   return value and of the native session open/close callbacks.

6. Consider serving a shorter TLS chain only after verifying modern phone trust
   compatibility. The installed `fullchain.pem` has four certificates and may
   increase handshake memory. Do **not** replace it casually or include a root
   incorrectly; test any reduced chain on the actual phone first.

7. Keep the current traffic protections unless testing proves otherwise:

   - no Google/external resources;
   - exact-host DNS in secure mode;
   - one AP client;
   - two HTTPS client sessions maximum;
   - permanent serialized REST;
   - LRU purge disabled.

## Useful commands

Run from repository root:

```sh
# Browser/unit tests
(cd dashboard && npm test)

# Rebuild embedded dashboard after dashboard source edits
(cd dashboard && npm run build)

# Compile firmware
arduino-cli compile \
  --fqbn 'esp32:esp32:esp32s3:CDCOnBoot=cdc,FlashSize=8M,PartitionScheme=default_8MB,PSRAM=opi,UploadSpeed=921600' \
  firmware/main-node

# Flash (user authorized this workflow)
arduino-cli upload --port /dev/cu.usbmodem101 \
  --fqbn 'esp32:esp32:esp32s3:CDCOnBoot=cdc,FlashSize=8M,PartitionScheme=default_8MB,PSRAM=opi,UploadSpeed=921600' \
  firmware/main-node

# Attach serial monitor after freeing the port
TERM=xterm screen /dev/cu.usbmodem101 115200
```

## The SD card was mounting at the wrong clock

The reported "cannot record to the SD card" turned out to be literal, and it
took HTTPS down with it:

```text
[SD] mount ครั้งที่ 1 ไม่สำเร็จ — รอลอง...
[SD] mount ครั้งที่ 2 ไม่สำเร็จ — รอลอง...
[SD] mount ครั้งที่ 3 ไม่สำเร็จ — รอลอง...
[WARN] SD card unavailable - sessions will not be logged
[HTTPS] disabled: SD is unavailable (TLS PEM files are on SD)
```

All three attempts used the same 4 MHz SPI clock, and the SD SPI specification
asks for no more than 400 kHz until the card has answered — so a card that needs
the slow start had three identical chances to fail. `SdLogger::begin()` now
walks 400 kHz → 1 MHz → 4 MHz and waits 250 ms first for the card to settle
after power-up. On the next boot:

```text
[SD] OK at 400 kHz, 31 MB used of 60906 MB
[HTTPS] Listening on https://pokoman.online/ (cert SAN must match)
```

400 kHz is where it mounted, which is exactly the case the old code could not
reach. Two further changes stop one flaky mount from costing a whole session:

- `SdLogger::retryMount()` runs every 5 s while the card is missing, so it
  recovers without a power cycle;
- `WebServerApp::startSecureIfPossible()` brings the TLS listener up if the card
  — and with it the certificates — turns up late. `applyDnsPolicy()` was split
  out of `begin()` so the DNS mode follows.

A card that still drops intermittently after this is a contact or seating
problem, not a timing one.

## What is left before HTTPS can work

The three fixes above were real and each one measurably improved the rig, but
they were not enough, and the request log shows why. With the current dashboard
confirmed running on the phone (build stamp checked in the footer, one tab
open), the rig logged `/api/status`, `/api/nodes`, `/api/sessions` and
`/api/logs` arriving normally — and, over 35 seconds, **not one WebSocket
upgrade, TLS handshake error, or accept failure**. The phone also reported
`invalid legacy HTTP response`, which is the loopback proxy's 502 for "the
local HTTP server did not answer".

That points at the architecture rather than any single defect. Every secure API
call costs a TLS session (~47 KiB of internal DRAM, measured) *plus* an
ESPAsyncWebServer response buffer, because `/api/*` on :443 is proxied to the
legacy server on :80. On roughly 140 KiB of usable internal heap, two TLS
sessions leave the async server too little memory to build its reply, so the
proxy times out and returns 502 — which the dashboard renders as "no SD card",
"the model will not upload", and "the nodes are silent", none of which are true
of the hardware.

**The fix is to delete the proxy**, serving the `/api/*` handlers natively from
`esp_https_server` the way `/mocap/*` assets already are. That removes the
double memory cost, the 502 class entirely, and the dependency on
ESPAsyncWebServer being reachable at all. It is a substantial refactor of the 20
API routes, and it should be done before spending any more time on TLS tuning.

Also unexplained and worth instrumenting from the browser side first: why the
WebSocket produced no trace whatsoever at the rig. Read the WS-tagged lines in
the dashboard's own diagnostic console (developer mode, SYSTEM tab) before
assuming it is a server problem — the rig cannot see a connection the phone
never opened.

## Restore points

Created 2026-08-12, before the fix above:

- tag `backup-no-camera-http-20260812` and branch `backup/no-camera-http` —
  commit `35a1863`, the last committed system before the camera and HTTPS work
  (HTTP only, no `motioncapture.js`, no `esp_https_server`);
- a checked-out worktree of it at `~/Documents/GitHub/StrikeSense-no-camera`;
- tarballs of both that commit and the full pre-fix working tree, plus two
  compiled firmware images, under `~/Documents/GitHub/StrikeSense-backups/`
  (see the README there):
  - `firmware-no-camera-20260812/` — `35a1863` exactly as committed;
  - `firmware-http-newui-20260812/` — **what the board runs now**: the same
    HTTP firmware rebuilt with the current dashboard, so the UI and touch fixes
    made after that commit are included. Its one source change is the dashboard
    `Cache-Control`, now `no-cache, no-store, must-revalidate`.

Neither the tag nor the branch was pushed to `origin`.

## Repository hygiene

- The repository was already dirty before this work. Preserve unrelated user
  changes; do not reset/revert broadly.
- Relevant changed files include `firmware/main-node/main-node.ino`,
  `firmware/main-node/dashboard_ui.h`, `dashboard/index.html`,
  `dashboard/src/api.js`, `dashboard/src/main.js`, `dashboard/src/setup.js`,
  `dashboard/src/ws.js`, `dashboard/src/freshness.js`, and
  `dashboard/test/api.test.mjs`.
- `npm test` passed with 107 tests after the frontend traffic changes.
- `arduino-cli compile` passed after the latest firmware changes.

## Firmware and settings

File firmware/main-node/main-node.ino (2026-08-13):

// =============================================================================
// StrikeSense Main Node — single-file Arduino IDE sketch
// Target board : "ESP32S3 Dev Module"
// Settings     : Flash 8MB, PSRAM "OPI PSRAM", Partition "8M with spiffs (3MB
// APP)"
//                USB CDC On Boot: Enabled, Upload Speed 921600
//
// Required libraries (Library Manager):
//   - ESP Async WebServer  (mathieucarbou fork, v3.3+)
//   - Async TCP            (mathieucarbou fork)
//   - ArduinoJson          (Benoit Blanchon, v7.x)
//   - Adafruit NeoPixel
//
// Required board package:
//   - esp32 by Espressif Systems v3.1.x  (Boards Manager)
//
// Pipeline:
//   Strike Nodes (ESP-NOW) -> RX callback -> queue
//      -> main loop drains -> SD CSV logger + WebSocket broadcast + counters
//   Dashboard is embedded as PROGMEM HTML (no LittleFS upload required).
// =============================================================================

#include <Adafruit_NeoPixel.h>
#include <Arduino.h>
#include <ArduinoJson.h>
#include <esp_https_server.h>
#include <ESPAsyncWebServer.h>
#include <Preferences.h>
#include <SD.h>
#include <SPI.h>
#include <WiFi.h>
#include <DNSServer.h> // captive portal — จับ DNS ทุกโดเมน → AP IP
#include <esp_now.h>
#include <esp_wifi.h>
#include <time.h>

// esp_http_server and ESPAsyncWebServer both name their method enums HTTP_GET,
// etc.  Include the native header first (which tells ESPAsyncWebServer not to
// import its names globally), retain native constants under explicit names, and
// preserve the existing Async route source below with these narrow aliases.
static constexpr httpd_method_t IDF_HTTP_DELETE =
    static_cast<httpd_method_t>(HTTP_DELETE);
static constexpr httpd_method_t IDF_HTTP_GET = static_cast<httpd_method_t>(HTTP_GET);
static constexpr httpd_method_t IDF_HTTP_POST =
    static_cast<httpd_method_t>(HTTP_POST);
#define HTTP_DELETE AsyncWebRequestMethod::HTTP_DELETE
#define HTTP_GET AsyncWebRequestMethod::HTTP_GET
#define HTTP_POST AsyncWebRequestMethod::HTTP_POST

// ============================================================
//  CONFIG
// ============================================================
#define AP_SSID "StrikeSense"
#define AP_PASSWORD "muaythai123" // >= 8 chars
#define AP_CHANNEL 1              // MUST match STRIKESENSE_ESPNOW_CHANNEL
// TLS consumes roughly 50 KiB of scarce internal RAM per browser.  This rig's
// secure transport is intentionally one-coach-at-a-time: a second phone can
// otherwise consume the WSS/API pair and make both dashboards flap offline.
#define AP_MAX_CLIENTS 1

#define HTTP_PORT 80
#define HTTPS_PORT 443
#define WS_PATH "/ws"

// TLS material is deliberately provisioned on the SD card, never compiled into
// firmware or checked into source control.  The leaf certificate must contain
// a SAN for the address/name the phone opens.  With a public certificate use a
// DNS name in HTTPS_HOST_PATH; without it the legacy Local-CA IP setup remains
// available at 192.168.4.1.
#define HTTPS_CERT_PATH "/tls/server-cert.pem"
#define HTTPS_KEY_PATH "/tls/server-key.pem"
#define HTTPS_HOST_PATH "/tls/hostname.txt"
#define HTTPS_DEFAULT_HOST "192.168.4.1"

// Upper bound on live-stream clients. Only a backstop, NOT the zombie defence —
// see WebServerApp::loop(). Keep it well above the real client count: a phone
// routinely holds two pages at once (the captive-portal mini browser plus the
// real one), and each reconnect briefly adds another. A cap of 2 was tried and
// became a reconnect engine of its own: 2 legitimate pages + 1 reconnect tripped
// the cap every time, so cleanupClients() closed a *live* page, which reconnected,
// which tripped it again — 154 connections in two minutes.
#define MAX_WS_CLIENTS 6

#define SD_CS_PIN 10
#define SD_MOSI_PIN 11
#define SD_SCK_PIN 12
#define SD_MISO_PIN 13

// 4 Strike Nodes × 50 packets/s = 200 frames/s. 96 slots ≈ 0.5 s of headroom so
// a slow SD flush or a busy WiFi task never costs us samples. ~11 KB of heap.
#define IMU_QUEUE_SIZE 96
#define STATUS_LED_PIN 48

// Per-packet RX logging. Leave OFF: at 115200 baud one line per packet costs
// more serial bandwidth than exists once a second node joins, and the print
// happens in the ESP-NOW callback (WiFi task) — it blocks the radio and drops
// frames.
#define DEBUG_ESPNOW_RX 0

// ============================================================
//  PROTOCOL (shared with Strike Node firmware)
// ============================================================
#define STRIKESENSE_PROTOCOL_VERSION 1
#define STRIKESENSE_ESPNOW_CHANNEL 1
#define STRIKESENSE_SAMPLE_RATE_HZ 400
#define STRIKESENSE_SAMPLE_PERIOD_US 2500 // 1_000_000 / 400
#define IMU_SAMPLES_PER_PACKET 8

enum NodeSlot : uint8_t {
  SLOT_UNASSIGNED = 0,
  SLOT_LEFT_HAND = 1,
  SLOT_RIGHT_HAND = 2,
  SLOT_LEFT_SHIN = 3,
  SLOT_RIGHT_SHIN = 4,
};

enum PacketType : uint8_t {
  PKT_IMU_BATCH = 0x01,
  PKT_NODE_HELLO = 0x02,
  PKT_NODE_STATUS = 0x03,
  PKT_TIME_SYNC = 0x80,
  PKT_CMD_CONFIG = 0x81,
  PKT_CMD_IDENTIFY = 0x82,
  PKT_CMD_CALIBRATE = 0x83,
  PKT_CMD_RESTART = 0x84,
};

typedef struct __attribute__((packed)) {
  int16_t ax, ay, az;
  int16_t gx, gy, gz;
} ImuSample;

typedef struct __attribute__((packed)) {
  uint8_t version;
  uint8_t type;
  uint8_t reserved;
  uint8_t sampleCount;
  uint32_t seq;
  uint32_t firstTimestampUs;
  uint16_t samplePeriodUs;
  uint16_t reserved2;
  ImuSample samples[IMU_SAMPLES_PER_PACKET];
} ImuBatchPacket;

typedef struct __attribute__((packed)) {
  uint8_t version;
  uint8_t type;
  uint8_t firmwareMajor;
  uint8_t firmwareMinor;
  uint8_t macAddr[6];
} NodeHelloPacket;

typedef struct __attribute__((packed)) {
  uint8_t version;
  uint8_t type;
  uint8_t batteryPct;
  int8_t rssi;
  uint32_t uptimeMs;
  uint16_t lostPackets;
  uint16_t reserved;
} NodeStatusPacket;

typedef struct __attribute__((packed)) {
  uint8_t version;
  uint8_t type;
  uint8_t reserved[2];
  uint32_t mainNodeTimestampMs;
} TimeSyncPacket;

typedef struct __attribute__((packed)) {
  uint8_t version;
  uint8_t type;
  uint8_t newSampleRateHz;
  uint8_t accelRangeG;
  uint8_t gyroRangeDps;
  uint8_t reserved[3];
} ConfigCommandPacket;

typedef struct __attribute__((packed)) {
  uint8_t version;
  uint8_t type;
} SimpleCommandPacket;

// ============================================================
//  SHARED STRUCTS
// ============================================================
struct NodeMapping {
  uint8_t mac[6];
  NodeSlot slot;
  int8_t lastRssi;
  uint32_t lastSeenMs;
  uint8_t batteryPct;
  uint32_t nodeUptimeMs;
  uint16_t firmwareVersion;
  uint32_t packetsRx;
  uint32_t lastSeq;
  uint32_t seqGaps;
  float peakG; // most-recent frame peak |accel| (g) — powers shake-to-assign
  uint32_t lastImuMs; // when peakG was last updated
  bool active;
  bool everSeen; // false = restored from NVS, hasn't transmitted yet this boot
  uint16_t healthFlags; // from the node's status packet: bit0 sensor fault,
                        // bit1 link fault

  // Charge detection by voltage trend. There is no charge-sense wire fitted,
  // but a battery that is charging climbs and one in use falls — comparing the
  // reading against one taken CHARGE_WINDOW_MS ago tells the two apart without
  // any extra hardware.
  uint16_t battMv;    // latest reported millivolts (0 = node doesn't report)
  uint16_t battRefMv; // reading at the start of the current comparison window
  uint32_t battRefMs;
  int16_t battTrendMv; // signed change over the last completed window
  int8_t chargeState;  // +1 charging, -1 discharging, 0 unknown/steady
};

// Self-reported node health, packed into NodeStatusPacket.reserved by the
// Strike Node. Older node firmware sends 0, which reads as "healthy, no
// voltage" — so mixing firmware versions is safe and needs no protocol version
// bump.
//   bit0     sensor fault
//   bit1     link fault
//   bit2     battery sense not wired (reading is meaningless)
//   bit4-15  battery millivolts / 4
#define NODE_FLAG_SENSOR_FAULT 0x0001
#define NODE_FLAG_LINK_FAULT 0x0002
#define NODE_FLAG_BATT_UNWIRED 0x0004
#define NODE_BATT_MV_SHIFT 4

struct SessionStats {
  uint32_t startedAtMs;
  uint32_t endedAtMs;
  uint32_t totalImuPackets;
  uint32_t totalImuSamples;
  bool active;
};

struct ImuFrame {
  uint8_t mac[6];
  NodeSlot slot;
  int8_t rssi;
  uint32_t recvTimestampMs;
  uint32_t nodeTimestampUs;
  uint32_t seq;
  uint8_t sampleCount;
  ImuSample samples[IMU_SAMPLES_PER_PACKET];
};

// ============================================================
//  DIAGNOSTIC LOG  (dev mode)
// ============================================================
// A ring of recent events the dashboard can pull over /api/logs. Serial only
// helps with a laptop attached, which is exactly when problems DON'T happen —
// this is the same information, readable from the phone that is in the room.
// Written from three different tasks (WiFi/ESP-NOW, AsyncTCP, loop), so the
// ring is guarded; formatting happens outside the lock to keep it short.
namespace DiagLog {
static constexpr size_t CAP = 96;
static constexpr size_t MSG_LEN = 92;

struct Entry {
  uint32_t seq;
  uint32_t ms;
  char cat[10];
  char msg[MSG_LEN];
};

static Entry g_ring[CAP];
static size_t g_head = 0;  // next write slot
static uint32_t g_seq = 0; // monotonic, lets the client fetch deltas
static portMUX_TYPE g_mux = portMUX_INITIALIZER_UNLOCKED;
static bool g_echoSerial = true;

void add(const char *cat, const char *fmt, ...) {
  char msg[MSG_LEN];
  va_list ap;
  va_start(ap, fmt);
  vsnprintf(msg, sizeof(msg), fmt, ap);
  va_end(ap);

  const uint32_t nowMs = millis();
  taskENTER_CRITICAL(&g_mux);
  Entry &e = g_ring[g_head];
  e.seq = ++g_seq;
  e.ms = nowMs;
  strncpy(e.cat, cat, sizeof(e.cat) - 1);
  e.cat[sizeof(e.cat) - 1] = 0;
  memcpy(e.msg, msg, sizeof(e.msg));
  e.msg[sizeof(e.msg) - 1] = 0;
  g_head = (g_head + 1) % CAP;
  taskEXIT_CRITICAL(&g_mux);

  if (g_echoSerial)
    Serial.printf("[%s] %s\n", cat, msg);
}

uint32_t lastSeq() {
  taskENTER_CRITICAL(&g_mux);
  uint32_t s = g_seq;
  taskEXIT_CRITICAL(&g_mux);
  return s;
}

// Copies entries newer than `sinceSeq` (oldest first) into `out`.
size_t collect(Entry *out, size_t maxCount, uint32_t sinceSeq) {
  size_t n = 0;
  taskENTER_CRITICAL(&g_mux);
  for (size_t i = 0; i < CAP && n < maxCount; ++i) {
    const Entry &e = g_ring[(g_head + i) % CAP]; // oldest → newest
    if (e.seq > sinceSeq)
      out[n++] = e;
  }
  taskEXIT_CRITICAL(&g_mux);
  return n;
}
} // namespace DiagLog

#define DLOG(cat, ...) DiagLog::add(cat, __VA_ARGS__)

// ============================================================
//  EMBEDDED DASHBOARD (Premiere-Pro workspace, served from "/")
// ============================================================
#include "dashboard_ui.h"

// ============================================================
//  SESSION MODULE
// ============================================================
namespace Session {
static constexpr size_t MAX_NODES = 8;
static NodeMapping g_nodes[MAX_NODES];
static SessionStats g_stats = {};
static char g_sessionId[32] = "";
static char g_athleteName[32] = "";

// The node table is written from the ESP-NOW receive callback (WiFi task) and
// read from the HTTP/WS task. With a single node the overlap was rare enough to
// go unnoticed; with four it is constant, and an un-guarded read hands the
// dashboard a half-updated record. Every touch now runs under this spinlock.
static portMUX_TYPE g_mux = portMUX_INITIALIZER_UNLOCKED;

// Slot assignments live in NVS so a reboot, a power cut, or a flat battery does
// not throw away the shake-to-assign pairing. Wiped by the factory reset.
static Preferences g_prefs;
static bool g_prefsOk = false;
static bool g_setupDone = false;
static constexpr const char *NVS_NS = "strikesense";

typedef struct __attribute__((packed)) {
  uint8_t mac[6];
  uint8_t slot;
} PersistedNode;

static bool macEquals(const uint8_t *a, const uint8_t *b) {
  for (int i = 0; i < 6; ++i)
    if (a[i] != b[i])
      return false;
  return true;
}
static int findNode(const uint8_t *mac) {
  for (size_t i = 0; i < MAX_NODES; ++i) {
    if (g_nodes[i].active && macEquals(g_nodes[i].mac, mac))
      return (int)i;
  }
  return -1;
}
static int findFreeSlot() {
  for (size_t i = 0; i < MAX_NODES; ++i)
    if (!g_nodes[i].active)
      return (int)i;
  // Table full: evict an entry that was restored from NVS but has not shown up
  // this boot, so a genuinely new sensor can still join a full-looking rig.
  for (size_t i = 0; i < MAX_NODES; ++i)
    if (!g_nodes[i].everSeen)
      return (int)i;
  return -1;
}

// NVS writes must happen outside the spinlock — snapshot first, then persist.
static void saveMappings() {
  if (!g_prefsOk)
    return;
  PersistedNode buf[MAX_NODES];
  size_t n = 0;
  taskENTER_CRITICAL(&g_mux);
  for (size_t i = 0; i < MAX_NODES; ++i) {
    if (!g_nodes[i].active)
      continue;
    memcpy(buf[n].mac, g_nodes[i].mac, 6);
    buf[n].slot = (uint8_t)g_nodes[i].slot;
    n++;
  }
  taskEXIT_CRITICAL(&g_mux);
  if (n)
    g_prefs.putBytes("nodes", buf, n * sizeof(PersistedNode));
  else
    g_prefs.remove("nodes");
}

static void loadMappings() {
  g_prefsOk = g_prefs.begin(NVS_NS, false);
  if (!g_prefsOk) {
    DLOG("NVS", "เปิด NVS ไม่ได้ — การจับคู่จะหายเมื่อรีบูต");
    return;
  }
  g_setupDone = g_prefs.getBool("setup", false);

  PersistedNode buf[MAX_NODES];
  size_t len = g_prefs.getBytesLength("nodes");
  if (len == 0 || len > sizeof(buf) || (len % sizeof(PersistedNode)) != 0)
    return;
  g_prefs.getBytes("nodes", buf, len);
  const size_t n = len / sizeof(PersistedNode);
  for (size_t i = 0; i < n && i < MAX_NODES; ++i) {
    g_nodes[i] = {};
    memcpy(g_nodes[i].mac, buf[i].mac, 6);
    g_nodes[i].slot = (NodeSlot)buf[i].slot;
    g_nodes[i].active = true;
    g_nodes[i].everSeen = false; // shows as offline until it transmits
  }
  DLOG("NVS", "กู้คืนการจับคู่ %u ตัว · setupDone=%d", (unsigned)n, (int)g_setupDone);
}

void begin() {
  for (auto &n : g_nodes)
    n = {};
  g_stats = {};
  loadMappings();
}

bool setupDone() { return g_setupDone; }
void setSetupDone(bool done) {
  g_setupDone = done;
  if (g_prefsOk)
    g_prefs.putBool("setup", done);
}

// "Brand new device": drop every pairing and re-arm the first-run wizard.
void factoryResetMemory() {
  taskENTER_CRITICAL(&g_mux);
  for (auto &n : g_nodes)
    n = {};
  taskEXIT_CRITICAL(&g_mux);
  g_setupDone = false;
  if (g_prefsOk)
    g_prefs.clear();
}

bool start(const char *athleteName) {
  if (g_stats.active)
    return false;
  g_stats = {};
  g_stats.active = true;
  g_stats.startedAtMs = millis();
  strncpy(g_athleteName, athleteName ? athleteName : "anonymous",
          sizeof(g_athleteName) - 1);
  snprintf(g_sessionId, sizeof(g_sessionId), "%lu",
           (unsigned long)g_stats.startedAtMs);
  return true;
}

bool stop() {
  if (!g_stats.active)
    return false;
  g_stats.active = false;
  g_stats.endedAtMs = millis();
  return true;
}

bool isActive() { return g_stats.active; }
const SessionStats &stats() { return g_stats; }
const char *currentSessionId() { return g_sessionId; }

// Returns true when the node was not in the table before (i.e. a genuinely new
// sensor just joined) so the caller can log it once instead of per packet.
bool rememberNode(const uint8_t *mac, int8_t rssi) {
  bool isNew = false;
  taskENTER_CRITICAL(&g_mux);
  int idx = findNode(mac);
  if (idx < 0) {
    idx = findFreeSlot();
    if (idx >= 0) {
      g_nodes[idx] = {};
      memcpy(g_nodes[idx].mac, mac, 6);
      g_nodes[idx].slot = SLOT_UNASSIGNED;
      g_nodes[idx].active = true;
      isNew = true;
    }
  } else if (!g_nodes[idx].everSeen) {
    isNew = true; // restored from NVS, first packet this boot
  }
  if (idx >= 0) {
    g_nodes[idx].lastRssi = rssi;
    g_nodes[idx].lastSeenMs = millis();
    g_nodes[idx].everSeen = true;
  }
  taskEXIT_CRITICAL(&g_mux);
  return isNew;
}

// Live per-node activity (peak |accel|, g) — drives shake-to-assign in the
// first-run setup wizard so we can tell which physical node is being shaken.
void noteActivity(const uint8_t *mac, float peakG) {
  taskENTER_CRITICAL(&g_mux);
  int idx = findNode(mac);
  if (idx >= 0) {
    g_nodes[idx].peakG = peakG;
    g_nodes[idx].lastImuMs = millis();
  }
  taskEXIT_CRITICAL(&g_mux);
}

void countImuPacket(const uint8_t *mac, uint32_t seq) {
  taskENTER_CRITICAL(&g_mux);
  int idx = findNode(mac);
  if (idx >= 0) {
    g_nodes[idx].packetsRx++;
    if (g_nodes[idx].lastSeq != 0 && seq > g_nodes[idx].lastSeq + 1) {
      g_nodes[idx].seqGaps += (seq - g_nodes[idx].lastSeq - 1);
    }
    g_nodes[idx].lastSeq = seq;
  }
  taskEXIT_CRITICAL(&g_mux);
}

// Voltage must move by more than the ADC's own noise before we call it a
// trend — a couple of mV of jitter must not flicker the charging icon.
static constexpr uint32_t CHARGE_WINDOW_MS = 20000;
static constexpr int16_t CHARGE_DELTA_MV = 15;

void updateNodeStatus(const uint8_t *mac, uint8_t batteryPct, uint32_t uptimeMs,
                      uint16_t healthFlags, uint16_t battMv) {
  int8_t prevCharge = 0, newCharge = 0;
  int16_t trend = 0;
  bool changed = false;
  char macStr[18] = "";

  taskENTER_CRITICAL(&g_mux);
  int idx = findNode(mac);
  if (idx >= 0) {
    NodeMapping &n = g_nodes[idx];
    n.batteryPct = batteryPct;
    n.nodeUptimeMs = uptimeMs;
    n.healthFlags = healthFlags;
    n.battMv = battMv;

    if (battMv == 0) { // node isn't reporting volts
      n.chargeState = 0;
      n.battRefMs = 0;
      n.battTrendMv = 0;
    } else if (n.battRefMs == 0) {
      n.battRefMv = battMv;
      n.battRefMs = millis();
    } else if (millis() - n.battRefMs >= CHARGE_WINDOW_MS) {
      trend = (int16_t)battMv - (int16_t)n.battRefMv;
      prevCharge = n.chargeState;
      newCharge = (trend >= CHARGE_DELTA_MV)    ? 1
                  : (trend <= -CHARGE_DELTA_MV) ? -1
                                                : 0;
      n.battTrendMv = trend;
      n.chargeState = newCharge;
      n.battRefMv = battMv;
      n.battRefMs = millis();
      changed = (prevCharge != newCharge);
      if (changed) {
        snprintf(macStr, sizeof(macStr), "%02X:%02X:%02X:%02X:%02X:%02X",
                 mac[0], mac[1], mac[2], mac[3], mac[4], mac[5]);
      }
    }
  }
  taskEXIT_CRITICAL(&g_mux);

  if (changed) { // log outside the lock
    DLOG("BATT", "%s %s (%+d mV/%lus, %u mV)", macStr + 12,
         newCharge > 0   ? "กำลังชาร์จ"
         : newCharge < 0 ? "กำลังใช้ไฟ"
                         : "นิ่ง",
         (int)trend, (unsigned long)(CHARGE_WINDOW_MS / 1000), battMv);
  }
}
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
void loop() {
  retrySdMount();

  ImuFrame frame;
  int drained = 0;

  // While a page is being delivered, give the document EVERYTHING.
  //
  // Four Strike Nodes put ~200 ESP-NOW frames a second through the same radio
  // the SoftAP is trying to send a 55 KB document over. Silencing only the
  // WebSocket left the CPU still parsing every one of those frames, still
  // writing the SD card, and still handing them to the TCP stack — so the page
  // load kept losing the race. Here the whole pipeline stands down: frames are
  // drained and thrown away (they are live telemetry; a second of it is worth
  // less than the page loading at all) and nothing touches the card.
  if (WebServerApp::streamIsQuiet()) {
    while (drained < 64 && EspNowRx::nextFrame(frame, 0))
      drained++;
    WebServerApp::loop();
    StatusLed::tick();
    delay(2);
    return;
  }
  // Block on the queue for the first frame instead of spinning + delay(2): when
  // no sensor is transmitting the loop task now sleeps rather than burning a
  // core, which leaves the WiFi and AsyncTCP tasks room to breathe. Subsequent
  // reads are non-blocking so a burst drains in one pass.
  while (drained < 32 &&
         EspNowRx::nextFrame(frame, drained == 0 ? pdMS_TO_TICKS(4) : 0)) {
    Session::noteImuFrame(frame.sampleCount);
    // per-node peak |accel| (g) for shake-to-assign
    float pk = 0.0f;
    for (uint8_t i = 0; i < frame.sampleCount; ++i) {
      const float ax = frame.samples[i].ax / 2048.0f;
      const float ay = frame.samples[i].ay / 2048.0f;
      const float az = frame.samples[i].az / 2048.0f;
      const float m = sqrtf(ax * ax + ay * ay + az * az);
      if (m > pk)
        pk = m;
    }
    Session::noteActivity(frame.mac, pk);
    if (Session::isActive())
      SdLogger::logFrame(frame);
    WebServerApp::broadcastImuFrame(frame);
    drained++;
  }

  // Log a joining node once, from here — never from the RX callback.
  uint8_t newMac[6];
  if (EspNowRx::takeNewNodeNotice(newMac)) {
    DLOG("NODE", "เข้าร่วม %02X:%02X:%02X:%02X:%02X:%02X (ออนไลน์ %u ตัว)",
         newMac[0], newMac[1], newMac[2], newMac[3], newMac[4], newMac[5],
         (unsigned)Session::liveNodeCount(3000));
  }

  // Periodic health snapshot — the baseline that makes an anomaly obvious when
  // reading the log back after something went wrong.
  static uint32_t lastHealthLogMs = 0;
  const uint32_t nowMs = millis();
  if (nowMs - lastHealthLogMs >= 15000) {
    lastHealthLogMs = nowMs;
    DLOG("SYS",
         "โหนด %u · wifi %u · ws %u · rx %lu drop %lu · wsdrop %lu quiet %lu · heap %lu",
         (unsigned)Session::liveNodeCount(3000),
         (unsigned)WiFi.softAPgetStationNum(),
         (unsigned)WebServerApp::connectedClients(),
         (unsigned long)EspNowRx::packetsReceived(),
         (unsigned long)EspNowRx::packetsDropped(),
         (unsigned long)WebServerApp::wsDropped(),
         (unsigned long)WebServerApp::quietDrops(),
         (unsigned long)ESP.getFreeHeap());
  }

  WebServerApp::loop();
  EspNowTx::tick();
  SdLogger::tick();
  StatusLed::setState(pickLedState());
  StatusLed::tick();
  logStats();
}

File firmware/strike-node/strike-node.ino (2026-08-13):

#include "../shared/protocol.h"
#include <Arduino.h>
#include <WiFi.h>
#include <Wire.h>
#include <esp_now.h>
#include <esp_timer.h>
#include <esp_wifi.h>
#include <esp_sleep.h>   // deep sleep + GPIO wakeup สำหรับปุ่ม power

// --- Configuration ---
#define I2C_SDA_PIN 8
#define I2C_SCL_PIN 9
#define I2C_FREQ 400000

#define BMI160_ADDR 0x69 // Default for DFRobot/Bosch, could be 0x68
#define LED_PIN 2

// ─────────────────────────────────────────────────────────────
// FEATURE FLAGS — เปิดเป็น 1 "เฉพาะเมื่อต่อวงจรขานั้นจริงแล้ว"
//   ⚠ ถ้าเปิดทั้งที่ยังไม่ต่อวงจร ขาจะลอย (floating) → อ่านค่ามั่ว
//      โดยเฉพาะ charge-detect: ขาลอยอาจอ่าน HIGH เอง → node หลับทันที
//      อาการ "เชื่อมแปบเดียวแล้วหลุด" = ขา GPIO5 ลอยแล้วเข้าใจว่ากำลังชาร์จ
// ─────────────────────────────────────────────────────────────
#define ENABLE_CHARGE_DETECT  0   // 0 = โหมด A (ตื่นตลอด · dashboard โชว์ชาร์จจากเทรนด์แรงดัน · แบตพึ่ง protection IC ของ TP4056) · 1 = pause/sleep ตอนชาร์จ (GPIO5 ต่อแล้วทุกบอร์ด แต่ต้อง validate ให้อ่านนิ่งก่อน)
#define ENABLE_BATTERY        1   // 1 = อ่านแบตจริงจาก GPIO4 · 0 = ส่ง 100% ตายตัว

// ⚠ แยกออกจาก ENABLE_BATTERY โดยตั้งใจ!
// การ "อ่านค่าแบตมาโชว์" ปลอดภัยเสมอ แต่การ "ตัดไฟเข้า deep sleep" อันตราย:
// ถ้ายังไม่ได้ต่อ divider ที่ GPIO4 ขาจะลอย อ่านได้ค่ามั่วต่ำๆ แล้วโหนดจะหลับถาวร
// (ไม่มี wake source เมื่อ ENABLE_CHARGE_DETECT=0) = ต้องถอดแบตมาเสียบใหม่ทุกตัว
// เปิดเป็น 1 ได้ต่อเมื่อวัดแล้วว่าค่าแบตที่อ่านได้ตรงกับมัลติมิเตอร์จริง
#define ENABLE_LOW_BATT_CUTOFF 0

// ช่วงแรงดันที่ "เป็นไปได้จริง" สำหรับ Li-ion ผ่าน divider /2
// อ่านได้นอกช่วงนี้ = ยังไม่ได้ต่อ divider / ขาลอย → รายงานว่าอ่านไม่ได้ ไม่เดาเป็น %
// (ต่ำกว่า 2.7V เป็นไปไม่ได้ตอนบอร์ดยังทำงานอยู่ เพราะ ESP32-C3 ดับไปก่อนแล้ว)
#define BAT_PLAUSIBLE_MIN_V  2.70f
#define BAT_PLAUSIBLE_MAX_V  4.60f

// กำลังส่ง ESP-NOW (หน่วย 0.25 dBm) — ปรับที่เดียวจบ ดูคำอธิบายที่จุดเรียกใช้
#define ESPNOW_TX_POWER  68
// พิมพ์ค่าแบตทุกกี่มิลลิวินาที — เดิมพิมพ์ทุก 1 วิ กินเวลา loop เปล่าๆ
#define BATT_LOG_MS      10000

// โหมดตอนชาร์จ:  1 = ดับจริง (deep sleep, ตื่นตอนถอดสาย)  ·  0 = pause (หยุดส่งแต่ไม่หลับ)
// ⚠ deep sleep: USB/COM จะหลุดตอนหลับ (ปกติ) → ทดสอบด้วยแบต ดูผลผ่าน dashboard
// ⚠ ต้องแก้ฮาร์ดแวร์ให้ IN+ คายประจุเร็ว (divider 10k/15k) ไม่งั้น "ถอดแล้วไม่ตื่น"
#define CHARGE_DEEP_SLEEP     0   // 0 = pause (ไม่หลับ USB ไม่หลุด เหมาะ dev) · 1 = deep sleep (เฉพาะใช้แบตจริง)

// --- Battery ADC ---
// วงจร: BAT+ ─ R1(100kΩ) ─ GPIO4 ─ R2(100kΩ) ─ GND   (+ cap 100nF จาก GPIO4 → GND กัน noise)
// Vout = Vbatt / 2  →  Vbatt=4.2V จะได้ 2.1V เข้า ADC (ปลอดภัยต่อชิป 3.3V)
// ── เลือกขาวัดแบตอัตโนมัติ ─────────────────────────────────────────
// บอร์ดชุดนี้ต่อวงจรวัดแบตไม่เหมือนกันทุกตัว (บางตัวต่อ GPIO4 บางตัวยังไม่ต่อ
// บางตัวย้ายไปขาอื่น) การล็อกขาเดียวในเฟิร์มแวร์จึงต้องแยก build ต่อบอร์ด
// แทนที่จะทำแบบนั้น ให้เฟิร์มแวร์ไล่หาขาที่ "อ่านแล้วสมเหตุสมผลจริง" เอง
//
// ⚠ ใช้ได้เฉพาะ ADC1 เท่านั้น = GPIO0–GPIO4 บน ESP32-C3
//   (ADC2 อ่านไม่ได้เลยเมื่อเปิด WiFi — ขา GPIO5 จึงใช้ไม่ได้)
//   ตัด GPIO2 ออกเพราะเป็นขา LED · GPIO8/9 เป็น I2C ของ BMI160
//   เรียง GPIO4 ไว้แรกเพื่อให้บอร์ดที่ต่อไว้เดิมทำงานเหมือนเดิม
#define BAT_PIN_CANDIDATES  { 4, 1, 0 }   // ⚠ ตัด GPIO3 ออก — สงวนไว้เป็นขา motion INT (MOTION_INT_PIN)

#define BAT_RESCAN_MS       30000   // ยังหาไม่เจอ → ไล่หาใหม่ทุก 30 วิ (เผื่อเพิ่งเสียบแบต)

static const uint8_t BAT_PINS[] = BAT_PIN_CANDIDATES;
static const size_t  BAT_PIN_N  = sizeof(BAT_PINS) / sizeof(BAT_PINS[0]);
static int8_t   g_batPin       = -1;    // -1 = ยังหาไม่เจอ
static uint32_t g_batScanMs    = 0;
#define BAT_DIV_RATIO  2.0f   // R1=R2 → แรงดันถูกหารสอง ต้องคูณกลับ
#define BAT_SAMPLES    8      // จำนวน ADC reads ที่เฉลี่ยต่อครั้ง (ลด noise)
#define BAT_EMA_ALPHA  0.2f   // น้ำหนัก smoothing (ยิ่งน้อยยิ่งนิ่ง 0.2 = นิ่งปานกลาง)

// ตัดไฟกันแบตเสื่อม (over-discharge protection ฝั่ง firmware) — ทำงานเมื่อ ENABLE_BATTERY=1
#define LOW_BATT_CUTOFF_V  3.30f   // แบตต่ำกว่านี้ (V) = ตัดไฟเข้า deep sleep
#define LOW_BATT_HOLD_MS   5000    // ต้องต่ำต่อเนื่องเท่านี้ (ms) ถึงตัด — กัน TX spike หลอก

// --- Charge detect แบบ IN+ sense (auto power-off ตอนเสียบสายชาร์จ) ---
// ตรวจว่ามีไฟ 5V เข้า IN+ ของ TP4056 หรือไม่ (= เสียบสาย/คาแท่นชาร์จอยู่)
// ต้องมี voltage divider กันไฟ 5V:  IN+ ─R1(100kΩ)─ GPIO5 ─R2(150kΩ)─ GND
//   เสียบสาย → GPIO5 ≈ 3.0V (HIGH ชัดเจน) · ถอดสาย → ~0V (LOW)
// ⚠ R2=150kΩ (ไม่ใช่ 100k) เพื่อให้ได้ 3.0V ไม่ใช่ 2.5V ที่ก้ำกึ่งกับ threshold
// ⚠ ต้องใช้ GPIO0–GPIO5 เท่านั้น! เพราะ ESP32-C3 ปลุกจาก deep sleep ได้เฉพาะขากลุ่มนี้
//   (ถ้าใช้ GPIO10 จะ "ถอดสายแล้วไม่ตื่นเอง" เพราะปลุกไม่ได้)
// ⚠ ใช้ INPUT ธรรมดา (ไม่เปิด pull-up) เพราะ divider เป็นตัวกำหนดระดับเอง
#define CHG_SENSE_PIN  5      // GPIO5 (wake-capable · รับจากจุดกลาง divider ของ IN+)
#define CHG_HOLD_MS    1500   // เห็นไฟเข้าต่อเนื่องเท่านี้ (ms) ถึงจะดับ (กัน noise/แวบ)

// BMI160 Registers
#define BMI160_REG_CHIPID 0x00
#define BMI160_REG_PMU_CMD 0x7E
#define BMI160_REG_ACC_CONF 0x40
#define BMI160_REG_GYR_CONF 0x42
#define BMI160_REG_ACC_RANG 0x41
#define BMI160_REG_GYR_RANG 0x43
#define BMI160_REG_DATA 0x0C // GYR_X_L

// ── Wake-on-motion (Phase 1) ────────────────────────────────
// BMX160 มี any-motion interrupt ในตัว → ใช้ปลุก ESP32 ตอนหลับ
//   step 1a (MOTION_DEEP_SLEEP=0): config + อ่าน INT_STATUS ทาง I2C มาพิมพ์
//        ยืนยันว่าเซนเซอร์จับการเคลื่อนไหวได้ — ยังไม่ต้องต่อสาย INT1 · ไม่หลับ (ปลอดภัย)
//   step 1b (MOTION_DEEP_SLEEP=1): ต่อสาย INT1 → GPIO3 แล้วเปิด deep sleep + wake
#define ENABLE_MOTION_WAKE  1      // 1 = เปิด any-motion detect
#define MOTION_DEEP_SLEEP   1      // 0 = แค่ตรวจ+พิมพ์ (เช็ก INT1) · 1 = หลับจริง (production)
#define MOTION_INT_PIN      3      // GPIO3 (wake-capable) รับ INT1 จาก BMX160
#define MOTION_IDLE_MS      300000 // นิ่งเกินเท่านี้ (ms) → หลับ · 300000 = 5 นาที (production · กันหลับกลางยก/พักคอมโบ)
#define MOTION_THRESH       0x08   // any-motion threshold · ±16g: 1 LSB≈31mg → 0x08≈250mg (ปรับได้)
#define MOTION_DUR          0x00   // จำนวน sample เกิน threshold ก่อนยิง (bits1:0 · 0=1 sample ไวสุด)
#define MOTION_VERBOSE      0      // 1 = พิมพ์ GPIO3/I2C ทุกวินาที (สำหรับเช็ก INT1 โหนดใหม่) · production=0

// BMX160/BMI160 interrupt registers (สำหรับ any-motion)
#define BMX_REG_INT_STATUS0  0x1C  // bit2 = any-motion
#define BMX_REG_INT_EN0      0x50  // bit0-2 = anymotion x/y/z enable
#define BMX_REG_INT_OUT_CTRL 0x53  // INT1 output/level/mode
#define BMX_REG_INT_LATCH    0x54  // latch mode
#define BMX_REG_INT_MAP0     0x55  // bit2 = map anymotion → INT1
#define BMX_REG_INT_MAP2     0x57  // bit2 = map anymotion → INT2
#define BMX_REG_INT_MOTION0  0x5F  // anymotion duration (bits1:0)
#define BMX_REG_INT_MOTION1  0x60  // anymotion threshold (8-bit)

uint32_t lastMotionMs = 0;   // เวลาตรวจพบการเคลื่อนไหวล่าสุด (feeds idle-sleep ตอน step 1b)
volatile bool g_intSeenHigh = false;  // fast-poll: GPIO3(INT) เคยขึ้น HIGH ในรอบล่าสุดไหม
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

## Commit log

2026-05-23 Add terms and conditions section to README
    Added terms and conditions for the prototype project, including accuracy, modifications, and intellectual property rights.
2026-07-09 Add AI training data logger UI and initial ML pipeline script
    Adds a Data Collection Mode panel to the dashboard for coaches to
    label strikes, record IMU streams, and export CSV for the 1D-CNN
    training pipeline, plus a starter TensorFlow training script.
2026-07-24 fix(main-node): stop WS OFFLINE/LIVE flapping with 4 nodes
    At 4 strike nodes the aggregate IMU stream is ~200 WS msg/s (400Hz / 8
    samples x4). broadcastImuFrame() queued every frame with no backpressure,
    so when the single dashboard client couldn't drain over WiFi the send
    path overloaded (buffer/heap churn + AsyncTCP) and reset the socket —
    making the dashboard flap OFFLINE<->LIVE.
    Guard the broadcast with availableForWriteAll() (the library-recommended
    backpressure check): skip the frame while the client queue is full and
    let it drain. IMU frames are real-time, so dropping a frame under
    saturation is cheaper than losing the connection. Track dropped frames
    in a wsDropped counter, expose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
    [main-node.ino]
2026-07-25 feat(ai): in-browser gesture detection from an uploadable trained model
    Adds an end-to-end path to use a trained model without reflashing per model:
    train -> export strike_web_model.json -> upload in the dashboard -> live
    technique classification on the IMU stream.
    Dashboard (runs fully offline, no TensorFlow.js):
    - ainet.js: dependency-free 1D-CNN forward pass (conv1d same/valid, batchnorm,
    maxpool1d, global-avg-pool, dense, softmax) — verified numerically against
    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
2026-07-31 feat: mobile stability, live sensor, SD-stored AI model, Thai UI
    1. Mobile/WebSocket stability + load time
    - Serve the dashboard gzip-compressed (157 KB → 44 KB) with Content-Encoding
    header — far faster first paint on the SoftAP, and firmware flash usage
    drops from 38% → 32%.
    - ws.js: guard against duplicate sockets, reconnect immediately on
    visibilitychange/online/focus/pageshow (phones suspend sockets on lock),
    lower reconnect backoff cap.
    - Debounce the connection pill (1.2s grace → steady amber "reconnecting")
    so brief blips no longer flicker green↔red.
    2. Always-on live sensor readout
    - New topbar "แรง G" indicator + state.liveActiv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
    [main-node.ino]
2026-07-31 fix(dashboard): live-G readout sawtoothed 1→0 at rest
    The topbar live sensor and per-node mixer showed a decaying peak-hold of the
    raw acceleration magnitude. A stationary node reads a constant 1 g (gravity),
    so the peak-hold faded 1.0→0 then re-armed to 1.0 — a 1→0→1 sawtooth that
    looked like a node fault. The accelerometer and strike-node firmware were fine.
    Show instantaneous gravity-removed |a| (max(0, |a|-1)) instead: steady ~0 at
    rest, spikes on impact, no sawtooth. state.liveActivity now tracks curG; the
    mixer number reads live.curG. Strike detection/threshold (total-G) unchanged.
2026-07-31 feat(main-node): resilient nodes, shake-to-assign setup, calibration UX
    1. Live-G sawtooth (already fixed in prior commit) ships here via rebuilt
    dashboard_ui.h — sensor readout is steady at rest, no 1→0 cycling.
    2. Signal-drop resilience: cleanStaleNodes no longer deletes dropped nodes or
    clears their slot — they stay in the list marked offline and reconnect to the
    same limb automatically. Added POST /api/nodes/forget for explicit removal,
    a "🔄 ค้นหาใหม่" rescan button, and a per-offline-node "ลืมอุปกรณ์" button.
    3. Calibration UX: reject a take if the node moved during capture
    (accel-magnitude std > 0.18 g) with a clear Thai r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
    [main-node.ino]
2026-08-04 feat: implement session replay functionality and add new ML training datasets
    [strike_10_1785677332444.csv, strike_10_1785680752096.csv, strike_11_1785680828026.csv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]
2026-08-07 feat(firmware): power management — wake-on-motion + button sleep
    Strike Node (ESP32-C3):
    - BMX160/BMI160 any-motion interrupt (INT1 -> GPIO3) wakes from deep sleep
    - Auto-sleep after 5 min idle, wake on movement (acts as a virtual power
    button; also handles charging: on charger = still = sleeps efficiently)
    - GPIO3 removed from battery ADC candidates (now dedicated to motion INT)
    - ENABLE_MOTION_WAKE / MOTION_DEEP_SLEEP / MOTION_VERBOSE flags for rollout
    Main Node (ESP32-S3):
    - Momentary button on GPIO4: long-press -> deep sleep, press -> wake (ext0)
    - Waits for button release before sleeping (avoids instant re-wake)
    - Auto-idle sleep (10 min with no clients / session / live nodes)
    - Tu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
    [ap-test.ino, bmi160-test.ino, bmx160-read.ino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]
2026-08-08 feat(main-node): captive portal + live-stream downsample; drop sleep/button
    - captive portal: DNS catch-all (ทุกโดเมน→192.168.4.1) + onNotFound redirect
    → มือถือเด้ง dashboard เองแทนที่จะค้างตอนเช็กเน็ต (แก้อาการโหลดช้า/ไม่ขึ้น)
    - WS live stream: downsample 1-in-4 ลดโหลด SoftAP + wsdrop ที่ทำให้สถานะ
    LIVE/OFFLINE กระพริบตอนต่อ 4 โหนด (SD ยังบันทึกครบ 400Hz)
    - gate ESP-NOW RX ปิดเมื่อไม่มี client/session (ประหยัด CPU/ว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
2026-08-08 feat(main-node): AI model library (view/select/delete) + live latency & portal fixes
    Model library — จัดการโมเดล AI หลายไฟล์ เลือกตัวที่ใช้ได้:
    - SD /models/ เก็บหลายโมเดล · active จำใน _active.txt · GET /api/models (list),
    POST /api/models?name= (upload→ใช้ทันที), POST /api/models/activate, DELETE
    /api/models?name= · GET /api/model ยังคืนตัว active ให้ dashboard auto-load ·
    โมเดลเดิม /model.json ย้ายเข้าคลังตอน boot · factory-reset wipeModel เคลียร์คลัง
    - Dashboar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
    [main-node.ino]
2026-08-08 update stop bug connection main node
    [main-node.ino]
2026-08-09 Add test for detector parity between Python and JavaScript implementations
    This commit introduces a new test script `test_detector_parity.py` that verifies the consistency of window end calculations between the Python function `_impacts()` in `train_model.py` and the JavaSc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
    [strike_10_1786182181368.csv, strike_10_1786193842369.csv, strike_10_1786193909823.csv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]
2026-08-11 feat: implement phone-camera motion capture pipeline with MediaPipe integration and impact timestamp fusion
    [partitions.csv, strike_10_1784875372219.csv, strike_13_1786377779272.csv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]
2026-08-13 feat: implement SD mount auto-retry and transition to WebSocket-based state streaming to preserve TLS capacity.
2026-08-13 docs: update all documentation files to reflect current codebase
2026-08-13 docs: note Motion Capture camera feature as currently unavailable in docs
